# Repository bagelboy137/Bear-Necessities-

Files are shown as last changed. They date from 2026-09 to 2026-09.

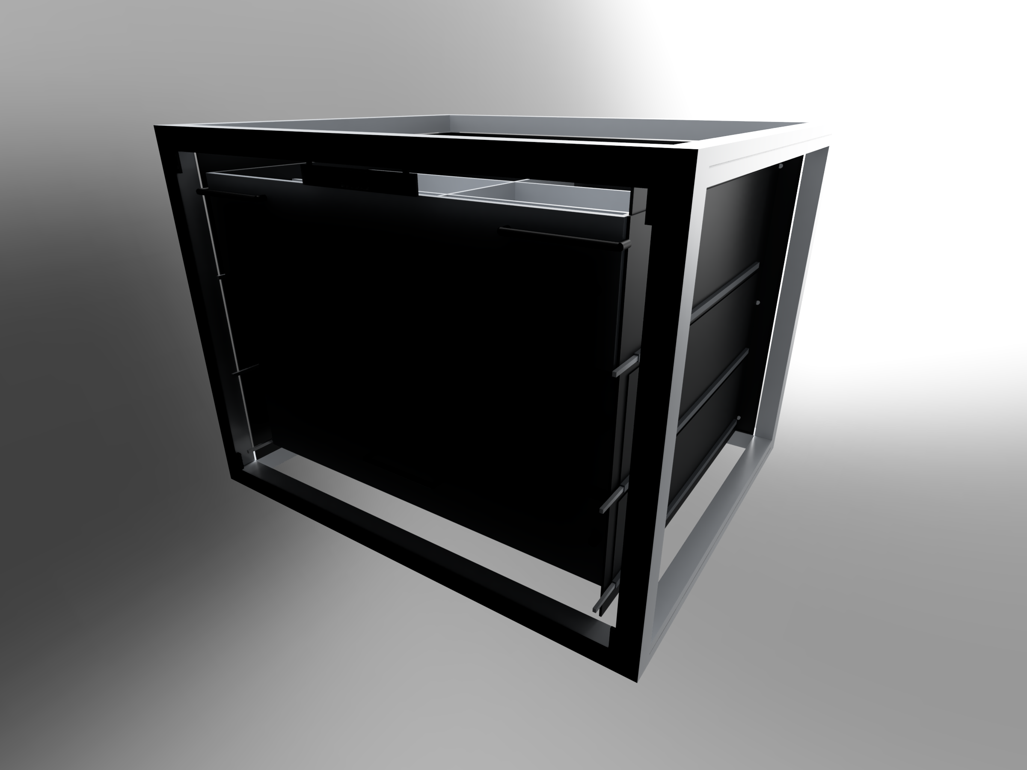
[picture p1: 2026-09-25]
Mac Mini Setup/tools/cad-product-agent/production/ten-modules/visual/renders/BN-M02-hero.png

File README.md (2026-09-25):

# Bear-Necessities-
Repo for code for the CAD and business to start up Bear Necessities

A Modular Overland Camp System: bolt-together 1" aluminium extrusion modules
(24"W × 20"D × 18"H) for vehicle camping. Product notes, BOM and build plans are
in `Bear Necessities/`; its `CLAUDE.md` is the best place to start.

## Layout

The three folders keep the same layout they have on the Mac, because the build
finds them relative to each other:

| Folder | What it holds |
|---|---|
| `Bear Necessities/` | The product: build-plans pack, BOM, custom parts, marketing images, and `cad/`, the build front door |
| `Fusion CAD Agent/` | `bncad`, the spec → local model → CadQuery → measure → repair framework, plus part specs and the Fusion bridge |
| `Mac Mini Setup/tools/cad-product-agent/` | The ten-module study: jobs, exports, and the deterministic gates |

## Running it in the cloud (Claude Code on the web)

`.claude/hooks/session-start.sh` runs at the start of every cloud session. It
installs `bubblewrap` (the Linux sandbox for model-written code) and builds the
CadQuery venv at `Fusion CAD Agent/.venv-cq` with `uv`. Once that's done:

```bash
cd "Bear Necessities/cad"
python3 preflight.py --for cad   # readiness check
./build.sh test                  # framework tests + bncad self-tests
./build.sh validate              # all four deterministic gates
```

Both run fully in the cloud: no model, no Fusion, no network.

`./build.sh parts` (building parts from specs) needs an LLM server with an
OpenAI-compatible API. There are two ways to get one.

**Run one in the cloud container.** `cloud-model.sh` installs Ollama, starts it
and pulls a coder model, then prints the build command:

```bash
cd "Bear Necessities/cad"
./cloud-model.sh                 # qwen2.5-coder:7b by default, about 4.7 GB
BN_LM_STUDIO_URL=http://127.0.0.1:11434/v1 \
BN_REVIEWER_MODEL=qwen2.5-coder:7b \
./build.sh parts
```

Ollama itself installs from GitHub releases, which the default network policy
allows. The model weights need `registry.ollama.ai` and the Cloudflare storage
it redirects to (`*.r2.cloudflarestorage.com`) allowed in the environment's
Network access settings. Network changes take effect in new sessions. The
container is CPU-only, so expect minutes per part rather than the Mac's ~30 s.

**Or point it at a server you run elsewhere**, via LM Studio's variable
(Ollama's `/v1` endpoint works there too), naming a model it has loaded:

```bash
BN_LM_STUDIO_URL=http://your-host:1234/v1 \
BN_REVIEWER_MODEL=qwen2.5-coder-7b-instruct \
./build.sh parts
```

The environment's network policy must allow that host. Anything using Fusion
(`native`, `visuals`, `--fusion`) needs the desktop app and only runs on the Mac.

## Running it on the Mac

Unchanged from before: see `Bear Necessities/cad/README.md` and
`Mac Mini Setup/Setup-Checklist.md` §7d. On macOS, bncad uses `sandbox-exec`.

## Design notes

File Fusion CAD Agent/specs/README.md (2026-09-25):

# specs/

One file per part: the brief the model works from. A vague brief is the #1 cause of a wrong model, and a local model will not push back — it will confidently build the wrong thing.

## Template — copy this

```markdown
# Part: <name>

**Purpose:** what it does and what it mounts to
**Project:** e.g. Escalade Work
**Status:** draft | modelled | printed/fabricated | installed

## Envelope
- Overall max: L × W × H
- Material: e.g. 6061 aluminium, 6 mm plate / PETG print
- Process: 3D print | laser cut | CNC | hand-fabricated

## Interfaces (the dimensions that must be exact)
| Feature | Dimension | Tolerance | Why |
|---|---|---|---|
| Bolt pattern | 2 × M8 @ 60 mm centres | ±0.2 mm | matches existing chassis holes |

## Loads / constraints
- What it carries, in what direction, and what it must not interfere with.

## Explicitly free
- Everything the model may decide on its own (fillet radii, cosmetic chamfers, rib layout).

## Reference
- Photos, measurements, links to the parent project's notes.
```

## Rule of thumb
If a dimension matters, it goes in **Interfaces** with a tolerance. If it doesn't, put it in **Explicitly free** so the model stops guessing at what it's allowed to touch.

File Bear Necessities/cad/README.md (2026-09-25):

# Bear Necessities — CAD build front door

This folder is the entry point for building the module family. It holds no
geometry of its own; it resolves where everything lives and drives it.

Run `./build.sh` from here on **either machine**. Nothing in this folder assumes
a home directory or a machine — every machine-specific value comes from
`runtime.json` or a `BN_*` environment variable.

## Where the pieces actually live

| Thing | Path | Owner |
|---|---|---|
| Product decisions, BOM, custom parts | `Bear Necessities/product/` | this project |
| Ten-module study, jobs, exports, gates | `Mac Mini Setup/tools/cad-product-agent/production/ten-modules/` | Mac Mini Setup |
| Orchestration framework | `Mac Mini Setup/tools/cad-product-agent/` | Mac Mini Setup |
| CadQuery/Fusion bridges, specs, venvs | `Fusion CAD Agent/` | Fusion CAD Agent |
| Local model roster and roles | `Mac Mini Setup/tools/local-ai/model-profiles.json` | Mac Mini Setup |

The study currently lives under `Mac Mini Setup` even though it is Bear
Necessities product data. That is backwards, but moving ~200 tracked binary
artifacts is a separate decision — this front door exists so the location can
change without every command changing with it.

## Commands

```bash
python3 preflight.py            # what would fail if I built right now?
./build.sh test                 # framework test suites (19 tests)
./build.sh validate             # deterministic gates only: no model, no Fusion
./build.sh parts                # build parts from JSON specs (needs a local model)
./build.sh revision             # local-model review cycles (needs LM Studio)
./build.sh native               # rebuild native Fusion family (needs Fusion + LM Studio)
./build.sh all                  # revision, then native, then validate
```

`preflight.py --for cad|revision|native|all` scopes the check to what a given
stage actually needs, and `--json` makes it machine-readable for a scheduled run.

## The three build paths, by what they require

| Path | Needs | Runs unattended |
|---|---|---|
| `test` | the project CadQuery venv | yes |
| `validate` | Python only | yes |
| `parts` | a local model (LM Studio or Ollama) | yes |
| `revision` | LM Studio + the `cad-review` model | yes |
| `native` | the above **plus** Fusion running with its MCP server | no — Fusion must be signed in and open |

`validate`, `revision` and `parts` are the overnight-safe paths - `parts` builds
real solids headlessly through CadQuery, which is why it does not need Fusion.
Framework and part specs live in `../Fusion CAD Agent/bncad/`; read its README's
units section before sending any STEP to a supplier. `native` is not: Fusion's
MCP server at `127.0.0.1:27182` only exists while the app is running, which is
the single biggest constraint on making the mini fully autonomous.

## Running on the Mac mini

The same checkout works unchanged if the layout is preserved. If it is not:

```bash
export BN_CLAUDE_ROOT=/path/to/Claude
export BN_REVIEWER_MODEL=qwen/qwen3-coder-30b   # only after it beats the 14B on this fixture
./build.sh all
```

Preflight prints the models LM Studio actually has loaded when a required one is
missing, so a roster mismatch is a one-line diagnosis rather than a stack trace.

## Which interpreter

`build.sh test` uses the project venv (`Fusion CAD Agent/.venv-cq`, Python 3.12)
because the suites import `cadquery` and `ezdxf`. Running them with the system
`python3` — 3.9 from Xcode on this laptop — drops the drawing tests to an import
error that reads like a skip. `preflight.py --for cad` checks that venv exists and
prints the exact command to create it if it does not.

## Resumability

The revision loop writes one validated file per cycle and reuses it on the next
run. An interrupted 30-cycle sweep resumes where it stopped — it does not restart.
That matters: a full sweep is 300 module reviews through a local model.

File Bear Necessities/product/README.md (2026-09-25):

# Modular Overland Camp System — Off-The-Shelf Build Package

Everything here targets one goal: **drop-ship from an aluminium extrusion supplier with as close to zero custom fabrication as possible.**

## What's here
| Path | What |
|---|---|
| `bom/catalog.json` | Hand-verified off-the-shelf parts. Real part numbers. |
| `bom/make_bom.py` | Generates the BOM. `--csv` for supplier quotes. |
| `bom/bom-single-module.csv` | BOM for one module frame |
| `drawings/base-frame-ots.step` | The frame, built from catalog extrusion |
| `drawings/C-01-anchor-plate-FLAT.dxf` | The one custom part, laser-ready |
| `custom-parts/` | Custom part specs and the rationale for keeping the list short |

## The headline result: two cut lengths

A 24 × 20 × 18" outside cube in 1" profile needs only **two distinct cut lengths**:

| Cut | Qty | Role |
|---|---|---|
| **18"** | 8 | 4 vertical posts + 4 depth rails |
| **22"** | 4 | 4 width rails |

Posts and depth rails come out the same length (18" height; 20" depth − two 1" profiles = 18"). One saw setup covers 8 of the 12 pieces. **That is the cheapest order you can place with a cut-to-length supplier**, and it falls straight out of the 24/20/18 proportions on the product sheet — worth preserving in any redesign.

Total extrusion: 232" = 19.33 ft per module frame.

## Bill of Materials — one module frame

| Part | Cut | Description | Vendor | Qty |
|---|---|---|---|---|
| 1010-S | 18" | 1"×1" smooth T-slot profile | 80/20 | 8 |
| 1010-S | 22" | 1"×1" smooth T-slot profile | 80/20 | 4 |
| 4132 | — | 10 Series 2-hole gusseted inside corner bracket | 80/20 | 24 |
| 3395 | — | 10 Series 10-32 anchor fastener | 80/20 | 48 |

Part numbers verified 2026-08-20 against 8020.net. **Prices are deliberately blank — get a live quote.**

### Sourcing note
**TNUTZ EX-1010** is stated 100% compatible with 80/20 1010-S, cuts to length, ~48h turnaround. Most 80/20 distributors don't stock — they drop-ship and take margin, so going direct to a cutting distributor is likely both cheaper and faster.

## Custom parts: exactly one, and it's flat

Everything structural is catalog. The only thing with no off-the-shelf equivalent is the **LOCK** step from your product sheet — and that's also the actual IP.

**C-01 Module Anchor Plate** — 4.000 × 1.500 × 0.250", laser cut from 5052 aluminium, 2 mounting holes + 1 pin hole, 0.25" corner radii. Verified: volume 1.4417 in³ against an analytical target of 1.4417 in³.

Design rule applied throughout: **every custom part must be a flat plate cuttable from sheet.** No bends, no machining, no welds. Flat parts quote instantly from a DXF and dozens of shops can make them. The moment a part needs a bend, cost and lead time jump and drop-ship gets harder.

**The pin is not custom** — use an off-the-shelf 1/4" ball-lock quick-release pin.

## The open question that actually blocks drop-ship

**C-02, the vehicle floor bracket, is vehicle-specific** and I have not designed it. Every vehicle has a different tie-down pattern. Three options, all product decisions rather than CAD ones:
1. Ship undrilled, customer drills — simplest, worst experience
2. Vehicle-specific SKUs — best fit, inventory complexity
3. Universal slotted pattern — one SKU, compromised fit

This is the biggest unresolved issue in the drop-ship model. Everything else is orderable today.

## Also unresolved
- Panels, handles, drawer slides, levelling feet are all listed as "off-the-shelf" but **not yet sourced to specific part numbers** (see `_unverified_still_to_source` in `catalog.json`).
- Material thickness and pin diameter on C-01 are assumptions until a load case is defined. What's the worst case — a loaded fridge module in a hard stop?

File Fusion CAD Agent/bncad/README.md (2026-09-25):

# bncad — local-model CAD, headless first, Fusion when it's open

Describe a part in a JSON spec, and a model running on this machine writes
CadQuery, builds a real solid, gets measured, and repairs itself until the
numbers match. No Anthropic API in the loop. No cloud.

```bash
cd "Fusion CAD Agent"
.venv-cq/bin/python -m bncad doctor           # what works right now
.venv-cq/bin/python -m bncad build P01-plate  # generate, validate, export
```

## Why CadQuery is the workhorse and Fusion is the finisher

Fusion is the preferred design environment and that has not changed. It just
cannot be the thing that runs unattended:

| | CadQuery | Fusion |
|---|---|---|
| Headless | yes | **no** — no headless mode exists |
| Needs a GUI session | no | yes, signed in |
| Available at 3am | yes | only if the app is still up |
| Survives an hour at full tilt on 16 GB | yes | **no** — crashed mid-batch 2026-08-26 |
| Parametric feature tree | no | yes |

So CadQuery builds and measures the geometry unattended, and Fusion picks up the
STEP when it is running. `bncad build --fusion` does the handoff and, usefully,
**measures the same STEP in both kernels** — if CadQuery and Fusion disagree
about a file, the file is the problem, not either kernel.

## The loop

```
part spec (JSON)
      ↓
local model (LM Studio or Ollama)  →  CadQuery script
      ↓
AST guard          rejects dangerous code with a message the model can fix
      ↓
sandbox-exec/bwrap writes confined to the run dir, network denied
      ↓
STEP on disk  →  measure  →  check against the spec
      ↓                            ↓
      ↓                    errors with real numbers
      ↓                            ↓
   PASS: export           model repairs those specific numbers, retries
```

The repair signal is the whole design. `"Volume is 0.2255 in^3, expected 0.1963
in^3 (+0.0291 off, tolerance +/-0.0040). Too much material..."` converges.
`"invalid"` does not — a 30-cycle sweep in this project once died because a
check said only "length/type invalid" and the model, not knowing it was 27
characters over, guessed and came back longer. **Every failure message here
carries the measured value, the wanted value and the delta**, and a test
enforces that.

## Units - read this before trusting any file

**CadQuery always writes `SI_UNIT(.MILLI.,.METRE.)` into a STEP.** There is no
exporter option for it, and setting OCCT's `write.step.unit` silently does
nothing. So a part authored with the numbers `4.0 x 1.5 x 0.25` inches produces
a file that every correct reader interprets as **4.0 x 1.5 x 0.25 millimetres**.

This is not theoretical. The first Fusion handoff imported a validated C-01
anchor plate and Fusion reported it as **0.157 x 0.059 x 0.010 in** - the part
25.4x too small. CadQuery said the geometry was perfect, and it was; the file
just claimed the wrong units. A supplier's CAM would have read it the same way,
and nothing else in the pipeline would have objected.

So bncad separates *authoring* from *delivery*:

| File | Units | Role |
|---|---|---|
| `_work-<id>/<id>-authored.step` | the spec's numbers, mislabelled | what the model wrote |
| `<id>.step`, `<id>.stl` | **real millimetres** | the deliverable, and what gets measured |
| `<id>-REJECTED.step` | millimetres | the closest attempt of a run that **failed**. Never send this |

A file named `<id>.step` exists only when that part passed. A failed run writes
`-REJECTED` instead, and a later passing run clears it — so a name without a
suffix always means "this met its spec".

`measure(step, scale=25.4)` reads the millimetre file and returns inches, so the
checks compare like with like. **The file that is validated is the file that
leaves the building** - the alternative is validating one artefact and shipping
another, which is how this project ended up with a green report over a stale
gate once already.

`bncad check` applies the spec's units automatically; pass `--raw` to check an
authored file whose numbers are already in the spec's units.

A spec's `"units"` may be `in`, `mm`, `cm` or `m`. An unknown unit is refused
rather than assumed.

## Part specs

One JSON file per part in `specs/parts/`. The same file feeds the prompt *and*
the validator, which is why adding a part no longer means writing a program.

```json
{
  "id": "P01-plate",
  "name": "two-hole flat plate",
  "units": "in",
  "description": "A flat rectangular plate ... two mounting holes ...",
  "constants": {"LENGTH": 4.0, "WIDTH": 1.5, "THICKNESS": 0.25},
  "checks": {
    "bbox": [4.0, 1.5, 0.25], "bbox_tol": 0.01,
    "volume": 1.45558, "volume_tol": 0.01,
    "solids": 1, "valid": true,
    "holes": [{"d": 0.281, "count": 2}], "holes_exact": true
  },
  "notes": "Hole centres at x = -1.000 and x = +1.000, both at y = 0."
}
```

Available checks: `bbox` (exact overall size) and `bbox_tol`; `size_max` (must
fit inside an envelope) and `size_min`; `volume` and `volume_tol`; `solids`;
`valid`; `watertight`; `faces`; `center` and `center_tol`; `holes` and
`holes_exact`.

**An unknown key is refused, not ignored.** A spec written with `volumne` for
`volume` used to lose that gate in silence — a solid of 99 in³ with no holes at
all passed a spec that meant to check both, reporting zero errors. Loading now
fails and names the offending key.

A `holes` entry takes `d`, `count`, `tol`, `at`, `at_tol`, and either `through`
or `depth`:

```json
"holes": [{"d": 0.281, "count": 2, "at": [[-1.0, 0.0], [1.0, 0.0]], "through": true}]
```

`at` is the position **in the plane the hole's axis is normal to** — for a hole
drilled down Z, that is (x, y). Include it: two holes of the right diameter in
the wrong place change volume by exactly zero, leave the bounding box untouched
and satisfy `holes_exact`, so a mirrored or mis-spaced bolt pattern is invisible
to every other gate. It went unchecked until an audit found it, on a product
whose open blocker is a bolt pattern.

`through` compares the hole's depth to the bounding box along its axis, so it
only means anything where the material is **uniform** along that axis — a plate,
not an L-bracket, whose bounding box is the whole part. Use an explicit `depth`
for anything else. `bncad reference` picks the right one for you.

`size_max`/`size_min` are deliberately *not* called `bbox_max`/`bbox_min`:
`measure()` returns a `bbox_min` of its own meaning the minimum corner
**coordinate**, and a shared name would let a measured `[-2.0, -0.75, 0.0]` be
pasted into a spec as a "minimum size" that passes anything.

**Target numbers must be measured, not calculated in your head.** Every spec here
was checked against a reference solid built in `specs/reference/`, and a test
asserts each spec still validates its own reference. A spec with a wrong target
volume can never converge, and the model gets blamed for it.

### Adding a part

1. Write the spec's `id`, `name`, `description`, `units` and `notes`. Give
   `checks` a placeholder — `{"solids": 1}` is enough to load.
2. Build the shape once by hand in CadQuery and export an **authored** STEP
   (numbered in the spec's units) anywhere outside `specs/reference/`.
3. `python -m bncad reference <id> /path/to/authored.step`

   This converts it into the millimetre reference solid and prints the
   measurements **back in the spec's units**, ready to paste into `checks`.
4. Paste them in, re-run step 3 — it should say the spec matches.
5. `python -m bncad build <id>` — let the model reproduce it from the prose.

Use `reference`, not `check`, for step 3. Measuring a hand-exported STEP as
though it were a delivery divides every number by 25.4, which is the same units
trap in a new coat. `reference` also refuses to convert a file onto itself,
because doing so would rescale the reference by 25.4 on every run.

Step 5 is the real test of the *description*: if the model cannot get there from
the prose, a supplier will not either.

Add the hand-written builder to `specs/reference/build_references.py` as well.
That script rebuilds every reference solid from source and re-checks it against
its spec, so the references stay reproducible instead of becoming binaries
nobody can regenerate or adjust:

```bash
.venv-cq/bin/python specs/reference/build_references.py
```

## Providers

LM Studio (`:1234`) and Ollama (`:11434`), auto-discovered, both OpenAI-shaped.

```bash
python -m bncad models                       # everything live, on both
python -m bncad build P01-plate --model qwen2.5-coder-7b-instruct
python -m bncad build P01-plate --model ollama/qwen3:8b
```

`--model` takes a bare id or `provider/model`. `BN_MODEL` sets a default. A typo
fails immediately against the real roster instead of 90 seconds later with a 404.

Reasoning models (`qwen3`) return a scratchpad that often contains a *draft* code
fence. It is stripped before extraction, and the extractor takes the **last**
fenced block, because models sketch before they answer.

## Safety

Generated code is model-written Python running on a personal machine, so it gets
both a static guard and a real sandbox:

- **AST allowlist** — only `cadquery`, `math`, `json`, `OCP`. `subprocess`,
  `socket`, `shutil`, `os`, `eval`, `exec`, `open` and friends are refused *with
  a message the model can act on*, which is the point of having it as well as
  the sandbox.
- **`sandbox-exec`** — writes confined to that run's directory, network denied,
  enforced by the kernel. The child gets a `TMPDIR` inside its run directory so
  the profile never has to open up the shared system temp root. It did once, and
  the test suite escaped through it within a minute.
  On Linux (Claude Code on the web) the same guarantee comes from **`bwrap`**
  (bubblewrap): the filesystem is bound read-only, the run directory read-write,
  and every namespace — including the network — is unshared. There is no
  unconfined fallback on either platform; `doctor` blocks if the tool is missing.
- **Timeout** — a runaway boolean is killed and reported as a timeout, not a hang.

## Commands

| Command | Does |
|---|---|
| `doctor` | what works right now, and the exact fix for what does not |
| `models` | every model on every live provider |
| `specs` | the part library |
| `build <spec>` | the loop. `--fusion` hands off, `--attempts`, `--model`, `--keep` |
| `check <spec> <step>` | validate an existing STEP against a spec. `--raw` for an authored file |
| `reference <spec> <step>` | turn a hand-built STEP into the spec's reference solid, and print paste-ready measurements |
| `fusion <step>` | import into the live Fusion session and cross-check. `--units` |
| `bench` | score models across the spec library. `--repeat N` exposes variance |
| `selftest` | every module demo plus the suite — no model, no Fusion, no network |

## Running unattended

Verified against the conditions a scheduler actually imposes, not just a login
shell. What was found and fixed while checking:

- **`lsof` is not on a cron PATH.** It lives in `/usr/sbin`, so Fusion's
  port-discovery fallback silently returned nothing under a scheduled run - the
  exact failure the discovery exists to prevent, reappearing only where nobody
  was watching. It is now called by absolute path.
- **Two builds of the same part raced.** They share `_work-<id>`, which is
  cleared on entry, so the second run deleted the first run's files and the
  first died with `FileNotFoundError`. A lock now refuses the second run rather
  than letting them race.

  The lock is an **`flock`, held by the kernel** - not a pid written in a file.
  The first attempt at this did track a pid and "take over" when that pid looked
  dead, which had three separate problems on a machine that runs for months: two
  processes could both judge a lock stale, and the second would then unlink the
  first's *live* lock; a recycled pid made a dead lock look alive forever; and a
  SIGKILL or reboot left a file nothing would clear. `flock` has none of them -
  the OS drops it when the process dies, however it dies. Verified by SIGKILLing
  a build mid-run and immediately rebuilding the same part.
- **A relative interpreter path** failed with `execvp() ... No such file or
  directory` and was reported to the model as though it had written bad code.
- **`Path.resolve()` on a venv interpreter leaves the venv.** A uv venv's
  `bin/python` is a symlink to the base interpreter, so resolving it turned
  every `import cadquery` into `ModuleNotFoundError`. `abspath`, never
  `resolve`, for an interpreter.

### Exit codes

A wrapper can branch on these without parsing messages:

| Code | Means |
|---|---|
| `0` | success |
| `1` | the build ran and did not meet the spec, or a gate failed |
| `2` | configuration: no such model, no provider answering, unknown spec, unwritable output directory |
| `3` | busy: another build of this part is running in that output directory |

`3` is deliberately distinct from `1` — a scheduled run that collided with a
manual one has not failed, it has declined to race. `bench` re-raises rather
than scoring a busy part as a model failure: a scoreboard should never contain a
result for a part that was never built.

### What is bounded

- **Disk.** Each part's deliverables are overwritten by name on every run, so
  building the same parts nightly does not accumulate — measured constant across
  repeated runs. A failing run's `_work-<id>` survives for inspection and is
  cleared by that part's next build.
- **The per-run JSON.** ~2.7 KB for a two-attempt run, ~8 KB for a six-attempt
  one. It is capped by `--attempts`, not by how long the machine has been up.
- **Time.** Every model call and every sandboxed script has a timeout that
  actually fires — verified against a server that accepts a connection and never
  answers. Worst case for one part is `attempts × timeout`, so with the defaults
  (8 × 900s) a wedged model server costs two hours per part before the run gives
  up. **For a scheduled job, pass a short `--timeout`** — a healthy call takes
  seconds, so `--timeout 180` still leaves an enormous margin and caps a wedged
  night at 24 minutes a part. There is no separate total-budget flag: the two
  knobs already bound it, and a third would just be another number to get wrong.
- **CPU, even if this process dies.** The sandboxed child sets its own
  `ulimit -t` before exec. A subprocess timeout only works while the parent is
  alive; kill the loop mid-execution — jetsam under memory pressure is the
  realistic way — and the child was orphaned and spun at 100% CPU forever.
  Reproduced, then fixed, then re-tested by abandoning a child deliberately.

### Cron and launchd

Give it an absolute path and let it find everything else:

```bash
/path/to/Claude/Fusion\ CAD\ Agent/bncad.sh build C-01-anchor-plate >> /tmp/bncad.log 2>&1
```

Verified working under `env -i PATH=/usr/bin:/bin` with no TTY: doctor, a full
build, and Fusion port discovery. Output is line-buffered so a log file shows
progress rather than appearing hung.

## Running on the Mac mini

Nothing here hard-codes a home directory. The package resolves paths relative to
itself and takes machine-specific values from the environment:

| Variable | Default |
|---|---|
| `BN_SPEC_DIR` | `Fusion CAD Agent/specs/parts` |
| `BN_OUT_DIR` | `Fusion CAD Agent/exports/bncad` |
| `BN_MODEL` | first available model |
| `BN_LMSTUDIO_URL` | `http://127.0.0.1:1234/v1` |
| `BN_OLLAMA_URL` | `http://127.0.0.1:11434/v1` |
| `BN_FUSION_MCP_URL` | discovered — Fusion's port moves, so it is asked for, not assumed |

First build the CadQuery environment. **Use uv** - it fetches the interpreter as
well, and a fresh Mac has no system `python3.12` for the plain `venv` command to
run. This is how the working venv here was actually built:

```bash
uv venv --python 3.12 "Fusion CAD Agent/.venv-cq"
uv pip install --python "Fusion CAD Agent/.venv-cq/bin/python" cadquery
```

After that, the change is the model, not the code:

```bash
export BN_MODEL=qwen/qwen3-coder-30b
python -m bncad bench          # prove it beats the 14B on this fixture first
```

`bench` is how that claim gets settled with numbers rather than assumed from
parameter count.

### What is different on this laptop

16 GB, and macOS lets the GPU address only ~70% of it, so this is effectively an
11 GB machine for weights. The 14B (~8.3 GB) is the ceiling here. Fusion and a
large model should not be resident at once — the headless path avoids the
question entirely, which is the main reason it is the default.

## Tests

```bash
.venv-cq/bin/python -m bncad selftest
```

No model, no Fusion, no network — it runs unattended. What it covers:

- every spec validates its own reference solid
- every check is shown **rejecting** bad geometry as well as accepting good
- the units conversion, in both directions and on volume as well as length
- the guard refuses dangerous imports and calls
- the sandbox is proven to actually block an escape and deny the network,
  rather than merely intending to
- a harness fault is distinguished from a model error, in both directions

The count is deliberately not written down here — it went stale twice already.

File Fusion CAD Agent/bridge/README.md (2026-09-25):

# bridge/

The piece that closes the loop: gets a generated script **into** Fusion and gets the result **back out**.

Nothing is built here yet — this is the design.

## The problem
`Mac Mini Setup/tools/lm_studio_bridge.py` already handles *prompt → local model → file*. What's missing is *file → Fusion → result → back to the model*. Fusion's Python API only runs inside Fusion's own GUI process, so an outside process cannot simply invoke it.

## Option A — manual (zero build)
Drop the script into Fusion's Scripts folder, click Run, read the message box.

Good for prototyping. **Fails the actual goal** — an always-on mini that nobody is sitting in front of.

## Option B — watcher add-in (the real answer)
A Fusion **add-in** (not a script) that loads at Fusion startup and stays resident, polling a queue folder:

```
bridge/queue/    <- agent drops <job>.py here
bridge/running/  <- add-in moves it here while executing
bridge/done/     <- finished scripts
bridge/logs/     <- <job>.log: stdout, traceback, exported file paths
```

The agent writes a job, waits for the matching log, and reads success or traceback. That traceback is what makes iteration possible — a model that can see its own error fixes it far more often than one guessing blind.

### To resolve when building
- **Polling interval** — Fusion add-ins run on the UI thread; a tight poll will make the app sluggish. Use a timer/custom event rather than a blocking loop.
- **No `messageBox`, ever.** It blocks until clicked and would hang the queue permanently.
- **Crash recovery** — if Fusion dies mid-job, `running/` must be drained on next startup or that job is stuck forever.
- **Document state** — build into a fresh document per job, not whatever happens to be open.
- **Timeout** — a runaway script needs a ceiling.

## Recommendation
Prove the geometry works with Option A on the laptop first. Only build Option B once scripts are landing correctly — otherwise you're debugging two unproven systems at once.

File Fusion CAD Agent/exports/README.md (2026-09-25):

# exports/

Output geometry from the agent's runs — `.f3d`, `.step`, `.stl`, `.dxf`.

## Notes
- Fusion defaults to saving into the **cloud hub**, not the local disk. Exports must be written here deliberately via `design.exportManager`.
- Binary CAD files don't diff. Keep this folder small — the *spec* and the *script* are the real source of truth and both are text. Geometry here is a build artifact.
- If this folder grows large, add it to `.gitignore` rather than committing revision after revision of the same body.

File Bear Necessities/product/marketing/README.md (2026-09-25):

# Marketing image set — ten modules + six configurations

Generated 2026-08-26. **These are ours** — unlike `../reference/competitors/`, this
folder is safe to publish, commit, and put on the website.

Open `index.html` to review the whole set:

```bash
open "$HOME/Claude/Bear Necessities/product/marketing/index.html"
```

## What these are, and what they are not

Every image here is composed from the **native Fusion CAD exports** — the same F3D
assemblies that pass the four deterministic gates. Nothing is illustrated, painted,
or AI-generated. If you see a burner, a strap, a drawer slide or a water tank in one
of these, it exists in the model with a part number behind it.

The presentation layer — background, contact shadow, brand type — is added by
`visual/make_module_cards.py`. It does presentation only and invents no geometry.

What they are *not*: photographs. There is no prototype yet, so there is no photo to
take. These read as clean studio CAD, which is the honest register for a pre-prototype
product — and it is the same register Goose Gear uses for its module pages.

## Contents

### `modules/` — 10 modules × 3 files

| File | Size | Use |
|---|---|---|
| `BN-MXX-card.png` | 1600×1200 | Product page hero, 4:3 |
| `BN-MXX-square.png` | 1200×1200 | Site grid tiles, social |
| `BN-MXX-alpha.png` | 1240×1098 | Transparent cutout — compositing source |

The alphas are also the input to the configuration boards, so do not delete them.

| ID | Module | ID | Module |
|---|---|---|---|
| BN-M01 | Cook Station | BN-M06 | Recovery/Utility |
| BN-M02 | Dry Pantry | BN-M07 | Power Hub |
| BN-M03 | Fridge/Freezer | BN-M08 | Hot Water/Shower |
| BN-M04 | Sink/Wash | BN-M09 | Field Office/Camera |
| BN-M05 | Fresh Water | BN-M10 | Camp Furniture/Soft Goods |

Every module is 24" W × 20" D × 18" H.

### `configurations/` — 6 solver-validated boards

2400×1600 each. Plan view, side elevation, bay dimensions, and the real product
cutouts for the modules involved. Placements come from `config_solver.py` — none is
drawn by hand, and `configuration-render-report.json` carries the exact origins plus
a SHA-256 per image.

| Board | Modules | Class |
|---|---|---|
| `weekend-base.png` | M01 + M05 | SUV |
| `trail-kitchen.png` | M01 + M02 | SUV |
| `recovery-day.png` | M02 + M06 | SUV |
| `wash-up.png` | M01 + M04 | 5th-gen 4Runner or van — sink lid needs the headroom |
| `basecamp.png` | M01 + M02 + M03 + M05 | Van |
| `expedition.png` | M01 + M02 + M06 + M08 + M10 | Van |

The class column is not marketing copy — it comes from the deployment classification
in `OTS-AUDIT.md`. Keep it on the site; it is the honest constraint.

## Regenerating

```bash
cd "$HOME/Claude/Mac Mini Setup/tools/cad-product-agent/production/ten-modules"
"$HOME/Claude/Fusion CAD Agent/.venv-cq/bin/python3" visual/make_module_cards.py
"$HOME/Claude/Fusion CAD Agent/.venv-cq/bin/python3" configurations/render_configurations.py
```

Then re-copy both output folders here. `make_module_cards.py --selfcheck` verifies the
background keying still preserves interior highlights.

## Putting these on the website

The site currently ships placeholder CAD viewport captures at
`website/public/modules/BN-MXX.png`. Swapping in the squares is one command:

```bash
for i in 01 02 03 04 05 06 07 08 09 10; do cp "$HOME/Claude/Bear Necessities/product/marketing/modules/BN-M$i-square.png" "$HOME/Claude/Bear Necessities/website/public/modules/BN-M$i.png"; done
```

That has **not** been done — the website sync command refuses to publish until the
10-cycle/100-review ledger, the 40-image gate and a final confirmation all pass, and
that gate is Conor's to clear. The swap above only changes local files; publishing is
still a separate, gated step.

## Known limitation

The camera is identical across all ten modules — same angle, same distance. Good for
a comparison grid, repetitive as a set of individual hero images. A second camera
angle per module would fix it and needs Fusion, whose local render queue is wedged
(see `Memory.md`, 2026-08-26).

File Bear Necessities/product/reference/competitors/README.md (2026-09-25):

# Competitor reference — modular vehicle camp systems

Collected 2026-08-26 for private design reference.

**Copyright:** every image here is third-party product photography and remains the
property of the brand that shot it. Use it to inform BN designs and to argue about
proportions and mechanisms. **Do not** put any of it on the Bear Necessities website,
in a deck, or in anything published. The marketing render pipeline in
`../../../../Mac Mini Setup/tools/cad-product-agent/production/ten-modules/visual/`
exists to produce our own imagery for that.

Open `index.html` in a browser to review everything at once:

```bash
open "$HOME/Claude/Bear Necessities/product/reference/competitors/index.html"
```

Regenerate that page after adding or deleting images with `./make-index.sh`.

---

## The starting reference (Conor, 2026-08-26)

The Instagram photo Conor supplied is a Coastal Mountain Vanworks–style fridge
module: a **Dometic CFX chest fridge** carried on a **tilt/slide mount** with visible
gas-strut or lift arms, a **bamboo counter** above it, and a **drawer below**, all in a
black frame bolted to wall L-track.

That photo is not saved here — it arrived in chat, not as a file. Drop it in as
`_reference-conor-instagram.jpg` if you want it in the contact sheet.

The mechanism in it is the single most useful thing in this whole folder, so it gets
its own section below.

---

## The finding that matters: nobody reserves headroom above a chest fridge

BN-M03 and BN-M09 are currently classified van/truck-class because their top openings
need 14in of clear space above an 18in frame, and neither measured 4Runner has it
(`OTS-AUDIT.md`, `configurations/CONFIGURATIONS.md`).

**Every competitor here solves that by moving the fridge out of the bay instead of
reserving space above it.** Not one of them designs in overhead lid clearance:

| Brand | Mechanism |
|---|---|
| Coastal Mountain Vanworks | Fridge on lock-in/lock-out slides, cam-strapped; counter above lifts clear |
| Goose Gear | "Icebox 1/2 with top drawer" — fridge slides out from under a fixed deck |
| Tembo Tusk | Jumbo **side-pull** slide — fridge exits sideways out the rear door |
| Front Runner | Cargo/fridge slide tray, ~100% extension, mounts to any flat surface |
| Trail Kitchens | Galley with integrated fridge slide |

This is worth revisiting before accepting the van/truck-class classification as
final. A slide-out or tilt-out tray inside the existing 24×20×18 frame could pull
BN-M03 back into SUV class without breaking the family frame or swapping the chest
fridge — both of which `CLAUDE.md` explicitly forbids. It costs drawer-slide hardware
and rear-door swing clearance instead of vertical space.

Not a recommendation yet — it needs the fridge envelope checked against slide travel
and a real 4Runner tailgate measurement. But it's a route the current audit doesn't
consider.

## The second finding: Goose Gear's plate system is a third answer to C-02

C-02, the vehicle floor bracket, is framed in `CLAUDE.md` as a binary: ten per-vehicle
SKUs, or one universal L-track part that pushes an install step onto the customer.

Goose Gear ships a third shape. **One vehicle-specific "Plate System" per vehicle**, a
flat deck that bolts to that vehicle's factory tie-downs — and then *every* module in
their catalog is vehicle-agnostic and bolts to the plate. The per-vehicle engineering
is isolated in a single flat part; the modules never go obsolete.

That is very close to what BN already does well — flat plates cuttable from sheet —
and it means the per-vehicle part count is one plate, not one bracket per module per
vehicle. Adventure Wagon's L-track/A-frame system (also in this folder) is the
comparison case for the universal route.

---

## Brands captured

### coastal-mountain-vanworks
Closest competitor. Modular bolt-in cabinetry, extrusion frame with colored infill panels, bamboo tops, recessed round drawer pulls. Pullout cooler galley, powered cooler stand, 4-drawer galley, over-wheel water cabinet, drop-down outside table, countertop extension. — https://cmvanworks.com/campervan-products/

### goose-gear
The sharpest comp for SUV-class: modules sized to specific 4Runner generations. Flat cut-sheet panels with lightening holes, aluminum extrusion corners, per-vehicle rear plate system. Module footprints run 19in and 22in wide by 25/28/30/31.5in deep — BN's 24W × 20D is wider and much shallower. — https://www.goose-gear.com/

### trail-kitchens
Galley with integrated fridge slide, sink and faucet detailing. — https://trailkitchens.com/products/galley-with-fridge-slide

### adventure-wagon
The universal-mount thesis proven commercially: steel A-frame plus aluminum L-track, everything reconfigurable, sold as a DIY-installable kit. The comparison case for the C-02 L-track route. — https://adventurewagon.com/pages/interiorsystem

### alu-cab
Canopy camper and shadow awning; useful for opening-height and bamboo-surface detailing. — https://www.alu-cab.com/products/canopy-camper

### kanz-outdoors
Modular field kitchen with a leg system — the closest thing here to a free-standing deployed cook module. — https://kanzoutdoors.com/

### roam-adventure
Rugged cases with MOLLE panels, rigid mounts, and lid organizers. Reference for how a case-based system handles mounting and internal organization. — https://roamadventureco.com/

### tembo-tusk
Skottle cook system and the Jumbo **side-pull** fridge slide — the sideways-exit variant of the clearance solution. — https://tembotusk.com/

### drifta
Australian chuck-box / car-back camp kitchens. Thin capture — their site resisted scraping. — https://www.drifta.com.au/

---

## Gaps

Four brands could not be captured — their product pages are JavaScript-rendered and
returned only navigation chrome or 404s to a plain fetch:

- **Decked** (truck-bed drawer systems)
- **Front Runner Outfitters** (drawer systems, Wolf Pack, cargo/fridge slides)
- **Vandoit** (galley and storage modules)
- **BOXIO** (German bolt-together cube system — conceptually the closest of the four)

Front Runner's slide and BOXIO's cube stacking are the two worth going back for. They
need a real browser session rather than curl; say the word and I'll drive one.

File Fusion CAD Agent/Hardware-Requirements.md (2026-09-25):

# Hardware Requirements — for `Mac Mini Setup`

What this project needs from the mini. **`Mac Mini Setup` owns the purchase decision; this file is input to it, not a competing plan.**

## The change this project forces

`Mac Mini Setup` currently targets **32GB**, sized on the assumption that the mini runs *a local coding model* plus Claude Dispatch. This project puts **Autodesk Fusion on the same machine at the same time**, which the 32GB math did not account for.

| Resident at once | Rough footprint |
|---|---|
| Coding model, 30B-class at Q4 (e.g. Qwen3-Coder-30B) | ~19GB (**estimate was high — see measured table below**) |
| Coding model, 24B-class at Q4 (e.g. Devstral-24B) | ~14GB |
| Autodesk Fusion 360, non-trivial assembly open | several GB, grows with model complexity |
| macOS + Dispatch + the rest | a few GB |

**Verdict: 32GB is the floor, not the target.** It works with a 24B model and a simple part. It gets tight with a 30B model and a real assembly. If the budget stretches, **48–64GB** is the config that makes this comfortable — and per `Mac Mini Setup`, unified memory is *not* upgradeable after purchase, so this is a one-shot decision.

This does not by itself justify jumping to a Mac Studio. It does mean: re-run the 32-vs-64 comparison before buying, with this workload in the model.

## Measured update, 2026-08-26 — cores matter more than the memory math suggested

The marketing-render sweep was built and run, and it measures the Fusion side of
this machine directly. Full evidence in
`Mac Mini Setup/tools/cad-product-agent/production/ten-modules/visual/HARDWARE-FROM-THIS-JOB.md`.

The memory reasoning above is unchanged and still correct **for the coding
model**. But for rendering:

- **Rendering is core-bound, not memory-bound.** Fusion's ray tracer runs at
  ~900–975% CPU — about 9 of 10 cores — while free memory sits at 75–81% of
  16 GB. The whole render path peaks around 3 GB.
- **A render takes 120–240 s** at 2400 × 1800, quality 75. The full ten-cycle
  sweep is ~13.5 h on 10 cores, ~10 h on 14. Overnight either way.
- **Fusion and a local model cannot share the GPU.** Both are Metal-based; with a
  3 B model resident, renders fire and never complete. This is scheduling, not
  capacity — **more unified memory does not fix it**, so do not buy RAM expecting
  to run Fusion and a model concurrently. The sweep sequences them instead.

**Revised recommendation: M4 Pro with the 14-core CPU upgrade, 48 GB.** The core
upgrade is what shortens this job; the 48 GB is still for the coding model, as
argued above. 32 GB remains the floor. This does not change the "not a Mac
Studio" verdict.

## Measured model footprint, 2026-08-26 — the estimates above were high

Read from the actual MLX 4-bit repo rather than estimated. This file said ~19GB
and `Software-Requirements.md` said ~17GB; they disagreed and both were high.

| Item | Real number |
|---|---|
| `Qwen3-Coder-30B-A3B-Instruct-MLX-4bit` weights | **16.0 GiB** |
| KV cache @ 8k / 16k / 32k ctx (fp16) | 0.75 / 1.50 / **3.00** GiB |
| KV cache @ 128k ctx (fp16) | 12.0 GiB |

Architecture: `qwen3_moe`, 48 layers, 128 experts with 8 active per token,
4 KV heads. All experts stay resident — 30B-sized in memory, 3B-sized in compute.
The narrow KV cache (4 KV heads) is why long context is affordable here.

**Coding model at 32k context = ~19 GiB total.** Against ~45 GiB addressable on
a 64GB machine, memory is not the binding constraint for this workload.

### What this means for 48GB vs 64GB

The "Fusion and the model are co-resident" framing overstates the case, because
the GPU-contention finding below means they must be **sequenced** for rendering
anyway — and sequenced, peak memory is `max(model, Fusion)`, not the sum.

The real 64GB argument is model-plus-model, not model-plus-Fusion:

| Scenario | Need | 48GB (~34 GiB) | 64GB (~45 GiB) |
|---|---|---|---|
| Coder @ 32k + vision | ~26 GiB | fits | fits |
| Coder @ 128k + vision | ~35 GiB | **exceeds** | fits |

64GB buys long-context agentic coding with the vision model co-resident, and
headroom that cannot be added later. That is a narrower claim than this file
previously made, and it is the one that survives the measurements.

### Still unmeasured: Fusion *open* but not rendering

The contention below was measured against Fusion's **ray tracer**. The actual
CAD agent loop — Fusion executing Python API scripts, viewport only — has never
been tested with a model resident. That is the case that matters most for daily
use and it is still an assumption. Testable on the laptop today with
`bonsai-27b` (7.94 GiB, known to load) and a real assembly open, no rendering.

## Non-memory requirements

- **GUI session, always logged in.** Fusion has no headless mode on macOS — it must be running in a real desktop session. Already compatible with the existing decisions (FileVault off, auto-login, unattended reboot recovery).
- **Network access.** Fusion requires periodic Autodesk sign-in and defaults to cloud storage. An air-gapped mini cannot run Fusion for long. The *model* is offline; the CAD app is not.
- **Disk.** Fusion plus its cache, plus a local model library, plus exported geometry. The existing plan (512GB internal + external Thunderbolt SSD as needed) still holds, but Fusion pushes toward using that external sooner.
- **Display.** Fusion wants a display attached or a virtual one; a fully headless mini may need a display emulator dongle for the GPU/window server to behave. **Still unverified, and now load-bearing:** the render sweep cannot run unattended at all if a headless mini will not drive the window server. Test this on day one.

## Action for October
Before buying, re-check: 32GB vs 48/64GB pricing, whether the M5 mini has landed (it may offer a better memory tier at the same price), and whether Fusion runs acceptably on a mini with no physical display.

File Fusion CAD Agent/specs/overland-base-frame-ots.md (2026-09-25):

# Part: Base Frame — OFF-THE-SHELF BUILD

**Purpose:** the shared cube chassis for all six modules, built entirely from catalog 80/20 parts so it can be drop-shipped from an extrusion supplier with zero custom fabrication.
**Status:** draft

## Envelope
- Overall: **24"W × 20"D × 18"H** OUTSIDE
- Material: **80/20 10 Series, part 1010-S** (1" × 1" smooth T-slot). TNUTZ EX-1010 is an equivalent.

## Construction — post and rail
12 members, all 1" × 1" square cross-section:
- **4 vertical corner posts**, 18.000" long, at the four corners, running the full height
- **4 width rails**, 22.000" long, running along X, fitting BETWEEN the posts
- **4 depth rails**, 18.000" long, running along Y, fitting BETWEEN the posts

Rails sit at the very top and very bottom of the frame. Everything unions into one connected solid measuring exactly 24 × 20 × 18.

## Why these lengths
Posts are the full 18" height. Rails fit between posts, so each is the outside
dimension minus two 1" profiles: width rail = 24 − 2 = 22", depth rail = 20 − 2 = 18".
**Posts and depth rails are both 18", so there are only TWO distinct cut lengths.**

## Interfaces (must be exact)
| Feature | Dimension | Tolerance |
|---|---|---|
| Outside width | 24.000" | ±0.030" |
| Outside depth | 20.000" | ±0.030" |
| Outside height | 18.000" | ±0.030" |
| Profile | 1.000" square | — |

## Deliverable
STEP + STL of the assembled frame.

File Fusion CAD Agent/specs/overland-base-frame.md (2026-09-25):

# Part: Modular Overland Camp System — Base Frame

**Purpose:** the shared cube chassis every module is built on (cook, storage, fridge, sink, water, gear). Getting this one right defines all six.
**Project:** Bear Necessities (product) · CAD by Fusion CAD Agent
**Status:** draft

## Envelope
- Overall: **24"W × 20"D × 18"H** (outside dimensions)
- Material: **80/20 aluminium T-slot extrusion, 1010 series (1" × 1")**
- Process: cut extrusion + corner brackets, bolt-together

## Interfaces (must be exact)
| Feature | Dimension | Tolerance | Why |
|---|---|---|---|
| Outside width | 24.000" | ±0.030" | modules sit side by side in the vehicle |
| Outside depth | 20.000" | ±0.030" | must clear the tailgate |
| Outside height | 18.000" | ±0.030" | modules stack |
| Extrusion profile | 1.000" square | — | 1010 series |

## Structure
12 members forming a rectangular cube:
- 4 × horizontal width members
- 4 × horizontal depth members
- 4 × vertical corner posts

Cut lengths must account for the 1" profile so **outside** dimensions land at 24 × 20 × 18.

## Explicitly free
- Corner bracket style, fastener callouts, cosmetic detail.

## Deliverable
A 2D technical drawing: **three orthographic views (front, top, right) plus a cut list**, in DXF.

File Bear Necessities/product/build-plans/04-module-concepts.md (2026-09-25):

# 04 — The ten module concepts

Ten ways to use the frame. **This file is design reference, not build
instructions.** Every module is a concept CAD assembly with an off-the-shelf
appliance chosen for it and an internal layout modelled for clearance — but every
one also has unresolved custom parts, missing SKUs, or engineering holds. Treat
these as "here's the idea and the direction," not "here's a kit you can order
complete."

Sources: the ten native Fusion concept assemblies, `module-family.json`
(envelopes, clearance, open items), and the per-module prototype BOMs. Where the
CAD provenance file and the prototype BOM disagree on the appliance pick, both
are noted.

---

## What every module shares

Beyond the frame (`01-frame-cut-list-and-bom.md`), each module concept also
carries these off-the-shelf items. Quantities are prototype allowances — trim to
your actual design.

| Item | Vendor / part | Qty per module | Status |
|---|---|---|---|
| Carry handle | TNUTZ `HAN-015-AL` (black aluminium, with 10 Series mounting hardware) | 2 | Orderable — **check stock**; handle is **not authorized for a loaded lift until tested** |
| Panel gasket | TNUTZ `GAS-010-A` (for ~3/16 in panels) | ~20 ft (allowance) | Orderable; final length from panel drawings that don't exist yet |
| Anti-skid tread | TNUTZ `BUM-010-TS` (rubber tread strip) | ~8 ft (allowance) | Orderable; verify vehicle-floor compatibility |
| Side/back panels | TAP Plastics King Hy-Pact, cut to size | 1 "cut-panel lot" | **Order only from released DXF panel drawings — those don't exist yet** |

Full details and URLs in `05-off-the-shelf-parts-catalog.md`.

---

## Deployment classes (from the project's fit work)

- **BN-M03** and **BN-M09** are **van / truck class**. Their top openings need
  ~14 in of clearance above the 18 in frame; neither measured 4Runner cargo bay
  has it.
- **BN-M04** fits a 5th-gen 4Runner but not the shorter 6th-gen.
- The other seven are SUV-class in principle, subject to your own wheel-well and
  tailgate measurement.

---

## BN-M01 — Cook Station

- **Purpose:** two-burner outdoor cooking and cookware storage.
- **Built around:** Jetboil Genesis Basecamp two-burner stove, UPC
  `0858941006274`. Status: orderable (verify current stock; propane bottle
  carried separately, outside the enclosed module). Packed envelope ~10.75 ×
  10.75 × 6.25 in.
- **Concept interior:** packed stove low in the bay on a pull-out tray; a
  deployable worktop shelf above it (~21.5 × 17.5 in).
- **Still open:** the flat worktop panel — material and food-contact finish not
  selected; hot-use clearances and windscreen deployment not tested; propane
  handling procedure. Drawer slides for the stove tray are a "verify load"
  placeholder.

## BN-M02 — Dry Pantry

- **Purpose:** sealed storage for packaged dry food and cookware.
- **Built around:** no validated container. The prototype BOM suggests Rubbermaid
  Commercial `FG350700WHT` 2-gal food-tote boxes (~18 × 12 × 3.5 in) ×3, stacked
  vertically — dealer-order, and matching lids must be sourced separately. The
  CAD provenance file records a Milwaukee PACKOUT box as the original pick,
  **rejected** for exceeding the 22 in clear width by 0.1 in.
- **Still open:** source a sealed container no larger than 21.5 W × 16 D × 11 H
  in with a lid that opens inside the frame; food-contact suitability applies to
  packaged food only. Three drawer-slide pairs are "verify load" placeholders.

## BN-M03 — Fridge / Freezer  *(van / truck class)*

- **Purpose:** 12 V top-opening cold storage, rides low and restrained.
- **Built around:** Engel `MD-14F` 15 qt — **manufacturer sold out**, carried at
  quantity zero. Prototype alternate: Engel `MHD13F-DM` (~17.5 × 11.3 × 14.5 in),
  status **orderable-alternate-verify** — envelope fits with margin, but Engel
  direct is sold out, a retailer's dimensional listing is self-contradictory, and
  the manufacturer positions this unit for EMS medication transport, not consumer
  food. Confirm intended use and warranty before buying.
- **Still open:** fridge availability; compressor ventilation path; 12 V fused
  wiring and strain relief; Engel `TSLPLATE` + `TSL17` transit slide-lock
  packaging. **Does not fit a 4Runner** — 14 in lid headroom.

## BN-M04 — Sink / Wash  *(5th-gen 4Runner / van; top access)*

- **Purpose:** cold-water hand and dish washing with contained grey water.
- **Built around:** Dometic VA8000-series square sink (prototype BOM cites
  `VA8005` / `9102303252`; the CAD provenance file marks the exact SKU as not
  released). Demand pump: Pentair Shurflo `4008-101-E65` 12 V 3 GPM — dealer
  order, engineering hold. Grey water: Reliance `9405-03R` 4-gal Aqua-Tainer,
  permanently labelled, never returned to potable use.
- **Still open:** exact sink SKU and its cutout drawing; food-safe faucet / hose
  / pump SKUs; leak tray and drain routing; a full plumbing design and leak test.

## BN-M05 — Fresh Water

- **Purpose:** seven gallons of removable potable water.
- **Built around:** Reliance `9410-03R` 7-gal Aqua-Tainer (~11.5 × 11.25 ×
  15.75 in). Status: dealer order (manufacturer no longer sells direct).
- **Still open:** **positive tank restraint for the ~58 lb full-water mass** —
  not designed, and it needs a dynamic load case; food-safe pump / hose SKU;
  drainable spill tray. The tie-down straps in the BOM (NRS, 500 lb published
  WLL) are marked "module anchor / load path still requires engineering."

## BN-M06 — Recovery / Utility

- **Purpose:** weather-sealed recovery gear and tools, fast access.
- **Built around:** Pelican `1450-000-110` Protector case with foam (prototype
  BOM, orderable). The CAD provenance file's original pick was a Milwaukee
  PACKOUT, **rejected** for width.
- **Still open:** a payload-specific divider plan; the purchased case does not
  validate the module frame or its retention. One drawer-slide pair is a "verify
  load" placeholder.

## BN-M07 — Power Hub

- **Purpose:** portable AC / DC / USB power and cable storage.
- **Built around:** EcoFlow RIVER 3 Plus, 286 Wh portable power station
  (~9.2 × 9.1 × 5.75 in packed). Status: orderable. Keep manufacturer-required
  ventilation and all ports accessible.
- **Still open:** a ventilation / open-area calculation; cable pass-through
  grommets; charging access while restrained; electrical labelling. **The module
  is not a certified electrical enclosure** — do not treat it as one.

## BN-M08 — Hot Water / Shower

- **Purpose:** portable propane water heating and a shower.
- **Built around:** Joolca HOTTAP V2 Essentials kit (~17.7 × 11.4 × 6.6 in,
  transported horizontally). Status: orderable.
- **Safety (from the source design):** **never operate the heater inside the
  vehicle or the module.** It is transported in the module and deployed and run
  **outdoors only.** Propane bottle carried separately.
- **Still open:** the US kit SKU; hose restraint and a drying / ventilation path
  for wet storage.

## BN-M09 — Field Office / Camera  *(van / truck class)*

- **Purpose:** protected electronics / camera transport that unfolds into a
  trail-side work surface.
- **Built around:** Pelican `1485 Air` case with configurable foam (~19.2 × 13.0
  × 6.9 in). Status: orderable.
- **Still open:** a flat retention plate to hold the case; work-surface hinge /
  latch SKUs; laptop thermal management if operated in the module. Worktop
  headroom means it **does not fit a 4Runner**.

## BN-M10 — Camp Furniture / Soft Goods

- **Purpose:** chairs, table, awning accessories, soft gear — one-piece access.
- **Built around:** customer-selected soft gear. The prototype BOM fits Helinox
  Chair One ×2 and Table One ×1 in the concept bay; the CAD provenance file
  leaves the product set to the customer.
- **Still open:** the target chair / table set; cargo-net SKU; compression-strap
  SKU; a payload and centre-of-gravity target. Four tie-down straps in the BOM
  carry the standard "load path requires engineering" note.

---

## The honest read on the modules

None of the ten is a finished, orderable build. The frame under all of them is
the resolved asset; the interiors range from "one orderable appliance plus a
custom worktop and a hot-use test" (M01, M07, M08) to "the main component isn't
even sourced yet" (M02, M04, M06, M10). If you buy this pack, you are buying the
frame plus a well-researched starting point for whichever interior you want to
build — not a kit.

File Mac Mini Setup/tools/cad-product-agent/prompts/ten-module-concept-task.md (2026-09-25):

Design ten distinct modules for the Bear Necessities Modular Overland Camp System.

Reference image facts: the product family uses interchangeable 24 inch wide x
20 inch deep x 18 inch high rectangular frames made from silver 1 x 1 inch
T-slot aluminum extrusion. The image shows cook, storage, fridge, sink, water,
and gear/utility examples, with dark infill panels, drawers/shelves, carry
handles, and vehicle locking pins. Modules slide into an SUV and are removable.

Hard manufacturing constraints:
- Preserve the common 24 W x 20 D x 18 H external envelope.
- Preserve the frame cut strategy: 1010-compatible extrusion, eight 18 inch
  pieces and four 22 inch pieces per outer frame. Do not invent part numbers.
- Prefer supplier cut-to-length extrusion and commercially orderable hardware.
- Custom fabricated parts must be flat laser/waterjet-cut sheet with no bends,
  welds, or machining unless explicitly flagged as a production blocker.
- Catalog part numbers will be independently curated; name component categories,
  performance requirements, dimensions, and quantities instead of guessing SKUs.
- Account for rough-road vibration, tie-downs, ventilation, water containment,
  hot surfaces, payload, center of gravity, service access, and lift-out weight.
- Do not claim structural or regulatory approval.

Return strict JSON with one top-level object containing:
- `family_assumptions`: array
- `modules`: exactly 10 objects, each with `id`, `name`, `customer_job`,
  `configuration`, `frame_extrusion` (18-inch quantity and 22-inch quantity),
  `off_the_shelf_components` (name, quantity, key_specification),
  `custom_parts` (name, quantity, flat_sheet_possible, reason),
  `critical_interfaces`, `safety_checks`, `estimated_payload_lb`,
  `estimated_empty_weight_lb`, and `production_blockers`
- `shared_components`: array
- `design_rules_learned`: array of concise rules suitable for adding to an
  automated CAD planning prompt
- `recommended_build_order`: all ten module IDs in test priority order

Make the ten concepts meaningfully different and commercially useful. Include
the six pictured functions but improve them where appropriate, then add four
complementary products. Keep every claim conservative and manufacturable.

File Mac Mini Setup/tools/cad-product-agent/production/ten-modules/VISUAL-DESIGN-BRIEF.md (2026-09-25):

# Visual completion brief — native Fusion rebuild

The reference image establishes a common silver 1-inch extrusion frame with dark
infill panels and recognizable functional equipment. Comparable products add the
details below. These are visual/functional precedents, not copied geometry.

## Family visual language

- Twelve separate silver extrusion members with visible dark slot lines.
- Dark charcoal side/back panels, black mounting hardware, rounded pull handles,
  visible fasteners and a small front module ID plate.
- Functional equipment must be recognizable from an isometric screenshot without
  reading the filename.
- Keep the 24W × 20D × 18H outer frame and 22W × 18D × 16H clear region.
- Each model is a native multi-component Fusion document, not one fused body.

## Comparable-product cues carried forward

- Overland Kitchen EX1: enclosing fridge cabinet, dual lock-in/out slides,
  ventilation slots, drain/service access and vehicle strap/bolt patterns.
- Goose Gear CampKitchen: independently moving stove/fridge slides.
- OVS Mid-Size Kitchen: separate cooking, prep and sink layers; removable basin,
  wind guard, tie-down straps and anchor points.
- Lone Peak / AT Overland drawers: divided drawers, textured dark finish,
  full-extension guides and locking compression latches.
- MODULR/OVS utility systems: precision-cut MOLLE pattern and adjustable shelf.
- Tailgate Gear kitchen: aluminum-profile frame, Dibond panels, foldable faucet,
  water pump, collapsible basin, lockable sliders and gas restraint.

## Required visible content by module

1. **BN-M01 Cook Station** — pull-out stove tray, two burners, control knobs,
   three-sided wind guard, upper prep surface, lower cookware drawer and handle.
2. **BN-M02 Dry Pantry** — three pull-out drawers of different heights, front
   handles/latches, internal divider indication and full side/back panels.
3. **BN-M03 Fridge/Freezer** — compact top-opening fridge body, lid seam, front
   carry handle, compressor vent array, restraint straps and low slide tray.
4. **BN-M04 Sink/Wash** — recessed basin, raised/foldable faucet, drain, grey-water
   tank, pump, visible hose route, splash panel and lower service door.
5. **BN-M05 Fresh Water** — blue seven-gallon tank, fill cap/spigot, two restraint
   straps, pump/service bay, hose and vented access panel.
6. **BN-M06 Recovery/Utility** — lower sealed tool drawer, upper shelf, perforated
   MOLLE panel, recovery-rope roll, shackles/tool silhouettes and latch.
7. **BN-M07 Power Hub** — power-station enclosure, front display, AC/round DC and
   USB port cues, ventilation slots, cable drawer and protected pass-through.
8. **BN-M08 Hot Water/Shower** — heater face with display/knobs/vents, coiled hose,
   shower head, quick-connect cues, wet-storage tray and explicit transport layout.
9. **BN-M09 Field Office/Camera** — rugged case with lid ribs/latches, deployable
   worktop, open laptop, cable pass-through and small accessory drawer.
10. **BN-M10 Camp Furniture/Soft Goods** — vertical folded-chair/table forms,
    rolled fabric cylinders, two compression straps and front cargo-net pattern.

## Visual QA

Every module must have its own 1200×900 isometric PNG. Review at least three
times: geometry/detail checklist, comparable-product cue checklist, and family
consistency/legibility. A screenshot consisting mainly of anonymous cuboids fails.

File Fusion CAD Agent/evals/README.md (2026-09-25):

# evals/

The purpose of this folder is to answer **one question with evidence instead of vibes: is a given local model good enough to be worth a $1,000+ machine?**

Run the same fixed set of prompts against each candidate model, score them the same way, and record it. Do this **before** October's purchase — the result decides both the model and the RAM tier.

## How to run one
```bash
python3 "../../Mac Mini Setup/tools/lm_studio_bridge.py" \
  --file eval-set.md \
  --model <model-id> \
  --output "results/<model>-<task>.py"
```
Then run the produced script in Fusion and score it.

## Scoring — per task
| Score | Meaning |
|---|---|
| 3 | Runs first try, geometry correct |
| 2 | Runs first try, geometry wrong or off-dimension |
| 1 | Errors, but self-corrects when handed the traceback |
| 0 | Errors and cannot recover, or hallucinates API methods |

**The bar that matters is not "can it write Python."** It's whether it knows the *Fusion API* specifically — most models write fluent Python and invent Fusion method names that don't exist. Score 0 is the expected failure mode.

## What to record per model
Model + quant, RAM used while loaded, tokens/sec, score per task, and total. Write it into `../Memory.md` so the purchase decision has real numbers behind it.

## Also run the control
Run the same set asking for **OpenSCAD** or **CadQuery** instead of Fusion API. If those score materially higher — likely, given training-data volume — the whole architecture should change to generate-and-import. That comparison is the single highest-value thing in this folder.

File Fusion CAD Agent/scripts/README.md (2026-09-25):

# scripts/

Fusion Python scripts — generated by the local model, and hand-written ones worth keeping.

## Layout
- `_template/` — the known-good skeleton. Copy the whole folder and rename **both** files to match the folder name; Fusion requires `<Name>/<Name>.py` + `<Name>/<Name>.manifest`.
- One folder per script, named after the part.

## Getting a script into Fusion
Fusion only sees scripts under its own support folder:

```bash
open ~/Library/Application\ Support/Autodesk/Autodesk\ Fusion\ 360/API/Scripts/
```

Copy or symlink a script folder there, then in Fusion: **Utilities → Scripts and Add-Ins → Run**. New folders may need a Fusion restart, or add them with the green `+` in that dialog.

Symlinking from this folder keeps the source under git while still letting Fusion run it:

```bash
ln -s "$HOME/Claude/Fusion CAD Agent/scripts/MyPart" ~/Library/Application\ Support/Autodesk/Autodesk\ Fusion\ 360/API/Scripts/MyPart
```

⚠️ Symlink behaviour with Fusion's script loader is **untested** — if it misbehaves, copy instead.

## Conventions
- Every dimension is a named constant at the top of the file.
- Every script comments its unit conversions (the API is in **cm**, always).
- Every script states its assumptions in a header comment.
- Scripts that will run unattended must **not** call `ui.messageBox` — it blocks forever with no one to click it.

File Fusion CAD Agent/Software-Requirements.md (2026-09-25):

# Software Requirements — laptop trial

Audited on this machine (Apple M1 Pro, 16GB, macOS 25.5) on 2026-08-20.

## Already installed — nothing to do

| Software | State |
|---|---|
| **Autodesk Fusion 360** | Installed. Versions `2703.1.20` / `2704.1.36` in the add-in cache. `API/Scripts/` and `API/AddIns/` exist and are empty |
| **LM Studio** | Installed, service runs, server live on port `1234` |
| **`lms` CLI** | `~/.lmstudio/bin/lms`, already on PATH via line 3 of `~/.zshrc` |
| **Python 3** | 3.9.6 at `/usr/bin/python3`. Enough — `lm_studio_bridge.py` is stdlib-only |
| **The bridge** | `../Mac Mini Setup/tools/lm_studio_bridge.py`, working |

## Being added

| Software | Why |
|---|---|
| **Qwen2.5-Coder-14B-Instruct (MLX 4-bit, ~8.3GB)** | The coding model. See "Model choice" below |

## Recommended — one manual install

**OpenSCAD** — https://openscad.org/downloads.html (free, drag to Applications).

Not required to make Fusion work. It exists to run the **control test**: the same parts, asked for in OpenSCAD instead of the Fusion API. Model training data contains far more OpenSCAD than Fusion API code, so this is the fastest way to find out whether direct Fusion scripting is the right architecture at all. It also has a headless CLI, so results can be rendered without opening the GUI:

```bash
/Applications/OpenSCAD.app/Contents/MacOS/OpenSCAD -o out.stl in.scad
```

## Deliberately skipped for the trial

- **CadQuery** — the other neutral-format candidate, but system Python here is 3.9 and CadQuery wants 3.10+, so it needs `uv` or miniforge and its own environment. Higher setup cost than OpenSCAD for the same question. Revisit only if OpenSCAD wins the control test and you want a Python-native version of it.
- **Homebrew** — not installed. Nothing here needs it; OpenSCAD ships as a normal `.app`.
- **The watcher add-in** — unattended execution is a mini-era concern. For the trial, run scripts by hand from Fusion's Scripts and Add-Ins dialog.

## RESOLVED 2026-08-20 — the 14B runs, and setup is now scripted

The 14B was initially blocked by LM Studio's memory guardrail, which **over-estimated it at 10.86 GiB when it actually loads at 7.75 GiB**. Fixed by setting `modelLoadingGuardrails.mode: "off"`.

The whole LM Studio setup is now a tested toolkit at `../Mac Mini Setup/tools/local-ai/` — config, autostart, model downloads, and a 13-point health check, all replicable onto the mini. Don't hand-configure LM Studio; run those scripts.

## Model choice — why Qwen2.5-Coder-14B

**The binding constraint is not the 16GB.** macOS only lets the GPU address roughly **70% of unified memory**, so this is effectively an **~11GB machine** for model weights unless `iogpu.wired_limit_mb` is raised (currently `0`, i.e. default).

Catalog options checked against that ceiling:

| Model | ~Size @ 4-bit | Fits ~11GB? |
|---|---|---|
| **qwen/qwen2.5-coder-14b** | ~8.3GB | ✅ **chosen** — comfortable, leaves headroom |
| mistralai/devstral-small-2-2512 | ~13GB | ❌ over the cap; would need the sysctl raised and leaves nothing for Fusion |
| qwen/qwen3-coder-30b | **16.0 GiB measured** (was ~17GB est.) | ❌ |
| qwen/qwen2.5-coder-32b | ~18GB | ❌ |
| qwen/qwen3-coder-next (80B MoE) | ~45GB | ❌ |

The three models already on disk (`qwen3.5-9b`, `llama-3.1-8b`, `gemma-4-e4b`) are general-purpose, not coding models — none is a fair test of this workload.

**Run the model and Fusion sequentially, not simultaneously.** Generate the script, `lms unload` the model, then run it in Fusion. That sidesteps the memory contention entirely on this machine and is fine for a trial — it is only the *unattended* mini that needs both resident at once.

## What this trial cannot tell you
Qwen2.5-Coder-14B is the ceiling for 16GB, and it is **two tiers below** what the mini would run (Qwen3-Coder-30B / Devstral). If 14B scores poorly, that is not proof the approach fails — it is a floor, not a verdict. If 14B scores *well*, that is a strong buy signal.

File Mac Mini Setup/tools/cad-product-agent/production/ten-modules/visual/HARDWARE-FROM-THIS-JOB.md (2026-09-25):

# Mac mini specs, verified against this job

Input to `Fusion CAD Agent/Hardware-Requirements.md`, which owns the requirement
and `Mac Mini Setup` owns the purchase. This file adds **measurements** where
that file has estimates, and it changes the conclusion in one respect.

Measured 2026-08-26 on the laptop: **Apple M1 Pro, 10 cores, 16 GB, macOS 26.5.2.**

## The headline correction

`Hardware-Requirements.md` sizes the mini on **memory**, on the assumption that a
30B-class coding model and Fusion are resident together. That reasoning is sound
for the *coding* workload and unchanged.

**For this rendering job, memory is not the binding constraint. Cores are.**

| Signal | Measured | What it means |
|---|---|---|
| Fusion `RenderProcess` CPU | **~900–975%** | The ray tracer saturates ~9 of 10 cores. Wall clock scales with core count almost linearly. |
| Free memory during a render | **75–81% of 16 GB** | Never close to pressure. Rendering is not what fills RAM. |
| Fusion app resident | 1.0–1.5 GB | Modest, and it went *down* across modules (1.50 → 1.03 GB) — no leak. |
| `RenderProcess` resident | ~1.5 GB | Modest. |
| Peak for the whole render path | **~3 GB** | Fusion + worker + macOS overhead. |

A 16 GB machine renders this job comfortably. What it does *not* do is render it
quickly, and it cannot host a large local model at the same time.

## Measured render cost

Sixteen successful renders at 2400 × 1800, quality 75:

```
min 35s   max 240s   mean 104s   n=16
```

The spread is framing, not variance. The early wide framing (`distance_factor`
1.35) ran 35–75 s; the final framing (0.95, subject filling ~33% of frame with
ray-traced ground below it) ran **120–240 s**. Budget the higher number.

**One caveat on these numbers.** Several apparent "slow renders" of 9–12 minutes
were not renders at all — they were orphaned workers spinning at ~900% CPU after
their driver was killed, producing nothing and starving the real work. Only runs
whose driver stayed alive are counted above. The whole-tree shutdown now in
`render_module.py` prevents the orphan; it is worth knowing the failure mode
exists because it makes a healthy machine look overloaded.

## What the full sweep costs

```
200 renders x 180s              = 10.0 h
Fusion recycles (~4 per cycle)  =  1.0 h
vision review, 100 modules      =  2.5 h
                                  -------
                                  ~13.5 h  on 10 cores
```

Scaling by cores, holding clock roughly equal:

| Mac mini config | CPU cores | Est. sweep | Notes |
|---|---|---|---|
| M4 | 10 | ~13.5 h | Same core count as the laptop. No improvement on this job. |
| M4 Pro | 12 | ~11.5 h | |
| M4 Pro (upgraded) | **14** | **~10 h** | Best current mini for this workload. |
| M5 Pro / M6 mini | unknown | — | Expected before end of 2026; re-check in October. |

Even at 14 cores this is an overnight job. That is fine — it is designed to run
unattended and to resume — but no mini turns it into an interactive loop.

## The requirement this job adds: GPU contention

Fusion's renderer is Metal-based. So is LM Studio with `--gpu max`. **With a
model resident, renders fire and never complete.** Measured: modules that
rendered in 120–185 s with LM Studio stopped produced nothing in 12 minutes with
a 3 B model loaded.

The sweep now unloads models before rendering and reloads the vision model only
for review. That works on any machine, and it means:

- **More unified memory does not remove this constraint.** It is GPU scheduling,
  not capacity. Do not buy RAM expecting to run Fusion and a model concurrently.
- If you want the model resident *while* Fusion renders, that is a second machine
  question, not a bigger-mini question.

## Recommendation

**M4 Pro, 14-core CPU, 48 GB.**

- **14-core** because this job is core-bound and nothing else on the mini's
  roadmap benefits as directly. It is the single spec that shortens the sweep.
- **48 GB** for the reason `Hardware-Requirements.md` already gives — the 30B
  coding model, not this job. This job would be happy with 24 GB. Unified memory
  is not upgradeable, so size it for the coding workload and let rendering
  benefit from the cores.
- 32 GB remains the floor. It runs everything here; it is tight with a 30B model
  and a real assembly, exactly as the existing doc says.

Two things this job does **not** justify:

- **Jumping to a Mac Studio.** The render is core-bound, but not so bound that
  the price step pays for itself on a job that runs overnight anyway.
- **Buying past 48 GB for rendering.** Peak render-path usage is ~3 GB.

## Still unverified before purchase

- **Display requirement.** `Hardware-Requirements.md` flags this and it is still
  open. Fusion needs a window server; whether a mini with no physical display
  renders correctly, or needs an HDMI emulator dongle, is untested. **This job
  cannot run headless if it does not.** Test it on day one.
- **Whether the M5 Pro / M6 mini lands before October**, and what its core counts
  are. If a higher core count arrives at the same price, this job says take it.
- **Render quality vs. time.** Everything above is at quality 75 and 2400 × 1800.
  Dropping quality for iteration cycles and reserving 75 for final images is the
  obvious lever and has not been measured. It may matter more than core count.

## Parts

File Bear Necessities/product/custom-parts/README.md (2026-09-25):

# Custom Parts — keep this list as short as possible

**Design rule: every custom part must be a FLAT plate cuttable on a laser or waterjet from sheet stock.** No machining, no bends, no welds. Flat 2D parts are the cheapest custom parts that exist, they quote instantly from a DXF, and dozens of shops can make them. The moment a part needs a bend or a milled pocket, cost and lead time jump and the drop-ship model gets harder.

## What is genuinely custom — and why

Everything structural is off-the-shelf 80/20 (see `../bom/`). The only thing with no catalog equivalent is the **LOCK** step from the product sheet: securing a module to the vehicle and to other modules. That is also the actual IP.

| # | Part | Why it can't be off-the-shelf | Process |
|---|---|---|---|
| C-01 | Module anchor plate | Bolts into the T-slot on the module base and presents a pin hole at a known position. No catalog part does this. | Laser cut, 1/4" 5052 aluminium |
| C-02 | Vehicle floor bracket | Mates to the anchor plate and bolts to vehicle tie-down points. Vehicle-specific hole pattern. | Laser cut, 1/4" 5052 aluminium |

**The pin itself is NOT custom.** Use an off-the-shelf 1/4" ball-lock or detent quick-release pin. Do not design a pin.

## Deliberately NOT custom
| Item | Use instead |
|---|---|
| Panels | Order cut-to-size from the panel supplier (HDPE / ACM). Cut-to-size is a standard service, not custom fabrication. |
| Handles | Off-the-shelf recessed pull |
| Drawer slides | Off-the-shelf 20" full-extension |
| Corner joints | 80/20 4132 gusseted brackets |
| Levelling feet | Off-the-shelf T-slot glides |

## Open questions before tooling anything
- **C-02 is vehicle-specific.** Every vehicle has a different tie-down pattern. Either ship it undrilled and let the customer drill, offer a few vehicle-specific SKUs, or use a universal slotted pattern. This is a product decision, not a CAD one — and it is the biggest unresolved issue in the drop-ship model.
- Material thickness and pin diameter are assumptions until a load case is defined. What is the worst-case load — a loaded fridge module in a hard stop?

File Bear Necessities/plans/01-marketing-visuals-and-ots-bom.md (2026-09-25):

# Plan 01 — Marketing-grade visuals, deployed configurations, off-the-shelf BOM

Created 2026-08-26. Scope comes from Conor's request, in his order:

1. Top-tier visuals for the ten modules.
2. Iterate ≥10 times on local models (save Claude usage), then **1** Claude pass to
   confirm marketing-ready.
3. Design how the modules fit together in different in-vehicle configurations.
4. Audit every component — including the aluminium extrusion — for off-the-shelf
   availability; rework the BOM to show OTS vs. not.
5. Absorb any model changes that fall out of 3 and 4, then re-render and re-confirm
   the visuals are still top tier.

Each phase is self-contained: it names the files to read, what to copy from, how to
prove it worked, and what not to do. Execute phases consecutively; a fresh context
per phase is fine.

---

## Handoff — 2026-08-26 16:20

**Two agents are working this plan in one tree, and Fusion cannot take both.**
A peer session has rendered a full ten-module set in its own view vocabulary
(`card`, `square`, `alpha`) and is doing Phase 7 work on BN-M03. I stopped driving
Fusion at 16:18 rather than keep competing for it — two drivers on one crash-prone
app is very likely *why* it keeps crashing. Fusion is free now.

**The two render sets fail on complementary axes, which is the useful finding:**

| | mine (`hero`) | peer's (`card`/`square`) |
|---|---|---|
| specular fraction | **0.023 pass** | 0.0000 fail, all 20 |
| background | **gradient pass** | flat fail |
| subject coverage | 0.10 fail | **0.33 / 0.44 pass** |
| edge richness | 62 | **95–111** |
| tonal p99 | **254** | 226, pinned to that value on every image |
| gates passed | 8 of 10 | fails 3 |

Their framing and detail are clearly better; my lighting is the only one producing
a specular highlight or a real backdrop. **The combination passes everything.**
The p99 sitting at exactly 225.8 on all twenty of theirs is worth a look — that is
a ceiling, not a lighting choice.

**What I changed so the pipeline survives the crashes** (`render_module.py`,
`fusion_render.py`):

- **The crash was probably ours.** `_open_module` cached every imported document
  and never closed one, so a ten-module batch held ten designs open at once, each
  with its own copied appearances. `adexmtsv` — the material-library service those
  appearances live in — crashed mid-batch. It now closes all documents before
  opening the next, at the cost of one re-import per module.
- **The MCP port is not stable.** After a crash-relaunch Fusion came back on
  **27180**, not the documented 27182, and every tool pointed at 27182 reported
  "Is Fusion running?" while it was running fine. That cost two hours.
  `discover_mcp_url()` now asks the OS which port the Fusion process is listening
  on and verifies each candidate with a real MCP `initialize` handshake — a plain
  HTTP check is not enough, it picks up port 9766, which answers but is not MCP.
- **One render per bridge call, with retry and relaunch.** A crash now costs one
  module instead of the batch. `render-progress.json` records finished outputs so
  a resume skips them.
- Progress output is flushed, so an unattended run's log is not silent for an hour.

**Not done, and why:** Phase 3's ten-cycle sweep, Phase 4, and the rest of Phase 8
all need sustained Fusion time that this laptop has not been able to give. The
plan already called this out — `native` is not an unattended path. On the evidence
of today it is a Mac mini job.

## Execution status — 2026-08-26

| Phase | State | Evidence |
|---|---|---|
| 0 Discovery | **done** (one finding corrected — see below) | this document |
| 1 Define "marketing-ready" | **done** | `visual/VISUAL-MARKETING-BRIEF.md`, `visual/visual_quality.py`, baseline **0/20 pass** |
| 2 Render path | **done** — Fusion's own ray tracer | `visual/fusion_render.py`, `visual/render_module.py` |
| 3 Ten local cycles | **running** — launched 2026-08-26 13:43, ~35 min/cycle, resumable | `visual/run_visual_cycles.py`, ledger at `visual/visual-iteration-ledger.json` |
| 4 Claude confirmation | blocked on 3 | — |
| 5 Configurations | **done** | `configurations/` — solver, envelopes, 6 validated configurations |
| 6 Off-the-shelf BOM | **done** | `product/bom/OTS-AUDIT.md`, `ots_class` on all 111 rows |
| 7 Absorb changes | blocked on 3/4 | — |
| 8 Final verification | **partial** — everything not gated on Phase 3 verified | see below |

Phase 8 checks that could run today, all passing 2026-08-26:

```
./build.sh validate            4/4 deterministic gates PASS
config_solver.py --validate-all   6 configurations, 0 with no fitting vehicle
visual_quality.py --demo       PASS      run_visual_cycles.py --demo   PASS
config_solver.py --demo        PASS
grep CUSTOM_OTHER in the BOM   none      grep invented Fusion API      none
grep oversized models in visual/  none
```

**BN-M01 hero currently clears 8 of the 10 image gates.** Reproduced twice:
p99 254, specular 0.0227, metal modulation 44.0, coverage 0.295, gradient
background, resolution 2400x1800. The two open failures are `subject_centering`
(0.115 against 0.080) and `contact_shadow_ratio` (1.239 against 0.900 - the frame
is mostly open, so little of the band under it is actually shadowed). Both are
what the Phase 3 loop is tuning.

**Corrections to this plan, made while executing it:**

1. Phase 0 asserted Fusion's render workspace is not scriptable. **It is** — see the
   resolved block below. Rung B (Blender) was withdrawn, along with its install
   approval gate.
2. Phase 1 claimed `panel_modulation` and `subject_coverage` passed at baseline.
   They pass on the iso views and **fail on all ten front views** (coverage 0.820,
   panel modulation 8.7–15.0). Corrected in the brief.
3. Phase 5 predicted "most vehicles take 2–4 modules". Measured: a 4Runner takes
   **exactly 2**, and only rotated 90°. A Transit takes 5.
4. Phase 6 predicted the extrusion was a cut-to-length service worth re-costing.
   It is not — TNUTZ sells any length 1–96 in from the product dropdown, so the
   extrusion was already maximally off the shelf and was reclassified `OTS_STOCK`.

**Findings that create new work, none of which this plan anticipated:**

- **BN-M03 (fridge) does not fit any 4Runner.** Its top-opening lid needs 14 in of
  headroom; an SUV bay leaves 11.5–13 in. BN-M09 fails the same way. This is a
  product decision, and it now sits next to the C-02 decision.
- The BOM's `status` column was conflating availability with engineering release.
  Twenty rows are `ENGINEERING_HOLD` **and** `OTS_STOCK` — buyable today, not
  released. That was invisible before the split.

**Two operational hazards found while running the render pipeline, both now
guarded in code:**

- Fusion's MCP server stops answering for the duration of a render. Two
  overlapping drivers destroy each other's output; `render_module.py` now takes a
  lock.
- **Killing a driver does not cancel the renders.** Fusion finishes them minutes
  later and overwrites the files, which produced several measurements of images
  that had been silently replaced. After killing a driver, wait for the render
  directory to go quiet before trusting it.

**Two measurement bugs of my own, both fixed:**

- A matte older than the render it describes silently produces plausible but wrong
  coverage and shadow numbers. Four render cycles were spent before identical
  coverage across four different framings gave it away. `visual_quality.py` now
  refuses a stale matte and says so.
- `edge_density` (edge pixels over subject *area*) falls as the subject grows in
  frame, so it cannot be a fixed floor across framings. Replaced with
  `edge_richness` (over sqrt of area). Its floor is deliberately **not** taken
  from the legacy captures: their edge richness is inflated by Fusion's CAD
  edge-line overlay, which a photographic render legitimately lacks.

---

## Phase 0 — Documentation discovery (ALWAYS FIRST) — **already done, findings below**

This phase was executed on 2026-08-26. Re-run only the ⚠️ items, which are the
ones that were *not* verified by running them.

### Verified facts (with sources)

**Build front door.** `Bear Necessities/cad/build.sh` resolves everything from
`cad/runtime.json` + `BN_*` env vars; no hard-coded paths. Stages: `test`,
`validate`, `revision`, `native`, `all`. `cad/preflight.py --for <stage>` says what
would fail. Source: `cad/README.md`, `cad/build.sh`.

**Current gate status.** All four deterministic gates PASS as of 2026-08-26
(`validate_family.py`, `validate_jobs.py`, `mesh_integrity.py`,
`validate_native_family.py`). Source: `cad/STATUS.md`.

**How the current images are made.** `production/ten-modules/fusion_native/build_native_modules.py`
lines ~815–860: two explicit cameras (`iso`, `front`), then
`adsk.core.SaveImageFileOptions.create(...)` → `width/height = 1600/1200`,
`isAntiAliased = True`, `isBackgroundTransparent = True`, then
`vp.saveAsImageFileWithOptions(...)`, with a fallback to
`vp.saveAsImageFile(filename, 1600, 1200)`.
**This is a viewport screen capture, not a render.** That is the whole gap.

**Appearances already exist.** Same file, lines ~115–138: a `PALETTE` dict is
copied off the Fusion generic appearance `Prism-129` out of material library
`BA5EE55E-9982-449B-9D66-9F036540E140`, setting `opaque_albedo` and
`surface_roughness` (0.28 for aluminium, 0.52 otherwise). So the models carry
per-body colour and roughness already; the capture path simply does not light it.

**Exports available per module** (`production/ten-modules/fusion-native/exports/<ID>/`):
`.f3d`, `.step`, `.stl`, `.obj` + `.mtl`, `-iso.png`, `-front.png`, `-build.json`.
The OBJ/MTL is described in the header comment as the "material-capable
visualization mesh" — it is the natural input to an external renderer.

**Baseline quality, inspected directly** (`BN-M01-iso.png`): correct geometry, all
twelve members, legible stove/knobs/drawer — but flat shading, one light, no
shadows, no ground contact, no material differentiation between aluminium and
charcoal beyond value, transparent background flattening to white. Reads as a CAD
screenshot. It passes `VISUAL-QA.md` because that gate asks "is the equipment
recognisable", which is a *completion* bar, not a *marketing* bar.

**Local model roster actually loaded** (`curl http://127.0.0.1:1234/v1/models`,
2026-08-26): `prism-ml/bonsai-27b`, `qwen2.5-vl-3b-instruct`,
`qwen2.5-coder-7b-instruct`, `qwen/qwen2.5-coder-14b`, `google/gemma-4-e4b`,
`meta-llama-3.1-8b-instruct`, `qwen/qwen3.5-9b`, `text-embedding-nomic-embed-text-v1.5`.
`runtime.json` asks for reviewer `qwen/qwen2.5-coder-14b`, vision `google/gemma-4-e4b`.

**Hard local-model constraint.** `product/cad/evidence/LM-STUDIO-SAFE-PROFILES.md`:
this 16 GB M1 Pro laptop **kernel-panicked twice** on 2026-08-25 running the 14B MLX
worker (`completeMemory() prepare count underflow`, `IOGPUMemory.cpp`). The laptop
profile is 7B / 6144 ctx / 1800-token cap / 30 s cool-down / 30 % free-memory floor.
Gemma-4-e4b (8.95 GiB) and Qwen3.5-9B (7.79 GiB) are **rejected for the laptop**.
The `qwen2.5-vl-3b` canary loaded at 2.88 GiB, completed one image, then LM Studio
*silently spawned a second parallel instance* and free memory fell 74 % → 32 %. Its
JSON was also self-contradictory: `PASS` with populated blocking findings.

**Existing iteration harness to copy, not reinvent:**
- `production/ten-modules/iterations/run_revision_cycles.py` — resumable text
  critique loop; one validated file per cycle, reused on the next run.
- `production/ten-modules/iterations/validate_revision_ledger.py` — ledger gate.
- `production/ten-modules/fusion_native/review_native_family.py` — the local
  vision-model reviewer. **Copy its resource guard** (`memory_free_percent()` via
  `memory_pressure -Q`, `wait_for_resources(max_load, min_free_percent)`) and its
  `extract_json()` fence-stripping. Lines ~1–60.
- `production/ten-modules/iterations/validate_visual_completion.py` — existing
  image gate.

**Fusion.** Installed at `~/Applications/Autodesk Fusion.app`. Per
`Fusion CAD Agent/reference/fusion-api-notes.md`: **no headless mode on macOS** —
Fusion must be running with a GUI session; `ui.messageBox` blocks forever
unattended; Fusion's embedded CPython cannot import pip packages. The same file
carries a table of API methods local models confidently invent — read it before
writing any Fusion script.

**BOM reality** (`product/bom/modules/all-modules-prototype-bom.csv`, 111 rows,
**25 unique catalog IDs**):

| status | rows |
|---|---|
| ORDERABLE | 48 |
| ENGINEERING_HOLD | 20 |
| ORDERABLE_ENGINEERING_HOLD | 11 |
| ORDERABLE_CHECK_STOCK | 10 |
| ORDERABLE_CUSTOM_CUT | 10 |
| DEALER_ORDER_ENGINEERING_HOLD | 7 |
| DEALER_ORDER | 3 |
| SOLD_OUT | 1 |
| ORDERABLE_ALTERNATE_VERIFY | 1 |

Note the status axis **conflates availability with engineering release** — that is
exactly what Phase 6 has to separate.

**Catalog rules** (`iterations/ots-components.json` → `rules`): models may cite
catalog IDs but may **not** invent vendors, SKUs, dimensions, ratings, availability,
certifications, prices or URLs. ORDERABLE means an order page was visible on the
research date, not a stock guarantee.

### ⚠️ Still to verify by running it (do this at the top of Phase 2)

**RESOLVED 2026-08-26 by probing the live Fusion session — the original entry in
this slot was wrong and is corrected below.**

I had written that Fusion's ray-tracing Render workspace is not part of the
scripted API surface. **It is.** Probing the running session returned a complete
render API:

| Object | Members that matter |
|---|---|
| `design.renderManager` | `activateRenderWorkspace()`, `isRenderWorkspaceActive`, `rendering`, `sceneSettings`, `renderEnvironments`, `inCanvasRendering` |
| `.rendering` | `startLocalRender(filename, camera) -> RenderFuture`, `renderQuality`, `resolution`, `resolutionWidth/Height`, `aspectRatio`, `isBackgroundTransparent` |
| `.sceneSettings` | `backgroundEnvironment`, `backgroundSolidColor`, `isGroundDisplayed`, `isGroundReflections`, `isGroundFlattened`, `groundOffset`, `groundRoughness`, `groundPosition`, `brightness`, `lightAngle`, `cameraExposure`, `cameraFocalLength`, `cameraType`, `isDepthOfFieldEnabled`, `depthOfFieldBlur`, `centerOfFocus` |
| `RenderFuture` | `renderState`, `progress`, `filename`, `imageWidth`, `imageHeight` |
| `renderEnvironments` (14) | Sharp Highlights, Rim Highlights, Cool Light, Warm Light, Soft Light, Grid Light, Crossroads, Dry lake bed, Field, Photobooth, Plaza, Skylight, Snow Field, Custom |
| `RenderResolutions` | up to `Print3000x2400RenderResolution`, plus `CustomRenderResolution` |
| `LocalRenderStates` | `Queued`, `Processing`, `Finished`, `Failed` |

So Fusion can produce HDRI-lit, ray-traced, ground-shadowed renders at 3000 × 2400,
scripted, with no new dependency. **Rung B (Blender) is not needed and the install
checkpoint is withdrawn.**

Gotchas found by running it, all of which cost a failed attempt:

- `app.activeViewport` and `activeProduct` are `None` when no document is open —
  probe with a document, or every attribute reads as absent.
- `inCanvasRendering` raises `Render Workspace must be active` until
  `activateRenderWorkspace()` has been called.
- `sceneSettings.backgroundType` is **read-only**. Assigning
  `backgroundEnvironment` is what flips it to the environment type — which is also
  what produces a gradient backdrop instead of a flat fill.
- `groundRoughness` refuses assignment unless `isGroundReflections` is true.
- `renderComplete` is a `RenderEvent` object, not a bool — it is an event to
  subscribe to, and it is not JSON-serialisable.
- `renderEnvironments` has no `.current`; use `itemByName(...)`.
- `startLocalRender` is asynchronous and queued, one at a time. It outlives any
  single MCP call, so **fire the render in one call and poll for the output file
  from the host** rather than blocking inside Fusion.

Still open:

- ⚠️ Whether the Prism metal appearances (as opposed to the generic `Prism-129`
  currently copied) give a better aluminium under ray tracing. Test during Phase 3.
- ⚠️ Wall-clock per render at quality 75 and 2400 × 1800, which sets whether a
  10-cycle sweep is an overnight job or a multi-day one.

### Allowed APIs / tools list

| Use | Allowed | Source |
|---|---|---|
| Build/validate | `cad/build.sh {test,validate,revision,native,all}`, `cad/preflight.py --for <stage> [--json]` | `cad/README.md` |
| Fusion geometry | `adsk.fusion.Design.cast(app.activeProduct)`, `rootComp.xYConstructionPlane`, `extrudeFeatures.createInput(...)` → `.add(input)`, `setDistanceExtent(False, ValueInput)`, `design.exportManager` | `fusion-api-notes.md` |
| Fusion appearance | `app.materialLibraries.itemById(...)`, `lib.appearances.itemById(...)`, `design.appearances.addByCopy(...)`, `appearanceProperties.itemById("opaque_albedo"/"surface_roughness")` | `build_native_modules.py:115–138` |
| Fusion capture | `adsk.core.SaveImageFileOptions.create(path)` + `vp.saveAsImageFileWithOptions(opts)`; fallback `vp.saveAsImageFile(path, w, h)` | `build_native_modules.py:838–847` |
| Fusion render | `design.renderManager` → `activateRenderWorkspace()`, `sceneSettings`, `renderEnvironments.itemByName(...)`, `rendering.startLocalRender(path, camera)`, poll `RenderFuture.renderState` against `adsk.fusion.LocalRenderStates` | probed live 2026-08-26 |
| Local models | LM Studio OpenAI-compatible endpoint at `http://127.0.0.1:1234/v1` | `runtime.json` |
| Units | API is **cm and radians** always; 1 inch = `2.54` | `fusion-api-notes.md` |

### Anti-patterns (apply to every phase)

- Do not invent Fusion API members. Check the offline table of confirmed
  hallucinations in `fusion-api-notes.md` first.
- Do not invent a vendor, SKU, dimension, rating, price, availability or URL.
  Cite a catalog ID from `ots-components.json` or mark it UNVERIFIED.
- Do not break the frame invariants: 24 × 20 × 18 in outer, 22 × 18 × 16 in clear,
  exactly twelve members, **8 × 18 in + 4 × 22 in — two cut lengths only**.
- Do not load `google/gemma-4-e4b` or `qwen/qwen3.5-9b` on the laptop.
- Do not accept a self-contradictory model verdict (PASS with blocking findings) —
  that is a failed attempt, not a pass.
- Do not overwrite the last-good render set until the replacement passes the gate.
- Do not describe local-model output as engineering release, measurement, or safety
  evidence.
- Do not regenerate an evidence report without stamping the validator SHA-256 —
  the existing gates already do this; a report whose hash does not match the
  current validator is flagged by preflight. See `cad/STATUS.md`.

---

## Phase 1 — Define "marketing-ready" as a checkable thing

Nothing here needs a model. This phase exists because "top tier" is currently
unfalsifiable, and every later phase gates on it.

### Implement

1. Write `production/ten-modules/visual/VISUAL-MARKETING-BRIEF.md`. Copy the
   structure of the existing `VISUAL-DESIGN-BRIEF.md` (family visual language →
   per-module required content → QA), but replace the *completion* bar with a
   *presentation* bar:
   - camera: one hero 3/4 iso, one straight front, one detail crop, consistent
     focal length and horizon across all ten so a grid reads as one family
   - materials: brushed aluminium must read as metal (anisotropic highlight), not
     as light grey; charcoal panels matte; rubber, glass and fabric distinct
   - light: key + fill + rim; contact shadow under the frame so the module sits on
     a surface instead of floating
   - background: a real neutral gradient or seamless ground, plus a separate
     alpha-channel cut-out variant for web use
   - resolution: 2400 × 1800 minimum for hero, ≥ 1600 × 1200 for the rest
   - the existing per-module required-visible-content list (BN-M01…BN-M10) carries
     over verbatim from `VISUAL-DESIGN-BRIEF.md` — legibility is still required,
     presentation is now required *as well*
2. Write `production/ten-modules/visual/visual_quality.py` — a **model-free**
   image gate using only PIL/numpy. This is the cheap first opinion that catches
   "still looks like flat CAD" without spending a single token:
   - luminance histogram spread and clipped-highlight fraction
   - distinct-value count on the aluminium mask vs. the charcoal mask (flat
     shading collapses these)
   - presence of a contact shadow: luminance gradient in the band below the
     silhouette
   - silhouette coverage fraction of frame (hero framing, not a speck)
   - edge density (proxy for detail retention after lighting)
   - background classification: transparent / flat white / gradient
   - per-image SHA-256 in the report, matching the existing evidence convention
   - a `--baseline` mode that scores the current 20 PNGs so every later score is
     relative to a real number, not a guess
3. Run it against the existing 20 renders and commit
   `production/ten-modules/visual/visual-quality-baseline.json`.

### Verify

```bash
cd "Bear Necessities/cad" && ./build.sh validate
python3 "../../Mac Mini Setup/tools/cad-product-agent/production/ten-modules/visual/visual_quality.py" --baseline
```

- Baseline report exists, covers 20 images, each with a SHA-256.
- The baseline **fails** the new thresholds. If it passes, the thresholds are too
  loose — the whole premise is that today's images are not marketing-grade.
- `./build.sh validate` still returns four passing gates (this phase adds no
  geometry).

### Anti-patterns

- No model calls in `visual_quality.py`. It is deterministic or it is worthless as
  a tiebreak.
- Do not tune thresholds until the baseline passes. Set them from the brief.

---

## Phase 2 — Pick the render path and prove it on one module

**DECIDED 2026-08-26: Fusion's own local renderer.** The Phase 0 probe resolved
this — Fusion ray-traces to file, scripted, at up to 3000 × 2400 with HDRI
environments and a ground plane. No install, no approval gate, no second toolchain
to keep in sync with the geometry. The Blender option is withdrawn.

The one real constraint that survives: **Fusion has no headless mode on macOS**, so
Fusion must be running and signed in for every render. Renders are queued one at a
time and run as a background process tied to the Fusion process. A sweep is
therefore long-running-but-unattended-ish: it does not need a human clicking, but it
does need the app left open, and it cannot share the machine with a heavy local
model run. That interacts directly with the LM Studio memory ceiling in Phase 3 —
sequence them, do not overlap them.

### Implement

1. Read `fusion-api-notes.md` in full, then `build_native_modules.py:100–200` and
   `:805–870`.
2. Rung A: add `--visual-profile marketing` to `build_native_modules.py`, defaulting
   to today's behaviour so the existing native gate is untouched. Probe the live
   `Viewport` object for shadow/AO/environment properties and **log what is
   actually there**; do not code against a property you have not seen.
3. Render **BN-M01 only**. Score with `visual_quality.py`. Compare to baseline.
4. If Rung A clears the brief, stop — Phase 3 uses it. If not, write
   `production/ten-modules/visual/RENDER-PATH-DECISION.md` with the two scored
   BN-M01 images side by side and the attended-render argument, ask Conor, and on a
   yes build `production/ten-modules/visual/render_module.py` for Blender:
   - `bpy.ops.wm.obj_import(filepath=...)` reading the existing OBJ + MTL
   - map the `PALETTE` keys from `build_native_modules.py` onto Principled BSDF
     values (metallic 1.0 / roughness 0.28 for aluminium; metallic 0 / roughness
     0.52 charcoal; separate glass, rubber and fabric)
   - three-point light, ground plane with contact shadow, gradient world
   - the brief's camera set, identical across modules
   - CLI: `--module BN-M01 --views iso,front,detail --out <dir> [--alpha]`
5. Whichever path wins, BN-M01 must produce a full view set that passes Phase 1.

### Verify

- BN-M01 hero, front and detail exist at the brief's resolutions.
- `visual_quality.py` scores BN-M01 **above** the Phase 1 thresholds and above its
  own baseline on every metric.
- Direct inspection: the aluminium reads as metal, the module sits on a surface,
  every item on BN-M01's required-visible-content list is still identifiable.
- The default (no `--visual-profile`) path still reproduces the old images, so
  `./build.sh native` and `validate_native_family.py` are unaffected.

### Anti-patterns

- Do not block inside Fusion waiting for a render. `startLocalRender` is async and
  queued; fire it and poll for the output file from the host.
- Do not set `groundRoughness` without first enabling `isGroundReflections`, and do
  not assign `backgroundType` — it is read-only.
- Do not re-model geometry to make a render look better. Phase 2 changes
  presentation only. Geometry changes are Phase 7.
- Do not install Blender before asking.
- Do not delete the existing 20 PNGs. Write the new set to a new directory.

---

## Phase 3 — Ten local iteration cycles across all ten modules

Target: **≥ 10 cycles × 10 modules = ≥ 100 module-visual reviews**, all local, zero
Claude usage.

### The local-model design, given the laptop constraint

Phase 0 established that this 16 GB laptop kernel-panicked on the 14B and that
every capable VLM is over budget. So the loop uses **two graded opinions**, not one:

1. **Deterministic** — `visual_quality.py`. Free, runs on every image, every cycle.
   This is the primary gate.
2. **Local VLM second opinion** — `qwen2.5-vl-3b-instruct` (2.88 GiB, the only
   vision model that fits), **one image at a time**, against a fixed yes/no
   checklist derived from the brief, not an open-ended "is this good?".
3. **Local text critique** — `qwen2.5-coder-7b-instruct` (the profile-approved
   7B) reads the *numeric* `visual_quality.py` report plus the VLM checklist and
   proposes the next parameter change. It never sees an image, so it costs nothing
   in VRAM beyond the 7B, and its job is narrow: pick the next lighting/material/
   camera delta from a fixed vocabulary.

If Conor runs this on the Mac mini instead, `runtime.json`'s `mac-mini` profile and
`google/gemma-4-e4b` apply and step 2 upgrades — the loop must read the profile,
not hard-code the model.

### Implement

1. Copy the resource guard and JSON extraction from
   `fusion_native/review_native_family.py:1–60` verbatim into a new
   `production/ten-modules/visual/run_visual_cycles.py`. Do not rewrite them.
2. Copy the **resumability** pattern from `iterations/run_revision_cycles.py`: one
   validated file per cycle, reused on re-run. A 100-review sweep must survive an
   interrupt without restarting. This is stated in `cad/README.md` as the reason it
   exists — a full sweep is expensive.
3. Enforce the laptop profile from `LM-STUDIO-SAFE-PROFILES.md`: 6144 context,
   1800-token output cap, one prediction, speculative decoding off, 30 s cool-down,
   load ceiling 20, free-memory floor 30 %.
4. **Guard against the two known failure modes, explicitly:**
   - *Silent parallel instance* — after each VLM call, query
     `/v1/models` and abort if more than one instance of the vision model is
     resident. This is what drove free memory 74 % → 32 % on 2026-08-25.
   - *Self-contradictory verdict* — reject any response where
     `verdict == "PASS"` and `blocking_findings` is non-empty. Count it as a failed
     attempt and retry within the attempt budget.
   - *The 2026-08-25 length bug* — `cad/STATUS.md` records a 30-cycle run killed by
     a 267-character field against a 240-character cap whose error message said only
     "length/type invalid", so the model resampled instead of shortening. **State
     every limit in the prompt, and make every failure message report the measured
     value and the delta.** Repeat that fix here; do not re-earn it.
5. Write `visual-iteration-ledger.json` in the shape of
   `iterations/runs/iteration-ledger.json`: per cycle, per module — image SHA-256,
   deterministic scores, VLM checklist, adopted delta, model ID actually used.
6. Add `production/ten-modules/visual/validate_visual_ledger.py`, modelled on
   `iterations/validate_revision_ledger.py`: ≥ 10 cycles × 10 modules, every record
   carries a real model ID, every image hash is current, no adopted change violates
   a frame invariant.
7. Wire a `./build.sh visuals` stage into `cad/build.sh` and a matching
   `preflight.py --for visuals`. Follow the existing stage pattern exactly — resolve
   from `runtime.json`, honour `BN_*`, add the new models under `models` with
   `BN_VISUAL_*` overrides.

### Verify

```bash
cd "Bear Necessities/cad"
python3 preflight.py --for visuals
./build.sh visuals
python3 "$BN_STUDY/visual/validate_visual_ledger.py"
```

- Ledger shows ≥ 100 module-visual reviews across ≥ 10 cycles.
- Every one of the 10 modules scores above the Phase 1 thresholds on its final set.
- No record carries a fabricated model ID; the low-memory continuation policy is
  named explicitly if a mixed roster was used (the existing ledger convention).
- The sweep survives a deliberate `Ctrl-C` and resumes rather than restarting.
- **Zero Claude tokens spent in this phase.**

### Anti-patterns

- Do not send more than one image per request.
- Do not load a model above the profile's memory budget because "it's just one run".
  That is exactly the 2026-08-25 kernel panic.
- Do not let the VLM's prose become the gate. The numbers are the gate; the VLM is
  a checklist second opinion.
- Do not let a local model edit geometry. It proposes presentation deltas from a
  fixed vocabulary; anything else needs Phase 7.

---

## Phase 4 — One Claude confirmation pass

Exactly one pass. Its job is to answer a question the local loop structurally
cannot: *would a customer looking at this grid believe it is a real product?*

### Implement

1. Assemble a single contact sheet: all ten hero renders in one grid, plus the ten
   fronts, at review resolution.
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

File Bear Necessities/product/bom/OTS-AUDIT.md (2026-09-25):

# Off-the-shelf audit

Date: 2026-08-26. Source of record: `production/ten-modules/iterations/ots-components.json`
(25 catalog IDs) and the regenerated module BOMs (111 rows).

## Headline

**24 of 25 catalog items (96%) are buy-as-is off the shelf. One is a flat panel cut
from sheet. Nothing requires a fabricated part that is not a flat plate.**

| `ots_class` | Catalog IDs | BOM rows | Meaning |
|---|---|---|---|
| `OTS_STOCK` | 24 | 101 | Buy the catalogue item as-is |
| `OTS_CUT` | 0 | 0 | Vendor cuts to a specified length |
| `OTS_MODIFIED` | 0 | 0 | Needs drilling/tapping/machining after receipt |
| `CUSTOM_FLAT` | 1 | 10 | Fabricated, but a flat plate from sheet |
| `CUSTOM_OTHER` | **0** | **0** | Fabricated and not flat — a design failure. There are none. |

Plus one custom part outside the catalogue: **C-01 anchor plate**, `CUSTOM_FLAT`,
flat and laser-cut. It satisfies the standing rule in `Bear Necessities/CLAUDE.md`
that every custom part must be a flat plate cuttable from sheet.

## Why the BOM now has two columns instead of one

`status` and `ots_class` were tangled together in values like
`ORDERABLE_ENGINEERING_HOLD` and `DEALER_ORDER_ENGINEERING_HOLD`. They answer
different questions and they move independently:

- **`status`** — can I buy this today?
- **`ots_class`** — is this off the shelf at all?

The cross-tab makes the point:

| status | ots_class | rows |
|---|---|---|
| ORDERABLE | OTS_STOCK | 48 |
| ENGINEERING_HOLD | OTS_STOCK | 20 |
| ORDERABLE_ENGINEERING_HOLD | OTS_STOCK | 11 |
| ORDERABLE_CHECK_STOCK | OTS_STOCK | 10 |
| ORDERABLE_CUSTOM_CUT | CUSTOM_FLAT | 10 |
| DEALER_ORDER_ENGINEERING_HOLD | OTS_STOCK | 7 |
| DEALER_ORDER | OTS_STOCK | 3 |
| SOLD_OUT | OTS_STOCK | 1 |
| ORDERABLE_ALTERNATE_VERIFY | OTS_STOCK | 1 |

**Twenty rows are `ENGINEERING_HOLD` and also `OTS_STOCK`** — you can put them in a
cart today; they are simply not engineering-released. That is a procurement fact
and a release fact, and collapsing them into one string hid it. No hold, sold-out
or dealer-order disposition was changed by this audit; the durable rule in
`LOCAL-MODEL-ITERATION-LEARNINGS.md` says preserve them, and they are preserved.

## The aluminium extrusion — the specific question asked

The frame is `TNUTZ-EX1010-18` ×8 and `TNUTZ-EX1010-22` ×4. The BOM described
these as "cut to 18 inches" / "cut to 22 inches", which reads like a custom cutting
service being bought.

**It is not.** The TNUTZ EX-1010 product page sells the profile from a length
dropdown covering **1 to 96 inches, with fractional selections from 0" to 15/16"** —
so any length in 1/16-inch steps is a catalogue selection. The listed price range
is **$0.22 – $25.46**, spanning that 1-to-96-inch range. No separate cut fee or
minimum is shown on the product page.

Source: [TNUTZ EX-1010](https://www.tnutz.com/product/ex-1010/), fetched 2026-08-26.

So the answer to "can the extrusion be more off the shelf?" is **it already is
maximally off the shelf**: 18 in and 22 in are ordered straight from the dropdown,
no saw, no drop, no machining, no cut fee. Reclassified `OTS_CUT` → `OTS_STOCK`.

This also means the "two cut lengths only" rule is cheaper than it looked. Its
value is not saw setups — there is no saw. It is **two line items instead of
twelve**, and it stays worth preserving for that reason.

Not yet verified, and worth one phone call before any real order:

- Whether a cut fee appears at checkout that the product page does not show.
- Whether volume pricing changes the 18-in/22-in unit price.
- Whether 80/20's own 1010-S (the primary part, with TNUTZ as the drop-ship
  alternate) offers the same any-length ordering, or only mill lengths.

## Items that are off the shelf but not currently buyable

These are `OTS_STOCK` — the problem is availability, not fabrication.

| Item | Status | What closes it |
|---|---|---|
| `ENGEL-MD14` 15 qt fridge | SOLD_OUT | `ENGEL-MHD13-ALT` (14 qt) is the envelope-verified prototype alternate. It fits, but remains a procurement/intended-use hold. See below. |
| `RELIANCE-AQUATAINER-7G` / `-4G` | DEALER_ORDER | Find a stocking retailer or accept dealer lead time |
| `RUBBERMAID-FG350700WHT` tote | DEALER_ORDER | Commercial-channel item; a consumer-channel equivalent would remove the hold |
| `TNUTZ-HAN015AL` handle | ORDERABLE_CHECK_STOCK | Confirm stock or qualify a second source |
| `ACCURIDE-3832-C16` slides | DEALER_ORDER_ENGINEERING_HOLD | Both a channel and a release problem |
| `SHURFLO-4008` pump | DEALER_ORDER_ENGINEERING_HOLD | Both a channel and a release problem |

## The one fabricated item

`TAP-HYPACT-PANEL` — black UV-stabilised polymer sheet, cut to size for skins,
trays and dividers. One "cut-panel lot" per module, so 10 BOM rows.

It is `CUSTOM_FLAT` and therefore allowed, but it is the only thing in the product
that cannot be ordered from a catalogue page, and it is gated on released DXF panel
drawings that do not exist yet. Those drawings are the single largest remaining
piece of non-CAD product work.

## BN-M03 alternate disposition

The MHD13F-DM dimensions published by Engel are **17.5 × 11.3 × 14.5 in**. It
keeps the MD14 footprint and is 1.3 in shorter, so it fits the existing BN-M03
component origin and 22 × 18 × 16 in clear envelope with more clearance than the
original. `module-family.json` now carries the alternate's real envelope.

It is **not promoted to buy-ready**. Checked 2026-08-26:

- Engel's own page says sold out and positions the unit for EMS medication and
  saline transport, not consumer food storage.
- Zoro carries an order page, but lists both 14.5 in “outside height” and a
  contradictory 18.25 in “exterior height.”
- Engel confirms the existing TSLPLATE + TSL17 transit-lock combination fits
  both MD14F and MHD13F-DM.

The honest disposition is therefore `ORDERABLE_ALTERNATE_VERIFY`: **envelope
verified; availability, dimensional discrepancy, intended food use and warranty
still held.** This closes the model-fit task without laundering uncertain
procurement evidence into an ORDERABLE claim.

Sources checked 2026-08-26: Engel MHD13 manufacturer page, Engel transit slide
lock and lock-plate pages, and Zoro G7673053 order page (URLs are retained in
`ots-components.json`).

## Deployment consequence

The configuration work done the same day found that **BN-M03 does not fit any
4Runner measured** — its top-opening lid needs 14 in of headroom and an SUV bay
leaves 11.5–13 in. See `configurations/CONFIGURATIONS.md`.

The shorter alternate does not solve lid swing. BN-M03 still needs 14 in above the
closed module and does not fit either measured 4Runner cargo bay. It is therefore
classified as a **van/truck-class module** for this release rather than forcing a
third extrusion length or replacing a chest fridge with a front-opening product.

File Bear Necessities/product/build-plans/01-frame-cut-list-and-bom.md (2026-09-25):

# 01 — Frame cut list and bill of materials

For **one** module frame: a 24 × 20 × 18 in outside cube in 1 × 1 in
("10 Series") aluminium T-slot extrusion.

All part numbers below were checked on 2026-08-20 against 8020.net and
tnutz.com. **Prices are intentionally blank — request a live quote.** Do not fill
them in from memory or estimate.

See `00-status-and-limitations.md` §3b before ordering the brackets: the joint
design is an engineering-hold concept, not a tested joint.

---

## The cut list — two lengths only

| Cut length | Qty | Role in the frame |
|---|---:|---|
| **18 in** | 8 | 4 vertical corner posts + 4 depth rails (2 top, 2 bottom) |
| **22 in** | 4 | 4 width rails (2 top, 2 bottom) |

**Why the depth rails and posts are the same length:** the frame is 18 in tall,
and the 20 in depth minus two 1 in profiles at the ends leaves an 18 in rail. So
8 of the 12 pieces are one length. The 22 in width rail is 24 in minus two 1 in
profiles.

- Total extrusion per frame: **232 in = 19.33 ft**.
- Distinct cut lengths: **2**. Preserve this in any change to the design — it is
  the cheapest orderable cut list and the project treats it as a hard invariant.

### Cut geometry

```
            22" width rail  (x4: 2 top, 2 bottom)
        ┌──────────────────────┐
        │                      │
 18"    │                      │  18" vertical post (x4)
 depth  │                      │
 rail   │                      │
 (x4)   └──────────────────────┘
        outside footprint 24" x 20", height 18"
```

Every member is a plain length of profile. **No machining, no end taps, no
drilled holes in the extrusion** in this concept — the corner brackets and
T-nuts do all the joining from inside the slots. (An alternative concealed-anchor
joint would require counterbored ends; it is carried at quantity zero and is not
part of this pack.)

---

## Bill of materials — one frame

| # | Part number | Alt. part | Description | Vendor | Qty | Unit | Status |
|---|---|---|---|---|---:|---|---|
| 1 | `1010-S` (cut to 18 in) | `EX-1010` | 1 × 1 in smooth-surface T-slot profile, four open slots | 80/20 Inc (alt: TNUTZ) | 8 | pc | Orderable |
| 2 | `1010-S` (cut to 22 in) | `EX-1010` | 1 × 1 in smooth-surface T-slot profile, four open slots | 80/20 Inc (alt: TNUTZ) | 4 | pc | Orderable |
| 3 | `4132` | — | 10 Series 2-hole **gusseted** inside corner bracket | 80/20 Inc | 24 | pc | **Engineering hold** — joint not load-tested |
| 4 | `3393` | — | 1/4-20 × 0.500 in bolt + slide-in economy T-nut assembly, for the `4132` bracket (2 per bracket) | 80/20 Inc | 48 | pc | **Engineering hold** — torque/vibration retention unverified |

**Bracket count logic:** three members meet at each of the 8 corners (one post,
one width rail, one depth rail). One 2-hole bracket joins each adjacent pair →
3 brackets per corner × 8 corners = 24. Two fastener assemblies per bracket → 48.

### Notes on each line

- **Lines 1–2 (extrusion).** TNUTZ `EX-1010` is stated 100% compatible with 80/20
  `1010-S` and is sold cut to any length 1–96 in from the product-page dropdown
  in 1/16 in steps, ~48 h turnaround, no separate cut fee shown on the page.
  Order URL: `https://www.tnutz.com/product/ex-1010/`. Most 80/20 distributors
  drop-ship and take margin, so going direct to a cutting distributor is likely
  cheaper and faster. **Not yet confirmed:** whether a cut fee appears at
  checkout, volume pricing, and whether 80/20's own `1010-S` offers the same
  any-length ordering or only mill lengths — worth one phone call before a real
  order.
- **Line 3 (`4132` bracket).** Gusseted (heavy-duty) chosen over the lighter
  `4108` because the modules are designed to carry a loaded fridge and be lifted
  by their corners. Order URL: `https://8020.net/4132.html`. **This is an
  engineering-hold item:** you can put it in a cart today, but the project has
  not load-tested this joint. If you are carrying anything heavy, get your own
  engineering sign-off on the bracket type and count.
- **Line 4 (`3393` fastener).** Order URL: `https://8020.net/3393.html`. The
  project's older BOM files and the CAD provenance file name `3395` (a 10-32
  anchor fastener) instead; the current procurement BOM and the
  production-readiness audit both specify `3393` as the correct hardware for the
  `4132` bracket, with `3395` at quantity zero. **Confirm the correct fastener
  with 80/20 when you order the bracket** — they will tell you what `4132` takes.
- **Install torque is not specified anywhere in the source design.** Use 80/20's
  published torque spec for the `3393` fastener (request it from the vendor). Do
  not guess a torque value for a joint that carries load in a vehicle.

---

## Ordering for more than one frame

The ten-module family scales linearly:

| Frames | 18 in pieces | 22 in pieces | `4132` brackets | `3393` fasteners | Total extrusion |
|---:|---:|---:|---:|---:|---:|
| 1 | 8 | 4 | 24 | 48 | 232 in |
| 10 | 80 | 40 | 240 | 480 | 2320 in (193 ft) |

---

## What this BOM does not include

- **The vehicle mount (C-02).** Not designed. See `00-status-and-limitations.md`
  §3a.
- **The module anchor plate (C-01).** Covered separately in
  `03-anchor-plate-C-01.md` — it's a custom laser-cut part, not catalog.
- **Panels / skins, handles, feet, gasket, tread, drawer slides, latches.**
  These appear in the module concepts (`04-module-concepts.md`) and the parts
  catalog (`05-off-the-shelf-parts-catalog.md`) but are not part of the bare
  frame and several are not yet sourced to a specific part number.
- **Fasteners to attach panels or accessories to the frame** — depends on the
  panel design, which isn't drawn.

## Reference files

- `drawings/base-frame-ots.step` — 3D model of the frame (see units caveat,
  `00-status-and-limitations.md` §5).
- `drawings/base-frame-ots-ISO.svg` — projected line drawing.
- `drawings/base-frame-ots.stl` — mesh, for quick viewing.

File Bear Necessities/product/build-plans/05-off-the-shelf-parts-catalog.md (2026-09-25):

# 05 — Off-the-shelf parts catalog

Every catalog component referenced across the frame and the ten module concepts.
Compiled from the project's audited prototype BOM (`all-modules-prototype-bom.csv`,
`OTS-AUDIT.md`). **All prices are quote-on-request** — the project deliberately
keeps them null and so does this pack.

**Status legend:**

| Status | Meaning |
|---|---|
| Orderable | An order page was visible on the research date (2026-08-20 / -26). Not a stock guarantee. |
| Check stock | Orderable but limited stock was shown — confirm or qualify a second source. |
| Dealer order | No direct consumer sale; go through a dealer / distributor. |
| Alternate — verify | A substitute for a sold-out part; envelope fits but availability / use / warranty unconfirmed. |
| Sold out | Manufacturer page showed no stock. Carried at quantity zero. |
| Engineering hold | Buyable today, **not engineering-released** — the joint / load / retention it's part of is untested. |
| Custom cut | Catalog material, cut to size from a drawing (drawing may not exist yet). |

The "engineering hold" flag is independent of buyability. Twenty BOM rows are
*both* orderable and engineering-hold.

---

## Structural — the frame

| Part | Vendor | Description | Used in | Status | Source |
|---|---|---|---|---|---|
| `1010-S` / `EX-1010` | 80/20 (alt: TNUTZ) | 1 × 1 in 10 Series smooth T-slot profile, cut to 18 in | Frame ×8/frame | Orderable | tnutz.com/product/ex-1010/ · 8020.net |
| `1010-S` / `EX-1010` | 80/20 (alt: TNUTZ) | same, cut to 22 in | Frame ×4/frame | Orderable | tnutz.com/product/ex-1010/ |
| `4132` | 80/20 | 10 Series 2-hole gusseted inside corner bracket | Frame joint ×24/frame | **Engineering hold** | 8020.net/4132.html |
| `3393` | 80/20 | 1/4-20 × 0.500 in bolt + slide-in economy T-nut, for `4132` (×2 per bracket) | Frame joint ×48/frame | **Engineering hold** | 8020.net/3393.html |
| `3395` / `AF-010` | 80/20 / TNUTZ | 10 Series 10-32 anchor fastener — *concealed-joint alternative* | Not used (qty 0) | Not evaluated | tnutz.com/product/af-010/ |

## Frame trim — shared across modules

| Part | Vendor | Description | Per module | Status | Source |
|---|---|---|---|---|---|
| `HAN-015-AL` | TNUTZ | Black aluminium carry handle with 10 Series mounting hardware | 2 | Check stock; **not rated for a loaded lift** | tnutz.com/product/han-015-al/ |
| `GAS-010-A` | TNUTZ | 10 Series panel gasket for ~3/16 in panels | ~20 ft (allowance) | Orderable | tnutz.com/product/gas-010-a/ |
| `BUM-010-TS` | TNUTZ | 10 Series anti-skid rubber tread strip | ~8 ft (allowance) | Orderable | tnutz.com/product/bum-010-ts/ |
| King Hy-Pact panel | TAP Plastics | Black UV-stabilised polymer sheet, cut to size for skins / trays / dividers | 1 "cut-panel lot" | **Custom cut — needs a released DXF that doesn't exist yet** | tapplastics.com …/hypact_vhmw_polyethylene/527 |
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

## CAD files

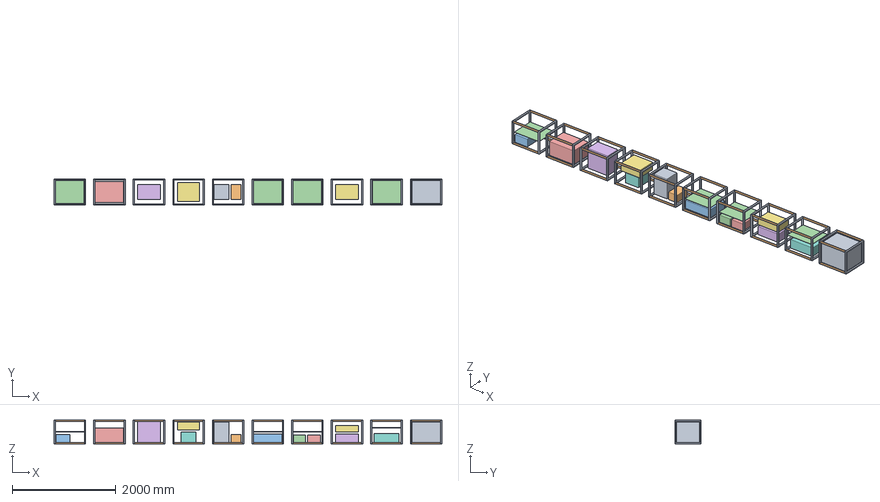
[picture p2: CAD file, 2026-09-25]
Bear Necessities/BN-family-10-modules.step
7467.6 x 508.0 x 457.2 mm

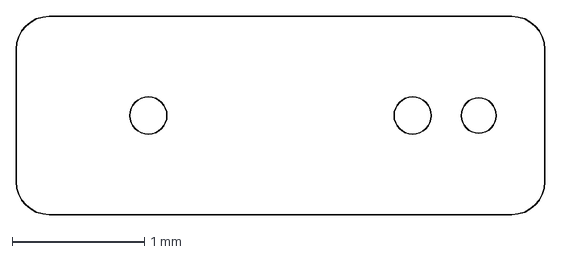
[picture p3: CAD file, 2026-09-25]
Bear Necessities/product/build-plans/drawings/C-01-anchor-plate-FLAT.dxf
4.00 x 1.50 mm

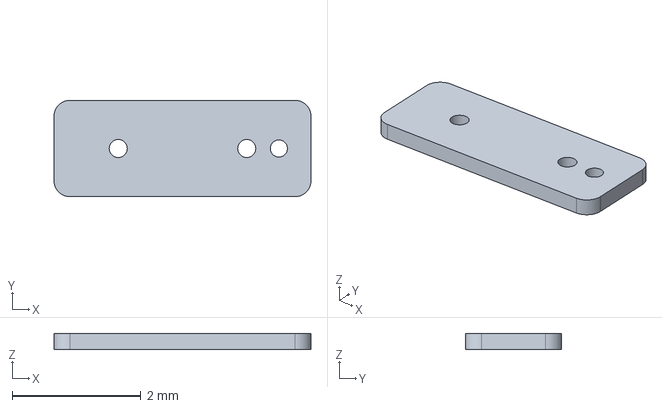
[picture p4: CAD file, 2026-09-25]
Bear Necessities/product/drawings/C-01-anchor-plate.step
4.00 x 1.50 x 0.25 mm

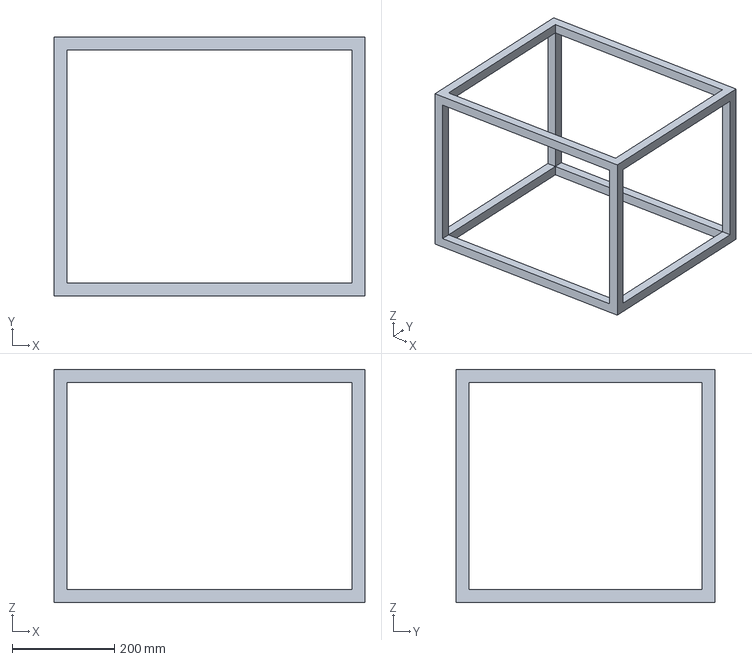
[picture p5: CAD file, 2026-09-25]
Fusion CAD Agent/specs/reference/BN-FRAME-base.step
609.6 x 508.0 x 457.2 mm

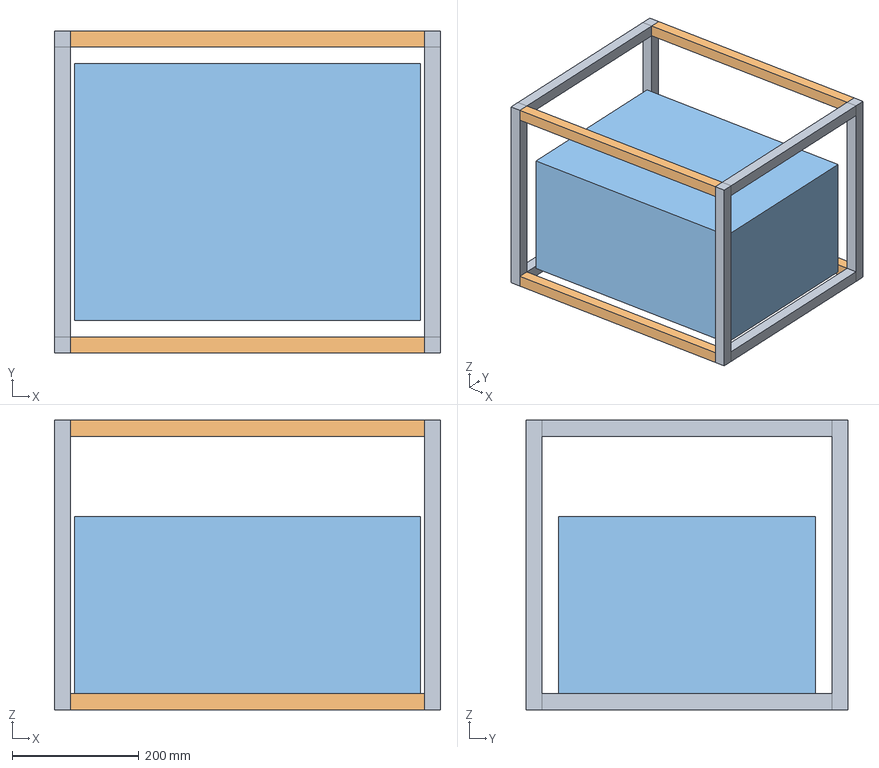
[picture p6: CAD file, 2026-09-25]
Mac Mini Setup/tools/cad-product-agent/production/ten-modules/exports/BN-M02.step
609.6 x 508.0 x 457.2 mm

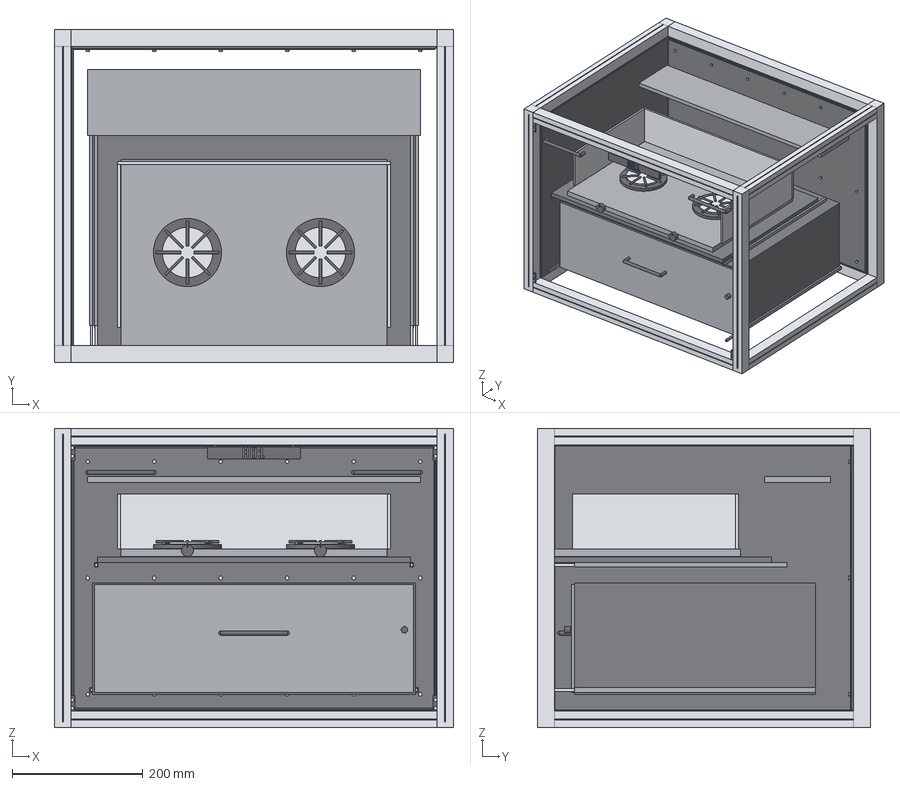
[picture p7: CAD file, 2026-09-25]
Mac Mini Setup/tools/cad-product-agent/production/ten-modules/fusion-native/exports/BN-M01/BN-M01.step
609.6 x 508.0 x 457.2 mm

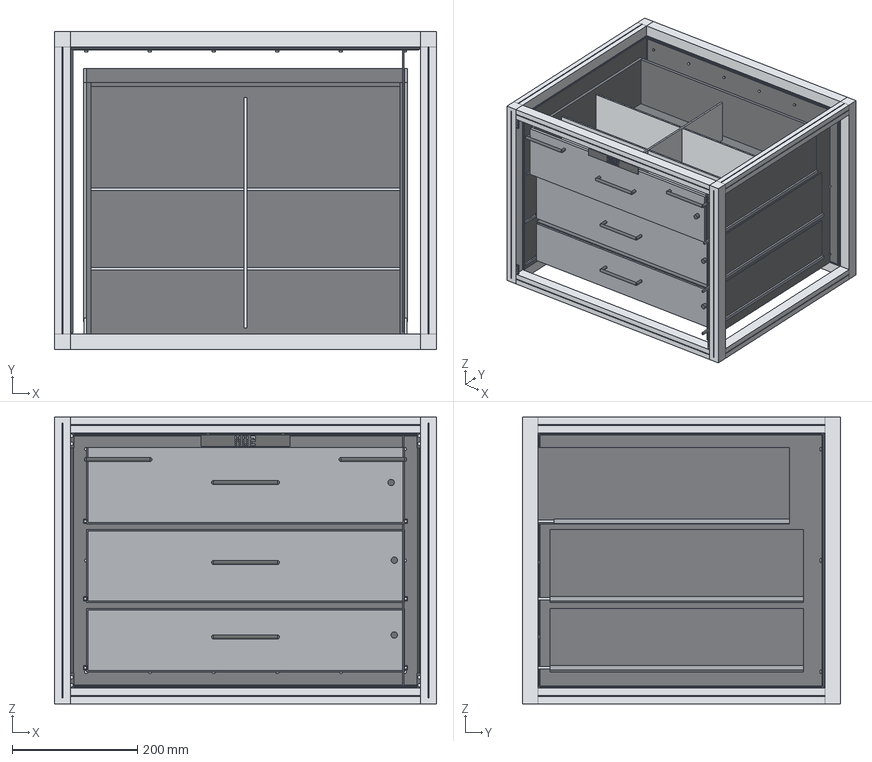
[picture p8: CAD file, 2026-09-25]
Mac Mini Setup/tools/cad-product-agent/production/ten-modules/fusion-native/exports/BN-M02/BN-M02.step
609.6 x 508.0 x 457.2 mm

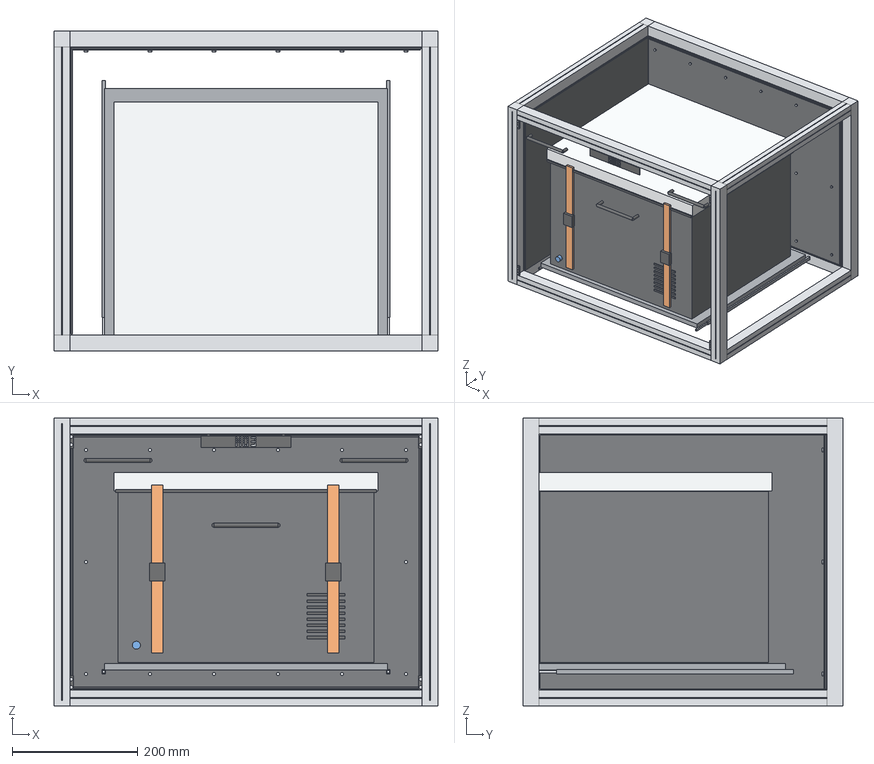
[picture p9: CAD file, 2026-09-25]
Mac Mini Setup/tools/cad-product-agent/production/ten-modules/fusion-native/exports/BN-M03/BN-M03.step
609.6 x 508.0 x 457.2 mm

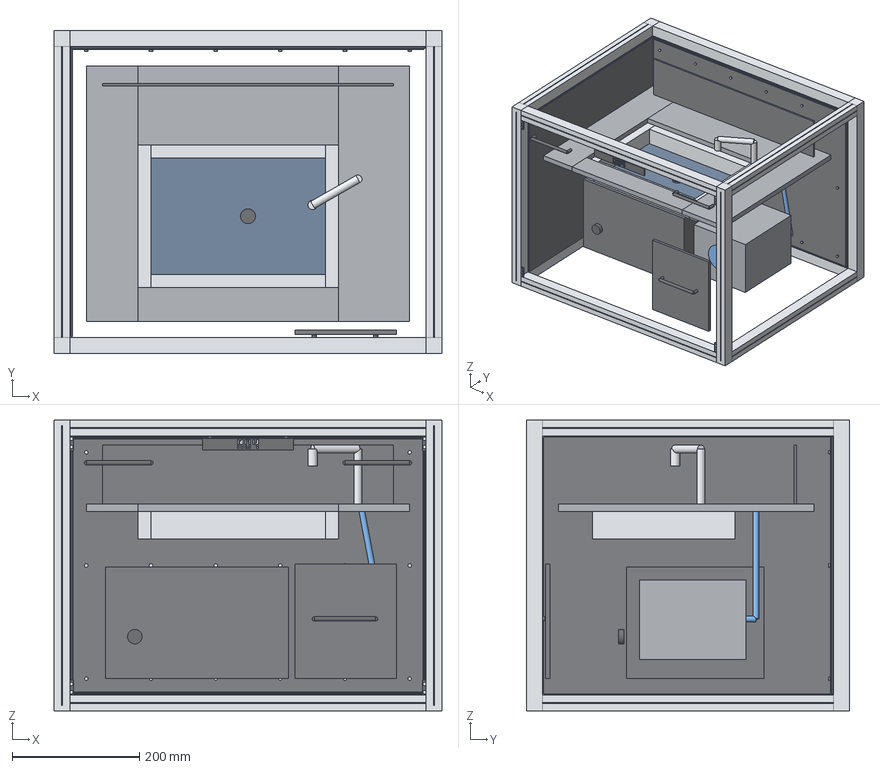
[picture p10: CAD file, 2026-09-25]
Mac Mini Setup/tools/cad-product-agent/production/ten-modules/fusion-native/exports/BN-M04/BN-M04.step
609.6 x 508.0 x 457.2 mm

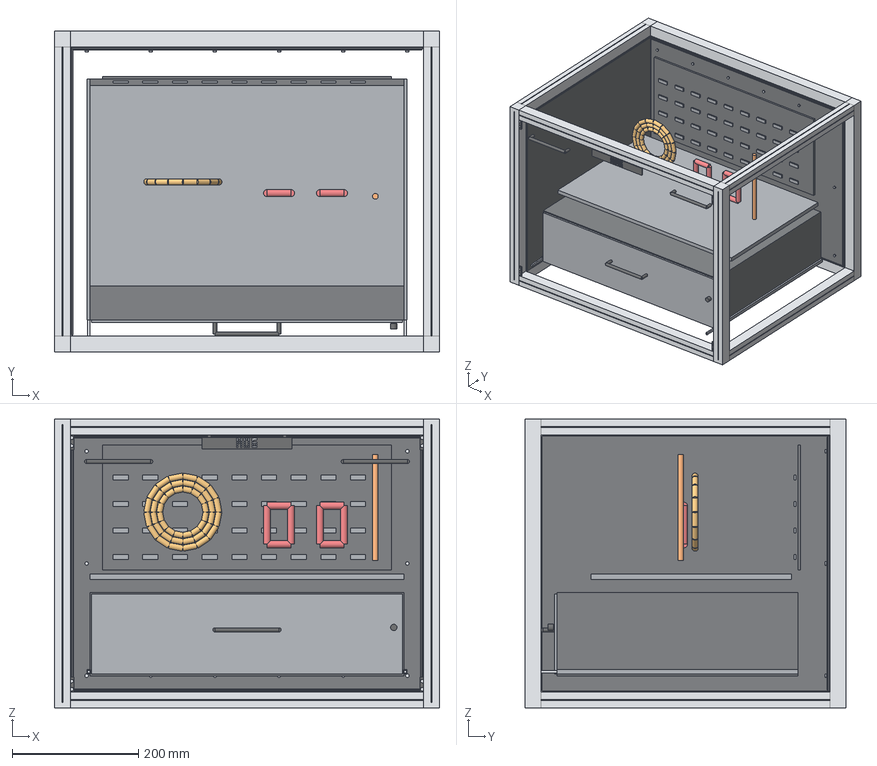
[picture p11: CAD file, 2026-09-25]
Mac Mini Setup/tools/cad-product-agent/production/ten-modules/fusion-native/exports/BN-M06/BN-M06.step
609.6 x 508.0 x 457.2 mm

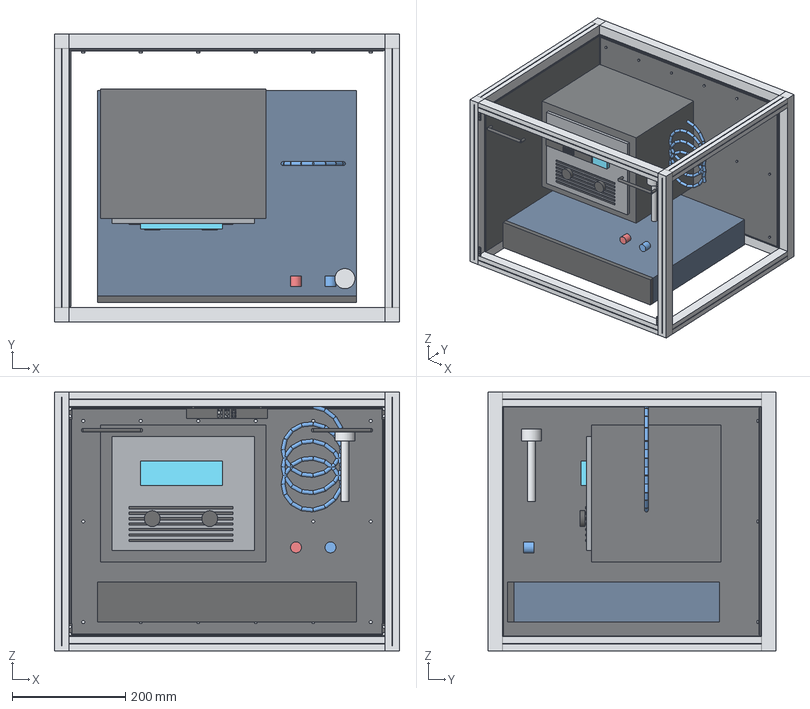
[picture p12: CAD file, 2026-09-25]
Mac Mini Setup/tools/cad-product-agent/production/ten-modules/fusion-native/exports/BN-M08/BN-M08.step
609.6 x 508.0 x 457.2 mm

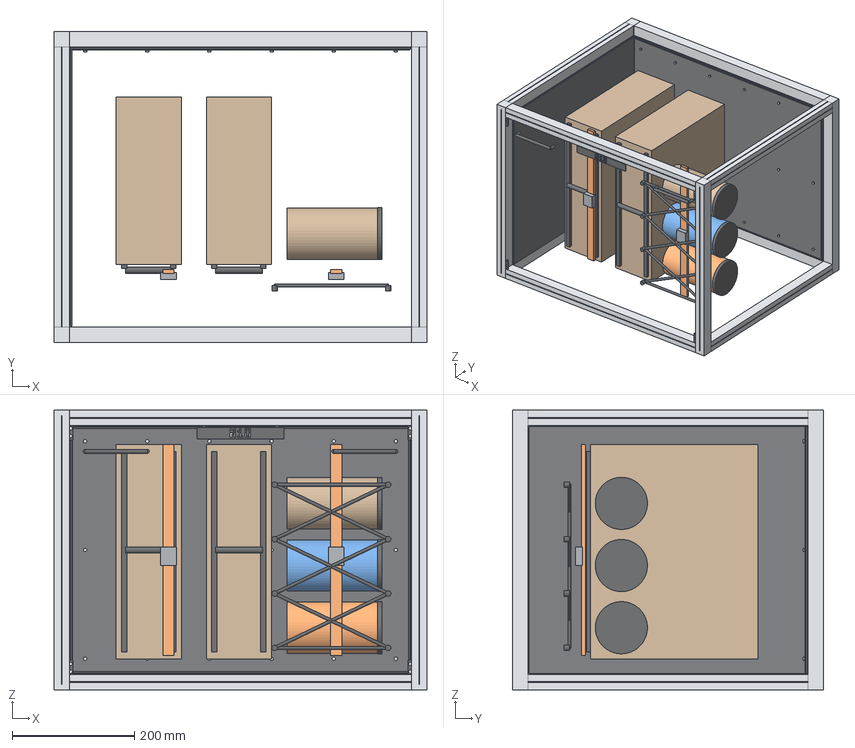
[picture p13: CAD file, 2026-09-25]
Mac Mini Setup/tools/cad-product-agent/production/ten-modules/fusion-native/exports/BN-M10/BN-M10.step
609.6 x 508.0 x 457.2 mm

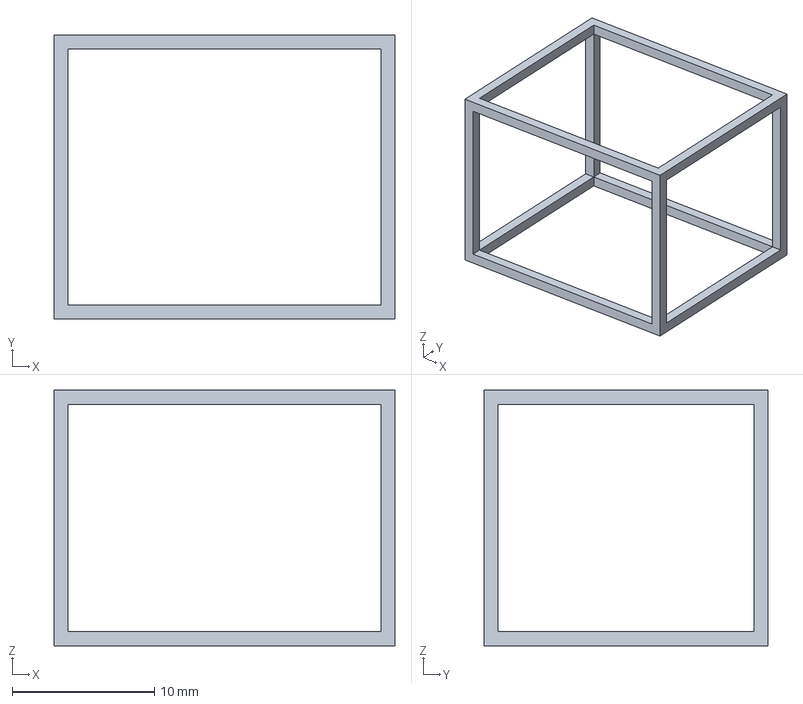
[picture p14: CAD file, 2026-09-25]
Bear Necessities/product/drawings/base-frame-ots.step
24.0 x 20.0 x 18.0 mm

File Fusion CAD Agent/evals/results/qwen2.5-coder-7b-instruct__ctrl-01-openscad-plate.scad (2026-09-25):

```openscad
cube(size = [100, 60, 6]);
```

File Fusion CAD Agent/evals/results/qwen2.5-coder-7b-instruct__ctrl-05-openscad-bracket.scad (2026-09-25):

```openscad
module l_bracket(leg1_length, leg2_length, thickness, width, hole_diameter) {
    difference() {
        union() {
            cube([leg1_length, thickness, width]);
            translate([leg2_length - hole_diameter / 2, thickness / 2, width / 2])
                cylinder(h = leg1_length, r = hole_diameter / 2);
            translate([leg2_length - hole_diameter / 2, thickness / 2 + width / 2, width / 2])
                cylinder(h = leg1_length, r = hole_diameter / 2);
        }
        translate([leg1_length - thickness / 2, 0, width / 2])
            cube([thickness, leg1_length, width]);
        translate([leg1_length - thickness / 2 + hole_diameter / 2, leg1_length - hole_diameter / 2, width / 2])
            cylinder(h = thickness, r = hole_diameter / 2);
        translate([leg1_length - thickness / 2 + hole_diameter / 2, leg1_length - hole_diameter / 2 + width / 2, width / 2])
            cylinder(h = thickness, r = hole_diameter / 2);
    }
}

l_bracket(leg1_length = 80, leg2_length = 60, thickness = 5, width = 40, hole_diameter = 6);
```

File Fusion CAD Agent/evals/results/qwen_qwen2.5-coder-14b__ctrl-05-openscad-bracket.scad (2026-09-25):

```scad
// Dimensions
leg_length1 = 80;
leg_length2 = 60;
thickness = 5;
width = 40;
hole_diameter = 6;
gusset_height = 20;

// L-bracket
module l_bracket() {
    // First leg
    translate([0, 0, 0]) cube([width, thickness, leg_length1]);
    
    // Second leg
    translate([0, width - thickness, 0]) cube([thickness, width, leg_length2]);
    
    // Gusset
    translate([(width - thickness) / 2, thickness, leg_length1]) {
        rotate([0, 90, 0]) cube([gusset_height, thickness, width - thickness]);
    }
    
    // Holes in the first leg
    translate([width / 2, thickness / 2, hole_diameter / 2]) cylinder(h = leg_length1, r = hole_diameter / 2);
    translate([width / 2, width - thickness - hole_diameter / 2, hole_diameter / 2]) cylinder(h = leg_length1, r = hole_diameter / 2);
    
    // Holes in the second leg
    translate([thickness / 2, width - thickness / 2, hole_diameter / 2 + leg_length1]) cylinder(h = leg_length2, r = hole_diameter / 2);
    translate([thickness / 2, width - thickness - hole_diameter / 2, hole_diameter / 2 + leg_length1]) cylinder(h = leg_length2, r = hole_diameter / 2);
}

// Render the L-bracket
l_bracket();
```

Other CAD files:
Fusion CAD Agent/exports/overland-base-frame.dxf
Mac Mini Setup/tools/cad-product-agent/production/ten-modules/fusion-native/exports/BN-M05/BN-M05.step
Mac Mini Setup/tools/cad-product-agent/production/ten-modules/fusion-native/exports/BN-M07/BN-M07.step
Mac Mini Setup/tools/cad-product-agent/production/ten-modules/fusion-native/exports/BN-M09/BN-M09.step
Bear Necessities/product/build-plans/drawings/base-frame-ots.stl
Bear Necessities/product/drawings/base-frame-ots.stl
Fusion CAD Agent/exports/C-01-anchor-plate.stl
Fusion CAD Agent/exports/PROTOTYPE-overland-base-frame.dxf
Fusion CAD Agent/exports/base-frame-3d.step
Fusion CAD Agent/exports/base-frame-3d.stl
Fusion CAD Agent/exports/base-frame-ots.stl
Fusion CAD Agent/exports/overland-base-frame-best.dxf
Fusion CAD Agent/specs/reference/BN-FRAME-base-authored.step
Fusion CAD Agent/specs/reference/BN-FRAME-base.stl
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

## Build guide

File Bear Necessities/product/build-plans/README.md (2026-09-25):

# Bear Necessities — Modular Overland Frame · Build Plans (v1 draft)

A downloadable build pack for the Bear Necessities frame: a bolt-together
24 × 20 × 18 in aluminium-extrusion module that slides into a vehicle cargo bay.
This pack lets you order the parts and assemble the frame from catalog components.

**Draft status:** this is a v1 draft assembled from the project's CAD and BOM on
2026-09-08. It has **not** been through a customer, an editor, or a build. Read
`00-status-and-limitations.md` before doing anything else — it is not boilerplate.

---

## What's in this pack

| File | What it gives you |
|---|---|
| `00-status-and-limitations.md` | **Read first.** What is verified, what is not, what is deliberately left out, and how to think about buying this. |
| `01-frame-cut-list-and-bom.md` | The two-cut-length cut list and the frame bill of materials, with real vendor part numbers and where to buy. Prices are blank on purpose — you get a live quote. |
| `02-frame-assembly-guide.md` | Step-by-step assembly of the bare frame from the parts in file 01. |
| `03-anchor-plate-C-01.md` | The one custom part — a flat laser-cut plate — with its dimensioned drawing and how to get it cut. |
| `04-module-concepts.md` | The ten module concepts (cook, fridge, water, power, …): what each is built around, the off-the-shelf appliance it uses, and what each one still needs before it's a finished build. Reference material, not step-by-step instructions. |
| `05-off-the-shelf-parts-catalog.md` | Every catalog component referenced across the ten modules, with vendor, part number, source URL and buy-status. |
| `06-configurations.md` | Six trip-kit combinations of modules and which vehicles each fits. |
| `drawings/` | `C-01-anchor-plate-FLAT.dxf` + `.png` + `.step`, and `base-frame-ots.step` / `.stl` / `-ISO.svg` for the frame. |

## What this pack is NOT

- **Not a vehicle-mounting guide.** The bracket that anchors a module to the
  vehicle floor (part "C-02") is **not in this pack**. It is not designed yet —
  see `00-status-and-limitations.md` §3. Do not attach a loaded module to a
  moving vehicle using anything in here.
- **Not load-rated.** No part in this pack carries a tested load rating, safety
  factor, or fastener torque spec. The frame joint design is a concept, not a
  tested joint.
- **Not a finished product.** No prototype of this frame has ever been built.
  You would be the first.
- **Not panel/skin drawings.** The side and back panels are called out as
  "cut-to-size from sheet," but the actual panel dimensions and hole patterns
  are not drawn yet.

## Who this is for

Someone who builds with 80/20-style aluminium extrusion, wants a proven-on-paper
starting geometry and parts list for a vehicle camp module, and is comfortable
doing their own engineering for anything load-bearing — especially the vehicle
attachment. If you want a turnkey, tested, bolt-in product, this isn't that yet.

## Units

All dimensions are in **inches** unless stated otherwise. Note the units caveat
on the CAD files in `03-anchor-plate-C-01.md` and `00-status-and-limitations.md`
§5 — the STEP/DXF files carry a millimetre unit tag that does not match their
inch geometry, and must be imported with units forced to inches.

## Licence / terms (placeholder — decide before selling)

To be set by Bear Necessities before this pack is sold. Suggested shape: personal
single-build licence, no resale or redistribution of the files, no warranty, and
an explicit "you are responsible for engineering the vehicle attachment and any
load-bearing joint" acknowledgement at purchase. See
`00-status-and-limitations.md` §7.

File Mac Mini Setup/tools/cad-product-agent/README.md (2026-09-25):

# Professional offline CAD product agent

Portable orchestration layer for the existing `Fusion CAD Agent` project. It turns a product brief into an auditable overnight **release candidate**, never an automatically released manufacturing package.

## Architecture

```text
Bear Necessities product requirements
        ↓ schema + source + tolerance gates
MLX planning/review model
        ↓ explicit feature/member plan
MLX coding model → CadQuery preflight → numeric validator
        ↓ best attempt preserved
MLX coding model → Fusion MCP → fresh document → numeric verification
        ↓ screenshot + exports
MLX vision review → visual defect report (advisory only)
        ↓
artifact/release gate → AWAITING_HUMAN_REVIEW
        ↓ human checks fit/load/tolerances/drawing
RELEASED manually
```

The model is never the source of truth for measurements, tolerances, loads, materials, catalog part numbers, or release approval. Those are structured inputs with provenance.

## Why two geometry passes

- **CadQuery first:** headless, deterministic, fast, and strong numeric validation. It can run overnight even if Fusion is signed out or unavailable.
- **Fusion second:** builds the native design through Fusion's local MCP server, checks the live document, captures screenshots, and provides traceback-driven repair.
- **Drawing draft:** the existing ezdxf loop remains the deterministic 2D path. Fusion's `DrawingManager.createDrawing` API is Preview as of July 2026, so it is not a dependable unattended production dependency.

## Commands

```bash
python3 professional_pipeline.py validate templates/bear-base-frame.job.json
python3 professional_pipeline.py run templates/bear-base-frame.job.json --dry-run
python3 professional_pipeline.py run templates/bear-base-frame.job.json
python3 professional_pipeline.py release-check runs/BN-MCS-BASE-001/<timestamp>
```

By default the pipeline discovers sibling projects under the shared Claude folder. Override with `--fusion-root` and `--mac-mini-root` after migration.

## Job states

- `DRAFT`: incomplete; no model calls.
- `BLOCKED_NEEDS_MEASUREMENT`: measured interfaces missing; no model calls.
- `READY_PROTOTYPE`: may build and validate prototypes, but cannot be released.
- `READY_RELEASE_CANDIDATE`: engineering inputs complete; may build a candidate.
- `AWAITING_HUMAN_REVIEW`: automated gates passed; human inspection required.
- `RELEASED`: set manually outside this runner after signoff.

## Professional quality gates

1. Every critical interface has a value, tolerance, source type, and source reference.
2. Material, process, units, and design envelope are explicit.
3. Release candidates require a defined load case and safety-factor target.
4. A part-specific deterministic validator must exist before the job is READY.
5. Solid validation checks dimensions, volume/mass proxy, solid count, and validity.
6. Assemblies require an interference check and BOM reconciliation. A joined-body
   `geometry_proxy` is acceptable for prototypes only; release candidates must
   declare a native assembly, expected component count, and executable validators.
7. Drawings require orthographic views, dimensions, tolerances, material/process notes, revision, and title-block data.
8. Visual-model review can flag omissions but cannot override numeric validation.
9. No result overwrites the best prior attempt or a released artifact.
10. Human review is always required before fabrication, purchase, or publication.

Release validator contract: both validator scripts accept `--job`,
`--fusion-root`, and `--out-name`, return nonzero on failure, and write their
evidence beside the other exports for archival.

## Installation

`install-framework.sh` copies this source into `Fusion CAD Agent/professional/`. The Mac mini bootstrap can run that installer after the shared Claude folder is migrated.

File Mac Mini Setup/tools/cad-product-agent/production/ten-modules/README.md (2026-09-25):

# Ten-module local-model production study

This package began as a validated packaging study and now also contains a native,
visually complete Fusion concept family. It is not a fabrication-released family.
Qwen2.5-Coder-14B ran locally in LM Studio and produced the initial ten-module
concept JSON and CadQuery implementation. The raw outputs are preserved. The
CAD script was repaired only in response to executable validation failures:
CadQuery export API misuse, nested compounds, and missing inner-frame clearance.

## Outputs

- `fusion_native/`: self-contained Fusion MCP builder, client, one-command runner,
  deterministic native-file validator, and local-VLM family reviewer.
- `fusion-native/exports/`: ten separate F3D/STEP/STL/OBJ module files, matching
  1600×1200 isometric/front PNGs, per-module build reports, and family QA evidence.
- `VISUAL-DESIGN-BRIEF.md` and `local-model-visual-review.md`: comparable-product
  cues and the preserved Qwen2.5-Coder-14B local design review.

- `module-family.json`: sourced component envelopes, disposition, and blockers.
- `procurement-bom.csv`: buy/source/custom/rejected list. Zero-quantity rejected
  rows are deliberate warnings against buying plausible components that do not fit.
- `prototype-buy-list.csv`: deliberately small first-purchase list; it avoids
  committing to ten frames before one physical frame and payload fit check pass.
- `SUPPLIER-RFQ-DRAFT.md`: ready-to-send commercial/cut-tolerance inquiry.
- `PHYSICAL-TEST-PLAN.md` and `RELEASE-EVIDENCE-CHECKLIST.md`: objective path
  from packaging prototype to manually released product.
- `build_ten_modules.py`: validator-repaired local-model geometry generator.
- `exports/BN-M01.step` through `BN-M10.step` and matching STL/SVG/JSON files.
  These are the original package-envelope prototypes and are superseded for
  visual use by `fusion-native/exports/`.
- `exports/BN-family-10-modules.step`: all ten modules spaced 30 inches apart.
- `local-model-cad-response.md`: untouched local model response.
- `jobs/`: ten machine-readable framework jobs with sourcing and release gates.
- `clearance-report.json` and `bom-reconciliation-report.json`: deterministic
  evidence consumed by the family validator.

All ten frames use 8 × 18-inch and 4 × 22-inch extrusion. Across the family,
that is 80 × 18-inch and 40 × 22-inch pieces (2,320 inches / 193.33 feet total).

The packaging gate uses the true 22 × 18 × 16-inch clear region inside the
1-inch frame, not merely the 24 × 20 × 18 outside envelope. This rejected both
22.1-inch-wide Milwaukee PACKOUT candidates even though they look like an easy
fit from outside dimensions alone.

## Production boundary

Do not place production orders yet. Extrusion sample quantities and one of each
candidate component are reasonable for fit prototypes, but frame joinery,
vehicle anchoring, dynamic loads, ventilation, plumbing, hot-use behavior,
electrical routing, and custom panel drawings remain engineering gates.

The native Fusion files are suitable for website concept presentation, but that
visual completion does not waive the engineering and physical-release boundary.

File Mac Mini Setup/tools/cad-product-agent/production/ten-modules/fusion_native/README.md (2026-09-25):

# Native Fusion ten-module pipeline

This is the API-driven replacement for the earlier box-envelope prototypes. It
creates ten separate, editable Fusion archives with colored, named components
and customer-facing visual detail, then blocks success until deterministic,
hash-bound visual, and web-evidence checks pass.

## One-command run

Fusion must be open with **Preferences > General > API > Fusion MCP Server**
enabled on port 27182. LM Studio must serve the OpenAI-compatible API on port
1234 with `qwen/qwen2.5-coder-14b` and `google/gemma-4-e4b` available. The
30-cycle runner in `../iterations/` must have produced a 300-review PASS ledger.

```bash
python3 run_native_pipeline.py --probe
python3 run_native_pipeline.py
```

The runner is self-contained and uses only Python's standard library. It:

1. Initializes a real MCP session and proves the Execute/Read/Update tools exist.
2. Verifies the configured vision model is exposed by LM Studio.
3. Injects the selected output path, validated Qwen revision ledger, and curated
   OTS catalog, then executes `build_native_modules.py` inside live Fusion.
4. Creates a fresh Fusion document for each module and exports it before closing.
5. Runs `validate_native_family.py` against files, dimensions, named components,
   frame members, OTS traceability, 300-review provenance, materials, image
   dimensions, and distinct F3D hashes.
6. On the Mac mini, runs `review_native_family.py` over all ten isometric views
   using the local vision model and records each input image hash. A PASS with
   any blocking or missing finding is rejected as contradictory.
7. Runs `validate_visual_completion.py`, requiring three current checks per
   module: deterministic cues, a hash-bound local-VLM or independent Codex
   inspection PASS, and a cited comparable-product or selected OTS-product
   page. The 16 GB laptop uses the independent path because its local-VLM
   canary exposed duplicate JIT loading; see `../iterations/LM-STUDIO-SAFE-PROFILES.md`.

Use `--skip-build` to re-run gates on existing files or `--skip-vision` for a
fast numeric/file-only development pass. The normal release-evidence run skips
neither.

## Output contract

Each `fusion-native/exports/BN-M##/` directory contains:

- `.f3d` — native multi-component Fusion archive
- `.step` — neutral assembly exchange file
- `.stl` — single visualization/reference mesh
- `.obj` + `.mtl` — colored visualization mesh and material library
- `-iso.png` and `-front.png` — transparent 1600×1200 views
- `-build.json` — dimensions, part registry, visual cues, and export evidence

Family-level evidence:

- `family-build-report.json`
- `native-validation-report.json`
- `local-vlm-visual-review.json`
- `native-pipeline-run.json` when the one-command runner is used end to end
- `triple-visual-validation-report.json` — 30/30 visual completion checks
- `../iterations/runs/iteration-ledger.json` — 30 Qwen cycles / 300 module reviews
- `../iterations/boms/` — ten separate order-linked prototype BOMs and combined BOM

For handoff, `fusion-native/Bear-Necessities-Native-Fusion-Modules.zip` bundles
all ten separate module directories plus the final visual and machine evidence.

## Quality boundary

These files are visually complete product-concept CAD suitable for website
concept imagery and design review. They are not fabrication release: structural
loads, joints, panel gauges, slide ratings, anchors, plumbing/electrical safety,
tolerances, and physical testing remain governed by the existing release gates.

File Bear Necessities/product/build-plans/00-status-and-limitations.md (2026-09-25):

# 00 — Status and limitations

**This is the most important file in the pack.** Everything else assumes you have
read it. It is written to the same standard the project holds itself to: no
invented numbers, and every gap named rather than papered over.

---

## 1. The one-line summary

The **frame geometry and its catalog parts list are real and internally
verified**. The **frame joint design, every load rating, the vehicle mount, and
the module interiors are not** — they are concepts pending engineering and a
physical build that has not happened.

---

## 2. What is actually verified

| Item | Status | Evidence it traces to |
|---|---|---|
| Frame outside envelope 24 × 20 × 18 in | **Verified in CAD** | Ten native Fusion assemblies measured 24.0016 × 20.0016 × 18.0016 in, inside a 0.01 in concept tolerance. Deterministic geometry gates pass. |
| Two cut lengths only: 8 × 18 in + 4 × 22 in (12 members, 232 in / 19.33 ft total) | **Verified in CAD + BOM** | `bom-reconciliation-report.json` confirms 80 × 18 in and 40 × 22 in across the ten-module family (8 + 4 per frame). |
| Frame profile: 1 × 1 in "10 Series" T-slot extrusion | **Verified against vendor pages** | 80/20 part `1010-S`; TNUTZ `EX-1010` stated 100% compatible, cut to length from the product page in 1/16 in steps, ~48 h. Part numbers checked 2026-08-20 against 8020.net and tnutz.com. |
| Clear internal volume 22 × 18 × 16 in (1 in inset each face) | **Verified in CAD** | `clearance-report.json`, 0.125 in six-face free-clearance rule. |
| C-01 anchor plate geometry (4.000 × 1.500 × 0.250 in, hole pattern) | **Verified in CAD** | Built in CadQuery, independently re-measured in Autodesk Fusion at 4.0000 × 1.5000 × 0.2500 in, volume 1.4417 in³ — agrees to four decimals. |
| The ten module concepts exist as distinct CAD assemblies with renders | **Verified as concept models** | `DELIVERY-README.md`: ten `.f3d`/STEP/STL sets, 33/33 completion audit, 300 schema-validated model reviews. Explicitly "visually complete product-concept assemblies, not fabrication-release drawings." |
| The six configurations fit the vehicles they claim | **Verified by solver** | `config_solver.py --validate-all`, 6 configurations, 0 with no fitting vehicle. |

---

## 3. What is NOT resolved — and why it is left out of v1

### 3a. The vehicle mount (part "C-02") — deferred entirely

This is the single most important exclusion. The frame has a lock feature (part
C-01, a plate on the module) that is meant to pin to a matching bracket bolted to
the vehicle floor. **That vehicle-side bracket is not designed.**

- Factory cargo tie-down spacing is **not published** by the manufacturers for
  any of the target vehicles (4Runner, Bronco, Wrangler, Sprinter, Tacoma,
  Transit, Gladiator, ProMaster, GX/Land Cruiser, Outback). The project checked.
- A generated or estimated hole pattern produces a bracket that does not bolt to
  the vehicle — the project's own notes call this "the single most expensive
  error this project can make," and the design queue is deliberately gated to
  refuse to run without real measurements.
- Even the "universal L-track" version of the bracket has **pin diameter and
  plate thickness recorded as assumptions until a load case is defined.**

**A load attached to a moving vehicle is a safety item.** There is no honest way
to ship guidance for it from the current design. v1 covers the frame; the
vehicle attachment is your engineering problem until Bear Necessities publishes a
measured, load-cased C-02. If you need the module restrained for transport now,
use rated cargo straps to the vehicle's own anchor points and treat the module
as unsecured cargo, not as a fixed installation.

### 3b. Frame joint design — concept only

The cut list is firm. **How the twelve members bolt together is not released.**

- The current concept uses 80/20 `4132` gusseted inside-corner brackets (24 per
  frame) with `3393` fastener assemblies (48 per frame). Those are real catalog
  parts and the pack lists them.
- But the project marks this joint **`ENGINEERING_HOLD`**: "joint release
  requires dynamic test." The bracket type and count are an engineering
  assumption, not a tested result. A concealed-anchor alternative (`3395` /
  TNUTZ `AF-010`) is carried at quantity zero as an unevaluated option.
- Source files disagree on the exact fastener SKU (`3393` vs `3395`). This pack
  uses `3393` because that is what the current procurement BOM and the
  production-readiness audit specify for the `4132` bracket; both are 80/20
  catalog parts and you should confirm the correct one with 80/20 when you order.

### 3c. No load ratings, torque specs, or safety factor

None exist. The project's physical test plan leaves every load magnitude blank
"until Conor approves intended payload and vehicle deceleration cases."
Specifically undefined:

- Fastener install torque (get 80/20's published spec for the `3393` fastener
  from the vendor — do not guess).
- Frame payload limit and the crash / rough-road load cases.
- Carry-handle load rating (the handles are "not authorized for a loaded lift
  until tested").
- Drawer-slide load ratings (the Accuride `3832` family is a "verify exact
  suffix, load" placeholder).
- Tie-down strap working load applied through the module (the NRS strap has a
  published 500 lb WLL, but "the module anchor / load path still requires
  engineering").

### 3d. Panels and skins — not drawn

The side/back panels are specified as "cut-to-size polymer sheet from a released
DXF." **Those DXFs do not exist.** Panel thickness is called "module-specific"
and unengineered. v1 gives you the frame; the enclosure is not documented.

### 3e. Module interiors — concept, with open SKUs

Every one of the ten modules has unresolved items — a custom worktop, a sourced
container, plumbing SKUs, ventilation calcs, electrical labelling. `04-module-
concepts.md` lists them per module. Treat the module sheets as design direction,
not as parts kits you can order complete.

---

## 4. No prototype has been built

This has to be stated plainly to any buyer. The frame in this pack has never been
cut, bolted, loaded, driven, or lived with. The CAD is internally consistent and
the parts are real, but **nothing here is build-verified.** The first person to
build it will find things the CAD did not — bracket access, T-nut fit, real
squareness after assembly, whether a 24 in module actually clears their wheel
wells.

**How to frame this honestly to a customer:**

- Sell it as what it is: *"validated geometry and a catalog parts list for a
  frame we designed but have not yet built — priced accordingly."*
- Do not use "tested," "proven," "field-tested," "rated," or "engineered for" in
  the listing. Use "designed," "modelled," "concept," "starting point."
- Put the no-prototype disclosure and the C-02 exclusion **above the buy button**,
  not buried in terms.
- Price it as a design reference (tens of dollars), not as an engineered product
  (hundreds). The revenue analysis for this project put the realistic figure at
  $20–80 per pack.
- Offer a refund policy that survives someone reading this file after purchase.

---

## 5. The CAD file units caveat

The STEP and DXF files in `drawings/` were exported before a unit-handling fix
landed in the project's CAD toolchain. They carry a **millimetre unit tag, but
the geometry is in inch values** (a 4.000 in plate reads as "4.0" with a
millimetre label — i.e. 25.4× too small if imported blindly).

**Before sending any file here to a shop or a CAM program:** set the import units
to **inches**, or scale by 25.4. The dimensioned drawing in
`03-anchor-plate-C-01.md` is the authoritative definition — the files are
reference geometry. A clean, correctly-tagged release DXF is a pre-sale to-do
for Bear Necessities.

---

## 6. What a buyer will still need that this pack does not provide

1. **A vehicle-mount solution** (C-02) — measured to their vehicle, with a load
   case. The biggest gap.
2. **Fastener torque and a joint that's been load-tested** — or their own
   engineering sign-off on the `4132` bracket concept.
3. **Panel drawings** — dimensions and hole patterns for the side/back skins.
4. **A finished parts list for whichever module interior they want** — the
   module sheets get them ~70% there; the last 30% is sourcing and small custom
   parts.
5. **Live prices and lead times** — everything in the BOM is quote-on-request.
6. **Their own fit check** — that a 24 in-wide module clears their wheel wells
   and passes through their tailgate opening. The project's own worksheet
   (`MEASUREMENT-WORKSHEET.md`) is the tool for this; a Subaru Outback in
   particular may not fit.

---

## 7. Recommended pre-sale checklist for Bear Necessities

Before this pack goes on sale, in rough priority order:

- [ ] Re-export the C-01 and base-frame CAD with correct inch unit tags, or
      replace them with a clean release DXF.
- [ ] Decide and write the licence / no-warranty / buyer-responsibility terms
      (§1 of the README is a placeholder).
- [ ] Get one live quote for the frame BOM so the listing can state a real
      "parts cost from ~$X" figure instead of "get a quote."
- [ ] Confirm the `3393` vs `3395` fastener question with 80/20.
- [ ] Build one frame. Even an unloaded bench build closes most of §4 and lets
      the assembly guide be written from reality instead of from CAD.
- [ ] Trademark search on "Bear Necessities" before putting it on a storefront.

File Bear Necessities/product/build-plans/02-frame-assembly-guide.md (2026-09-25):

# 02 — Frame assembly guide

Assembles the bare 24 × 20 × 18 in frame from the parts in
`01-frame-cut-list-and-bom.md`.

> **Not build-verified.** No one has assembled this frame yet. This sequence is
> derived from the CAD geometry and standard 80/20-style extrusion practice, not
> from a build. Expect to discover bracket-access and T-nut-fit details the CAD
> did not show. If you find the sequence wants changing, it probably does —
> please tell Bear Necessities.
>
> **Torque is not specified.** Follow 80/20's published torque specification for
> the `3393` fastener (request from the vendor). Do not guess a value.

---

## Before you start

**You have:**

- 8 × profile cut to 18 in, 4 × profile cut to 22 in (12 pieces).
- 24 × `4132` gusseted corner brackets.
- 48 × `3393` bolt + T-nut assemblies.

**You need (not supplied):**

- Hex/Allen key or driver bit matching the `3393` bolt head.
- A torque wrench/driver capable of 80/20's specified value.
- A machinist's square or framing square.
- A rubber mallet.
- A flat, level assembly surface at least 30 × 30 in.
- Calipers or a tape measure you trust to 1/32 in.

**Read 80/20's own assembly instructions for the `4132` bracket and `3393`
fastener first.** They cover slide-in vs. drop-in T-nut orientation, thread
engagement, and the correct torque — none of which this pack invents.

---

## Naming

| Name | Length | Qty | Position |
|---|---|---:|---|
| Post | 18 in | 4 | The 4 vertical corners |
| Depth rail | 18 in | 4 | Front-to-back, 2 at the top, 2 at the bottom |
| Width rail | 22 in | 4 | Left-to-right, 2 at the top, 2 at the bottom |

The **outside** dimensions are 24 (width) × 20 (depth) × 18 (height). The width
rails and depth rails butt into the faces of the posts, so a post sits "inside"
the ends of the top and bottom rectangles.

---

## Step 1 — Build the bottom rectangle

1. Lay 2 width rails (22 in) and 2 depth rails (18 in) on the flat surface in a
   rectangle: width rails front and back, depth rails left and right, forming a
   24 × 20 in outside footprint.
2. At each of the 4 corners, the end of a depth rail butts against the inside
   face of a width rail (or vice versa — pick one convention and keep it on all
   four corners and both rectangles).
3. Slide a `3393` T-nut into the slot of each member at each joint, position one
   `4132` bracket spanning the corner on the **inside** face, and start both
   bolts by hand. One bracket per corner at this stage.
4. Square the rectangle: measure both diagonals, adjust until they are equal,
   then snug all 8 bolts. Re-check the diagonals. Torque to spec.
5. Result: a flat 24 × 20 in rectangle, 8 bolts, 4 brackets used.

## Step 2 — Stand the four posts

1. Stand a post vertically at each corner of the bottom rectangle, on the
   outside of the rail ends so the post's outside faces are flush with the
   24 × 20 in footprint.
2. At each corner the post now meets **two** bottom rails (one width, one depth).
   Add one `4132` bracket between the post and each of those two rails — 2
   brackets per corner.
3. T-nuts in, bolts started by hand, then check each post for plumb with the
   square against two adjacent faces before torquing. Torque all bolts.
4. Brackets used so far: 4 (bottom rectangle corners) + 8 (post-to-bottom-rail,
   2 per corner) = 12.

## Step 3 — Build the top rectangle in place

1. Lay the 2 remaining width rails and 2 remaining depth rails across the tops of
   the posts in the same rectangle pattern as the bottom.
2. At each corner: one `4132` bracket between the two top rails (the top-rectangle
   corner joint), and one bracket between the post top and **one** of the two top
   rails. That is 2 brackets per corner.

   > This gives 3 brackets total per top corner (rail-to-rail, post-to-rail ×1)
   > and matches the 24-bracket total: 8 corners × 3 = 24. The bottom corners get
   > their 3rd bracket from Step 1; the top corners get theirs here. If your
   > bracket access says to distribute them differently, do — the count is 3 per
   > corner, the exact placement is not a released detail.

3. T-nuts, hand-start, square the top rectangle by diagonal, check the whole
   frame stands square (measure the two diagonals on all four vertical faces),
   then torque everything.

## Step 4 — Final check

- All 24 brackets installed, all 48 bolts torqued to 80/20's spec.
- Outside dimensions: 24 × 20 in footprint, 18 in tall, within your build
  tolerance. (The CAD target is 24 × 20 × 18 in; the concept models hold
  ±0.002 in, a physical frame will not — decide your own acceptance band, the
  project's physical test plan calls for measuring "both diagonals on all six
  faces" and leaves the tolerance blank pending a drawing.)
- Every vertical face square (equal diagonals).
- No bracket slipping in a slot when you push on the frame by hand.
- Re-check torque after the first day and after the first drive — the project's
  test plan explicitly calls for a torque-retention re-check, and vibration
  loosening of the joint is one of the open engineering questions.

---

## What comes after the frame

The bare frame is the end of this pack's step-by-step content. To go further you
need material this pack does not fully provide:

- **Panels / skins** — cut-to-size sheet, but the panel drawings don't exist yet
  (`00-status-and-limitations.md` §3d).
- **Handles, feet, gasket, anti-skid tread** — off-the-shelf, listed in
  `05-off-the-shelf-parts-catalog.md`, but load ratings for the handles are
  untested.
- **The module interior** — see `04-module-concepts.md` for the ten concepts and
  what each still needs.
- **Vehicle mounting** — **not in this pack.** `00-status-and-limitations.md`
  §3a. Until Bear Necessities publishes a measured C-02 bracket, restrain the
  module with rated cargo straps to the vehicle's own anchor points and treat it
  as cargo, not as a fixed install.

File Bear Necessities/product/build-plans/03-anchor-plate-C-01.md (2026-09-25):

# 03 — Custom part C-01: Module Anchor Plate

The one non-catalog part in the frame. A flat plate, laser or waterjet cut from
sheet — no bends, no machining, no welds. Dozens of shops can make it from the
DXF.

> **What C-01 does — and its limit in v1.** C-01 bolts into a T-slot on the
> underside of a module base rail and presents a pin hole. It is the *module
> half* of the lock. The *vehicle half* (part C-02, a floor bracket the pin
> drops into) **is not in this pack and is not designed** — see
> `00-status-and-limitations.md` §3a. So in v1, C-01 is useful as a
> module-to-module or module-to-your-own-anchor interface. Do not treat the
> C-01 pin hole as a vehicle attachment until Bear Necessities publishes C-02
> with a load case.
>
> **Structural numbers are assumptions.** The 0.250 in thickness and the pin
> hole diameter are the project's design assumptions "until a load case is
> defined." They are not tested. Worst case is presumably a fully loaded module
> under hard braking; that number is not established, and it is what sets both
> the plate thickness and the pin size.

---

## Dimensioned drawing (authoritative)

This table is the definition. The CAD files are reference geometry only (see the
units caveat below).

```
                 4.000                          all corners R0.250
       ┌───────────────────────────┐
       │   O           O       o   │   1.500
       └───────────────────────────┘
         │<--2.000-->│       │
       mounting holes         pin hole
       (2x, on centreline)    (1x, on centreline)
```

| Feature | Value | Tolerance | Why it matters |
|---|---|---|---|
| Overall plate | 4.000 × 1.500 × 0.250 in | — | fits along a base rail |
| Material | 5052-H32 aluminium sheet, 0.250 in | sheet tolerance | shear strength (assumption — see note above) |
| Mounting holes | 2 × Ø0.281 in (clearance for 1/4-20), on the plate centreline, **2.000 in apart**, symmetric about plate centre | ±0.010 in on spacing | must land on the 1 in T-slot centres |
| Pin hole | 1 × Ø0.266 in (clearance for a 1/4 in quick-release pin), on the centreline, **1.500 in from plate centre** toward one end | dia +0.005 / −0.000; position ±0.010 in | must accept a 1/4 in pin freely and align with the mating part |
| Corner radius | 0.250 in, all four corners | — | — |

**Free to change:** outline styling beyond the stated radius, lightening
cutouts, edge chamfer, logo etch.

**Quantity:** 2 per module (one each side).

### Geometry verification

The CAD was built in CadQuery and independently re-measured in Autodesk Fusion at
**4.0000 × 1.5000 × 0.2500 in, volume 1.4417 in³** — matching the analytical
target to four decimal places. The hole positions in `drawings/
C-01-anchor-plate-FLAT.dxf` were checked against this table: 4 outline lines,
4 corner arcs, 3 circles at ±1.000 in (mounting) and +1.500 in (pin) on the
centreline. Geometry is correct.

---

## The fasteners and pin (NOT custom — buy these)

| Item | Spec | Notes |
|---|---|---|
| Plate-to-frame bolts | 1/4-20, length to suit your rail + T-nut stack | With slide-in T-nuts sized for the 10 Series slot. Confirm length against your actual assembly. |
| Locking pin | Off-the-shelf **1/4 in** ball-lock or detent quick-release pin | Do not design a pin. Grip length to suit the stack of parts it passes through. |

The project's standing rule: **never design a fastener or a pin that a catalog
part can do.**

---

## How to get it cut

1. Send `drawings/C-01-anchor-plate-FLAT.dxf` to a laser or waterjet shop
   (SendCutSend, OSH Cut, Xometry, or a local shop).
2. **Tell them the units are inches.** The DXF carries a millimetre unit tag that
   does not match its inch geometry (see below) — a shop importing it "as drawn"
   will quote a 4 mm part. Specify: material 5052-H32, thickness 0.250 in,
   overall 4.000 × 1.500 in, quantity as needed.
3. Ask for deburred edges. No finish required for function; anodize if you want
   corrosion resistance.
4. Flat parts quote fast and cheap from a DXF — this is deliberately the only
   custom part in the design.

### CAD file units caveat (important)

`drawings/C-01-anchor-plate-FLAT.dxf` and `.step` were exported before a
unit-handling fix in the project's CAD toolchain. The **geometry is in inch
values but the file declares millimetres**:

- The DXF header sets `$INSUNITS = 4` (mm) and `$MEASUREMENT = 1` (metric), while
  the entities are drawn at inch magnitudes (the plate is "4.0" long).
- The STEP declares `SI_UNIT(.MILLI.,.METRE.)` with points at ±2.0, ±0.75, 0.25
  — inch numbers.

**Fix on import:** set units to inches, or scale by 25.4. The dimensioned table
above is the authoritative source if there is ever any doubt. Producing a clean,
correctly-tagged release DXF is a pre-sale to-do for Bear Necessities
(`00-status-and-limitations.md` §7).

---

## Reference files

- `drawings/C-01-anchor-plate-FLAT.dxf` — the flat profile a shop quotes from.
- `drawings/C-01-anchor-plate-FLAT.png` — visual reference of the flat profile.
- `drawings/C-01-anchor-plate.step` — 3D solid.

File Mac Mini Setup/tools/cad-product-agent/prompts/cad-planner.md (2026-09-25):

# CAD planning role

You are the planning stage of a professional product CAD workflow. Produce JSON only. Do not generate CAD code.

For each component, return:

- named parameters and units;
- datum/origin strategy;
- ordered feature plan;
- explicit placement table or coordinate formula for repeated members;
- interfaces copied verbatim from the job, including tolerances and sources;
- manufacturing constraints;
- expected bounding box, volume/mass proxy, solid count, and symmetry;
- assembly mates/joints and intended clearances;
- proposed deterministic checks;
- unresolved information as blockers, never invented values.

Prefer configurations and reusable parameter sets over copied geometry. Prefer catalog components over custom parts. For Bear Necessities, preserve the standing rule that custom components should remain flat, laser-cut sheet parts unless a documented product decision changes it.

For T-slot frames, distinguish the outside envelope from the usable internal
clear envelope. Every purchased component must pass a six-face clearance test
against structural members, plus separate access, lid/door travel, ventilation,
cable/hose bend radius, and service-removal checks. A product that fits the
outside dimensions but intersects a rail or post is a rejection, not a near-fit.

Assign every BOM item exactly one disposition: `ORDERABLE`, `SOURCE_REQUIRED`,
`CUSTOM_REQUIRED`, `ENGINEERING_HOLD`, or `REJECTED_DOES_NOT_FIT`. Never replace
an unknown SKU with a plausible one. Preserve rejected candidates in the BOM at
quantity zero so purchasing cannot accidentally revive them.

Treat alternative joint architectures as mutually exclusive BOM branches. A
gusset bracket's manufacturer-specified bolt/T-nut hardware is not interchangeable
with an internal anchor fastener. For the Bear Necessities 10 Series frame, the
4132 external bracket uses two 3393 mounting assemblies; 3395/AF-010 is a separate
counterbored internal-joint option. Never sum both options into a production BOM.

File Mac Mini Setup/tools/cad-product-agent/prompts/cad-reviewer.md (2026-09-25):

# Independent CAD reviewer role

Review a generated candidate against the job and validation report. You did not author the geometry.

Return JSON with `verdict`, `blocking_findings`, `nonblocking_findings`, and `recommended_next_checks`. A PASS is forbidden when any required input, deterministic validator, interface dimension, tolerance, load case, interference result, BOM match, or deliverable is absent.

Never infer correctness from a screenshot. Use screenshots only to flag likely omissions, view problems, impossible assembly orientation, or poor documentation. Numeric geometry checks and sourced engineering inputs take precedence.

Never approve fabrication, structural adequacy, vehicle fitment, supplier part numbers, or release. The highest automated verdict is `READY_FOR_HUMAN_REVIEW`.

Reject a packaging review unless component envelopes are checked against the
true internal clear region and all moving/service envelopes are recorded.
Outside-bounding-box compliance alone is insufficient. Confirm BOM rows expose
availability and disposition; components with unknown or unsuitable fit must be
flagged rather than silently omitted.

For every catalog bracket, reconcile its mounting hardware against the current
manufacturer page. Reject BOMs that attach a plausible but unrelated fastener or
that combine mutually exclusive external and internal joint methods.

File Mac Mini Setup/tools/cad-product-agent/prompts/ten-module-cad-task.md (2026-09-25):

Write one complete standalone Python 3.12 script using CadQuery 2.8 that exports
ten prototype component-envelope models as STEP and STL plus one combined STEP.
Return only a single Python code block. The script receives its output directory
from `sys.argv[1]`, creates it, and never accesses the network.

All dimensions below are inches. CadQuery dimensions must be millimetres using
`IN = 25.4`. Each module uses the identical 24W x 20D x 18H outer frame. Model
the frame as twelve separate 1 x 1 rectangular extrusion-envelope solids:

```
def frame_members():
    W,D,H,P = 24*IN,20*IN,18*IN,1*IN
    members=[]
    for x in (0,W-P):
        for y in (0,D-P): members.append(cq.Workplane("XY").box(P,P,H,centered=False).translate((x,y,0)))
    for y in (0,D-P):
        for z in (0,H-P): members.append(cq.Workplane("XY").box(W-2*P,P,P,centered=False).translate((P,y,z)))
    for x in (0,W-P):
        for z in (0,H-P): members.append(cq.Workplane("XY").box(P,D-2*P,P,centered=False).translate((x,P,z)))
    return members
```

Add each internal component as a simple box envelope using these records
`(id, label, [(name, size_xyz_inches, origin_xyz_inches), ...])`:

```
BN-M01 Cook Station: packed_stove (10.75,10.75,6.25) at (1,1,1); worktop (21.5,17.5,.25) at (1.25,1.25,9)
BN-M02 Dry Pantry: pantry_box (21.5,16,11) at (1.25,2,1)
BN-M03 Fridge Freezer: fridge (17.5,11.3,15.8) at (3.25,4.35,1)
BN-M04 Sink Wash: sink (16.5,14.6,6) at (3.75,2.7,10.5); grey_tank (11.5,11.25,8) at (6.25,4.4,1)
BN-M05 Fresh Water: water_tank (11.5,11.25,15.75) at (1,4.4,1); pump_bay (7.5,11.25,6) at (14,4.4,1)
BN-M06 Recovery Utility: tool_box (21.5,16,6.5) at (1.25,2,1); shelf (21.5,17.5,.25) at (1.25,1.25,9)
BN-M07 Power Hub: power_station (9.21,9.13,5.75) at (1,1,1); cable_case (10,9.13,5.75) at (12,1,1); shelf (21.5,17.5,.25) at (1.25,1.25,9)
BN-M08 Hot Water Shower: heater (17.7,11.4,6.6) at (3.15,4.3,1); hose_bay (17.7,11.4,5) at (3.15,4.3,9)
BN-M09 Field Office Camera: equipment_case (21.96,13.97,8.98) at (1.02,3,1); worktop (21.5,17.5,.25) at (1.25,1.25,12)
BN-M10 Camp Furniture Soft Goods: soft_gear_bay (21.5,17.5,15.5) at (1.25,1.25,1)
```

For every module:
- Keep the 12 frame members as separate solids in a `cq.Compound` along with
  component boxes. Do not fuse them.
- Verify each component box is wholly inside 0..24, 0..20, 0..18 inches before
  export; raise with the module ID and component name if not.
- Verify exactly 12 frame members and total solids = 12 + component count.
- Export `<ID>.step` and `<ID>.stl`; use a filesystem-safe ID.
- Write `<ID>.json` containing ID, label, outside bbox, frame member count,
  component count, and component records.

Create a combined family STEP by translating each complete module 30 inches
along X in ID order. Write `family-summary.json` with all ten verification
records. Add comments that geometry is a packaging prototype, not structural
analysis or manufacturer CAD.

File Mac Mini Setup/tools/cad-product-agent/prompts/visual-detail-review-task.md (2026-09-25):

Review the attached text brief for ten 24x20x18-inch aluminum-extrusion overland
modules. Act as a local senior industrial-design reviewer. Identify, for each
module, the five most important visible details that make its function immediately
recognizable in an isometric CAD screenshot. Then give shared family-style rules,
likely visual failure modes, and a final binary inspection checklist. Do not invent
supplier part numbers, dimensions, certifications, or structural claims. Favor
manufacturable panels, slides, handles, latches, vents, straps, hoses and controls.
Your output will be used to review deterministic Fusion API models, not as authority
for engineering release.

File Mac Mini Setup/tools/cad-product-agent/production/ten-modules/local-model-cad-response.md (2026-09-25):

```python
import sys
import os
import json
import cadquery as cq

IN = 25.4

def frame_members():
    W, D, H, P = 24 * IN, 20 * IN, 18 * IN, 1 * IN
    members = []
    for x in (0, W - P):
        for y in (0, D - P):
            members.append(cq.Workplane("XY").box(P, P, H, centered=False).translate((x, y, 0)))
    for y in (0, D - P):
        for z in (0, H - P):
            members.append(cq.Workplane("XY").box(W - 2 * P, P, P, centered=False).translate((P, y, z)))
    for x in (0, W - P):
        for z in (0, H - P):
            members.append(cq.Workplane("XY").box(P, D - 2 * P, P, centered=False).translate((x, P, z)))
    return members

def create_module(id, label, components):
    W, D, H = 24 * IN, 20 * IN, 18 * IN
    frame = cq.Compound.makeCompound(frame_members())
    
    component_solids = []
    for name, size_xyz_inches, origin_xyz_inches in components:
        size_xyz_mm = [dim * IN for dim in size_xyz_inches]
        origin_xyz_mm = [dim * IN for dim in origin_xyz_inches]
        
        if any(x < 0 or x > W for x in (origin_xyz_mm[0], origin_xyz_mm[0] + size_xyz_mm[0])) or \
           any(y < 0 or y > D for y in (origin_xyz_mm[1], origin_xyz_mm[1] + size_xyz_mm[1])) or \
           any(z < 0 or z > H for z in (origin_xyz_mm[2], origin_xyz_mm[2] + size_xyz_mm[2])):
            raise ValueError(f"Component {name} in module {id} is out of bounds.")
        
        component = cq.Workplane("XY").box(*size_xyz_mm, centered=False).translate(origin_xyz_mm)
        component_solids.append(component)
    
    total_solids = cq.Compound.makeCompound([frame] + component_solids)
    
    if len(total_solids.Solids()) != 12 + len(component_solids):
        raise ValueError(f"Module {id} does not have the correct number of solids.")
    
    return total_solids, component_solids

def export_module(output_dir, id, label, components):
    module_id = id.replace('-', '_').replace(' ', '_')
    total_solids, component_solids = create_module(id, label, components)
    
    step_file = os.path.join(output_dir, f"{module_id}.step")
    stl_file = os.path.join(output_dir, f"{module_id}.stl")
    
    total_solids.exportSTEP(step_file)
    total_solids.exportSTL(stl_file)
    
    module_info = {
        "id": id,
        "label": label,
        "outside_bbox": [24 * IN, 20 * IN, 18 * IN],
        "frame_member_count": 12,
        "component_count": len(component_solids),
        "components": components
    }
    
    json_file = os.path.join(output_dir, f"{module_id}.json")
    with open(json_file, 'w') as f:
        json.dump(module_info, f, indent=4)

def create_family(output_dir):
    modules = [
        ("BN-M01", "Cook Station", [("packed_stove", (10.75, 10.75, 6.25), (1, 1, 1)), ("worktop", (21.5, 17.5, .25), (1.25, 1.25, 9))]),
        ("BN-M02", "Dry Pantry", [("pantry_box", (22.1, 16.2, 11.1), (.95, 1.9, 1))]),
        ("BN-M03", "Fridge Freezer", [("fridge", (17.5, 11.3, 15.8), (3.25, 4.35, 1))]),
        ("BN-M04", "Sink Wash", [("sink", (16.5, 14.6, 6), (3.75, 2.7, 10.5)), ("grey_tank", (11.5, 11.25, 8), (6.25, 4.4, 1))]),
        ("BN-M05", "Fresh Water", [("water_tank", (11.5, 11.25, 15.75), (1, 4.4, 1)), ("pump_bay", (7.5, 11.25, 6), (14, 4.4, 1))]),
        ("BN-M06", "Recovery Utility", [("tool_box", (22.1, 16.2, 6.5), (.95, 1.9, 1)), ("shelf", (21.5, 17.5, .25), (1.25, 1.25, 9))]),
        ("BN-M07", "Power Hub", [("power_station", (9.21, 9.13, 5.75), (1, 1, 1)), ("cable_case", (10, 9.13, 5.75), (12, 1, 1)), ("shelf", (21.5, 17.5, .25), (1.25, 1.25, 9))]),
        ("BN-M08", "Hot Water Shower", [("heater", (17.7, 11.4, 6.6), (3.15, 4.3, 1)), ("hose_bay", (17.7, 11.4, 5), (3.15, 4.3, 9))]),
        ("BN-M09", "Field Office Camera", [("equipment_case", (21.96, 13.97, 8.98), (1.02, 3, 1)), ("worktop", (21.5, 17.5, .25), (1.25, 1.25, 12))]),
        ("BN-M10", "Camp Furniture Soft Goods", [("soft_gear_bay", (21.5, 17.5, 15.5), (1.25, 1.25, 1))])
    ]
    
    family_solids = []
    for i, (id, label, components) in enumerate(modules):
        module_id = id.replace('-', '_').replace(' ', '_')
        total_solids, _ = create_module(id, label, components)
        family_solids.append(total_solids.translate((i * 30 * IN, 0, 0)))
    
    family_compound = cq.Compound.makeCompound(family_solids)
    family_step_file = os.path.join(output_dir, "family.step")
    family_compound.exportSTEP(family_step_file)
    
    family_summary = {
        "modules": [module[0] for module in modules]
    }
    
    json_file = os.path.join(output_dir, "family-summary.json")
    with open(json_file, 'w') as f:
        json.dump(family_summary, f, indent=4)

if __name__ == "__main__":
    if len(sys.argv) != 2:
        print("Usage: python script.py <output_directory>")
        sys.exit(1)
    
    output_dir = sys.argv[1]
    os.makedirs(output_dir, exist_ok=True)
    
    for id, label, components in [
        ("BN-M01", "Cook Station", [("packed_stove", (10.75, 10.75, 6.25), (1, 1, 1)), ("worktop", (21.5, 17.5, .25), (1.25, 1.25, 9))]),
        ("BN-M02", "Dry Pantry", [("pantry_box", (22.1, 16.2, 11.1), (.95, 1.9, 1))]),
        ("BN-M03", "Fridge Freezer", [("fridge", (17.5, 11.3, 15.8), (3.25, 4.35, 1))]),
        ("BN-M04", "Sink Wash", [("sink", (16.5, 14.6, 6), (3.75, 2.7, 10.5)), ("grey_tank", (11.5, 11.25, 8), (6.25, 4.4, 1))]),
        ("BN-M05", "Fresh Water", [("water_tank", (11.5, 11.25, 15.75), (1, 4.4, 1)), ("pump_bay", (7.5, 11.25, 6), (14, 4.4, 1))]),
        ("BN-M06", "Recovery Utility", [("tool_box", (22.1, 16.2, 6.5), (.95, 1.9, 1)), ("shelf", (21.5, 17.5, .25), (1.25, 1.25, 9))]),
        ("BN-M07", "Power Hub", [("power_station", (9.21, 9.13, 5.75), (1, 1, 1)), ("cable_case", (10, 9.13, 5.75), (12, 1, 1)), ("shelf", (21.5, 17.5, .25), (1.25, 1.25, 9))]),
        ("BN-M08", "Hot Water Shower", [("heater", (17.7, 11.4, 6.6), (3.15, 4.3, 1)), ("hose_bay", (17.7, 11.4, 5), (3.15, 4.3, 9))]),
        ("BN-M09", "Field Office Camera", [("equipment_case", (21.96, 13.97, 8.98), (1.02, 3, 1)), ("worktop", (21.5, 17.5, .25), (1.25, 1.25, 12))]),
        ("BN-M10", "Camp Furniture Soft Goods", [("soft_gear_bay", (21.5, 17.5, 15.5), (1.25, 1.25, 1))])
    ]:
        export_module(output_dir, id, label, components)
    
    create_family(output_dir)
```

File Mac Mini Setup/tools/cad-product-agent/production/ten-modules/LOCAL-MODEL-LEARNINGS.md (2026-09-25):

# Local-model learning record — ten-module study

## Model and evidence

- Model: `qwen/qwen2.5-coder-14b`, MLX 4-bit, run locally through LM Studio.
- Raw concept result: `../../ten-module-local-model-output.json`.
- Raw CAD result: `local-model-cad-response.md`.
- Validated implementation: `build_ten_modules.py`.

## Failures observed

1. “JSON only” was insufficient: the concept result omitted quotes around several
   keys and therefore was not valid JSON.
2. The model invented product requirements and safety claims (for example
   arbitrary wattages and UL statements) without sources.
3. It treated commercially plausible components as packageable without checking
   the frame's true internal clear region.
4. Generated CadQuery used nonexistent instance export methods and nested a
   compound with Workplanes instead of making one compound from Shapes.
5. It duplicated the module table rather than defining one reusable data source.
6. The inherited BOM combined 4132 external brackets with 3395 internal anchor
   fasteners. Manufacturer evidence showed 4132 calls for two 3393 assemblies;
   3395/AF-010 is a separate counterbored joint architecture.

## Repairs promoted into the framework

- Planning and review prompts now require six-face checks against the internal
  clear envelope, not merely the outside bounding box.
- BOM items require explicit dispositions and rejected candidates remain visible
  at quantity zero.
- The family validator checks ten unique IDs, the two-length extrusion invariant,
  internal clearance, every STEP/STL/SVG/JSON artifact, BOM vocabulary, and
  rejected-item zero quantities.
- CAD prompts retain copyable member-table scaffolding because local models apply
  spatial patterns reliably but do not derive them reliably.
- Supplier SKUs and compliance claims remain curated human/web inputs; the model
  is never allowed to invent them.
- The geometry generator now reads `module-family.json` directly, eliminating its
  duplicated hard-coded module table.
- Ten generated jobs and separate clearance/BOM evidence reports make each
  prototype independently gateable.

## Native Fusion/API pass — 2026-08-25

- Fusion's built-in MCP server at `http://127.0.0.1:27182/mcp` is now the
  authoritative execution path. The reusable client performs initialize plus
  `notifications/initialized`, verifies Execute/Read/Update availability, and
  preserves server exceptions.
- Every module is created in a fresh direct-design document and exported as a
  separate F3D/STEP/STL/OBJ package. Product geometry is organized as named
  native components; a monolithic body or one anonymous envelope cannot pass.
- Stable Fusion appearances are copied from locale-independent library IDs and
  assigned to bodies. This preserved silver aluminum, dark panels, controls,
  water colors, straps, screens, and soft goods in F3D and OBJ/MTL.
- ViewCube-relative `Front` and `IsoTopRight` views looked at the closed rear of
  the product on this installation. The framework now uses explicit camera eye,
  target, and up vectors from the open customer-facing side.
- The current OBJ API requires `createOBJExportOptions(geometry, filename)`;
  constructing it without a filename failed before any partial family could be
  accepted. Component evidence is counted from the persisted part registry,
  not the nonexistent `rootComponent.allComponents` property.
- Visual QA must be iterative. The first native files were structurally detailed
  but hid burners, drawers, and the sink behind panels/countertops. Direct image
  inspection drove explicit camera correction, an open sink well, an open pantry
  divider tray, readable geometric module badges, visible shower connectors,
  contrasting straps, and exposed water/office service equipment.
- LM Studio's Gemma vision model does not accept this server's optional
  `json_object` response-format parameter. The reviewer uses ordinary chat output,
  parses answer or reasoning channels, retries malformed responses, hashes every
  image, and remains advisory to the deterministic gate.
- Final evidence requires three independent views of completion: named-feature
  and file/dimension checks, direct visual inspection against current comparable
  products, and a local-VLM pass over all ten current image hashes.

## Next evals before production use

1. Require valid output against a JSON Schema on three repeated passes.
2. Test a repair loop seeded with the exact CadQuery traceback from this run.
3. Add collision/access envelopes for lids, drawers, hoses and wiring.
4. Extend the now-working native multi-component assemblies with engineering
   joints, interference/motion envelopes, and parameterized fabrication features.
5. Benchmark the 30B-class Mac mini model on this exact ten-module fixture and
   compare first-pass schema validity, API correctness, and packaging rejections.

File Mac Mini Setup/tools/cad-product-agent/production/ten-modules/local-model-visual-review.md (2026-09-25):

### BN-M01 Cook Station

**Five Most Important Visible Details:**
1. Pull-out stove tray
2. Two burners
3. Control knobs
4. Three-sided wind guard
5. Upper prep surface

**Shared Family-Style Rules:**
1. Silver extrusion frame with visible dark slot lines.
2. Dark charcoal side/back panels, black mounting hardware.
3. Rounded pull handles, visible fasteners, and a small front module ID plate.

**Likely Visual Failure Modes:**
1. Missing or obscured pull-out stove tray.
2. Burners not clearly visible or incorrectly positioned.
3. Control knobs missing or not functional-looking.
4. Wind guard incomplete or poorly integrated.
5. Prep surface too small or missing.

**Binary Inspection Checklist:**
1. Pull-out stove tray present and visible.
2. Two burners present and correctly positioned.
3. Control knobs present and functional-looking.
4. Three-sided wind guard complete and integrated.
5. Upper prep surface present and appropriately sized.

### BN-M02 Dry Pantry

**Five Most Important Visible Details:**
1. Three pull-out drawers of different heights
2. Front handles/latches
3. Internal divider indication
4. Full side/back panels

**Shared Family-Style Rules:**
1. Silver extrusion frame with visible dark slot lines.
2. Dark charcoal side/back panels, black mounting hardware.
3. Rounded pull handles, visible fasteners, and a small front module ID plate.

**Likely Visual Failure Modes:**
1. Missing or incorrectly positioned drawers.
2. Handles/latches not present or poorly integrated.
3. Internal dividers missing or incorrectly indicated.
4. Side/back panels not full or poorly finished.

**Binary Inspection Checklist:**
1. Three pull-out drawers present and correctly positioned.
2. Front handles/latches present and integrated.
3. Internal dividers indicated clearly.
4. Full side/back panels present.

### BN-M03 Fridge/Freezer

**Five Most Important Visible Details:**
1. Compact top-opening fridge body
2. Lid seam
3. Front carry handle
4. Compressor vent array
5. Restraint straps and low slide tray

**Shared Family-Style Rules:**
1. Silver extrusion frame with visible dark slot lines.
2. Dark charcoal side/back panels, black mounting hardware.
3. Rounded pull handles, visible fasteners, and a small front module ID plate.

**Likely Visual Failure Modes:**
1. Fridge body missing or incorrectly positioned.
2. Lid seam not visible or poorly integrated.
3. Carry handle missing or poorly designed.
4. Compressor vent array incomplete or obscured.
5. Restraint straps and slide tray not present.

**Binary Inspection Checklist:**
1. Compact top-opening fridge body present.
2. Lid seam visible and integrated.
3. Front carry handle present and functional-looking.
4. Compressor vent array complete and visible.
5. Restraint straps and low slide tray present.

### BN-M04 Sink/Wash

**Five Most Important Visible Details:**
1. Recessed basin
2. Raised/foldable faucet
3. Drain
4. Grey-water tank
5. Pump, visible hose route

**Shared Family-Style Rules:**
1. Silver extrusion frame with visible dark slot lines.
2. Dark charcoal side/back panels, black mounting hardware.
3. Rounded pull handles, visible fasteners, and a small front module ID plate.

**Likely Visual Failure Modes:**
1. Basin missing or incorrectly recessed.
2. Faucet not raised or foldable.
3. Drain missing or obscured.
4. Grey-water tank incomplete or incorrectly positioned.
5. Pump and hose route not visible.

**Binary Inspection Checklist:**
1. Recessed basin present.
2. Raised/foldable faucet present and functional-looking.
3. Drain visible and integrated.
4. Grey-water tank complete and positioned correctly.
5. Pump and hose route visible.

### BN-M05 Fresh Water

**Five Most Important Visible Details:**
1. Blue seven-gallon tank
2. Fill cap/spigot
3. Two restraint straps
4. Pump/service bay
5. Hose and vented access panel

**Shared Family-Style Rules:**
1. Silver extrusion frame with visible dark slot lines.
2. Dark charcoal side/back panels, black mounting hardware.
3. Rounded pull handles, visible fasteners, and a small front module ID plate.

**Likely Visual Failure Modes:**
1. Tank missing or incorrectly sized.
2. Fill cap/spigot not present or obscured.
3. Restraint straps missing or incorrectly positioned.
4. Pump/service bay incomplete or poorly integrated.
5. Hose and vented access panel not visible.

**Binary Inspection Checklist:**
1. Blue seven-gallon tank present.
2. Fill cap/spigot present and functional-looking.
3. Two restraint straps present and correctly positioned.
4. Pump/service bay complete and integrated.
5. Hose and vented access panel visible.

### BN-M06 Recovery/Utility

**Five Most Important Visible Details:**
1. Lower sealed tool drawer
2. Upper shelf
3. Perforated MOLLE panel
4. Recovery-rope roll
5. Shackles/tool silhouettes and latch

**Shared Family-Style Rules:**
1. Silver extrusion frame with visible dark slot lines.
2. Dark charcoal side/back panels, black mounting hardware.
3. Rounded pull handles, visible fasteners, and a small front module ID plate.

**Likely Visual Failure Modes:**
1. Tool drawer missing or not sealed.
2. Upper shelf incomplete or poorly integrated.
3. MOLLE panel not perforated or obscured.
4. Recovery-rope roll missing or incorrectly positioned.
5. Shackles/tool silhouettes and latch not present.

**Binary Inspection Checklist:**
1. Lower sealed tool drawer present.
2. Upper shelf complete and integrated.
3. Perforated MOLLE panel visible and functional-looking.
4. Recovery-rope roll present and correctly positioned.
5. Shackles/tool silhouettes and latch present.

### BN-M07 Power Hub

**Five Most Important Visible Details:**
1. Power-station enclosure
2. Front display
3. AC/round DC and USB port cues
4. Ventilation slots
5. Cable drawer and protected pass-through

**Shared Family-Style Rules:**
1. Silver extrusion frame with visible dark slot lines.
2. Dark charcoal side/back panels, black mounting hardware.
3. Rounded pull handles, visible fasteners, and a small front module ID plate.

**Likely Visual Failure Modes:**
1. Power-station enclosure missing or incorrectly positioned.
2. Front display not visible or poorly integrated.
3. Port cues missing or obscured.
4. Ventilation slots incomplete or not visible.
5. Cable drawer and pass-through not present.

**Binary Inspection Checklist:**
1. Power-station enclosure present.
2. Front display visible and integrated.
3. AC/round DC and USB port cues present and functional-looking.
4. Ventilation slots complete and visible.
5. Cable drawer and protected pass-through present.

### BN-M08 Hot Water/Shower

**Five Most Important Visible Details:**
1. Heater face with display/knobs/vents
2. Coiled hose
3. Shower head
4. Quick-connect cues
5. Wet-storage tray

**Shared Family-Style Rules:**
1. Silver extrusion frame with visible dark slot lines.
2. Dark charcoal side/back panels, black mounting hardware.
3. Rounded pull handles, visible fasteners, and a small front module ID plate.

**Likely Visual Failure Modes:**
1. Heater face missing or incorrectly positioned.
2. Coiled hose not visible or obscured.
3. Shower head missing or poorly integrated.
4. Quick-connect cues incomplete or not visible.
5. Wet-storage tray not present.

**Binary Inspection Checklist:**
1. Heater face with display/knobs/vents present.
2. Coiled hose visible and functional-looking.
3. Shower head present and integrated.
4. Quick-connect cues complete and visible.
5. Wet-storage tray present.

### BN-M09 Field Office/Camera

**Five Most Important Visible Details:**
1. Rugged case with lid ribs/latches
2. Deployable worktop
3. Open laptop
4. Cable pass-through
5. Small accessory drawer

**Shared Family-Style Rules:**
1. Silver extrusion frame with visible dark slot lines.
2. Dark charcoal side/back panels, black mounting hardware.
3. Rounded pull handles, visible fasteners, and a small front module ID plate.

**Likely Visual Failure Modes:**
1. Rugged case missing or incorrectly designed.
2. Worktop not deployable or obscured.
3. Laptop missing or not open.
4. Cable pass-through incomplete or not visible.
5. Accessory drawer not present.

**Binary Inspection Checklist:**
1. Rugged case with lid ribs/latches present.
2. Deployable worktop visible and functional-looking.
3. Open laptop present and integrated.
4. Cable pass-through complete and visible.
5. Small accessory drawer present.

### BN-M10 Camp Furniture/Soft Goods

**Five Most Important Visible Details:**
1. Vertical folded-chair/table forms
2. Rolled fabric cylinders
3. Two compression straps
4. Front cargo-net pattern

**Shared Family-Style Rules:**
1. Silver extrusion frame with visible dark slot lines.
2. Dark charcoal side/back panels, black mounting hardware.
3. Rounded pull handles, visible fasteners, and a small front module ID plate.

**Likely Visual Failure Modes:**
1. Chair/table forms missing or incorrectly positioned.
2. Fabric cylinders not rolled or obscured.
3. Compression straps missing or incorrectly positioned.
4. Cargo-net pattern incomplete or not visible.

**Binary Inspection Checklist:**
1. Vertical folded-chair/table forms present.
2. Rolled fabric cylinders visible and functional-looking.
3. Two compression straps present and correctly positioned.
4. Front cargo-net pattern complete and visible.

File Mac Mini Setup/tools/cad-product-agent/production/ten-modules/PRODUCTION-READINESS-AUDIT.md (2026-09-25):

# Production-readiness audit

Date: 2026-08-25

| Objective requirement | Evidence | Verdict |
|---|---|---|
| Run the best suitable local model available here | LM Studio raw outputs identify `qwen/qwen2.5-coder-14b`; installed metadata shows MLX 4-bit, 14B | Proven |
| Create ten modules like the reference image | `module-family.json`; ten STEP/STL/SVG/JSON sets; combined family STEP | Proven as packaging prototypes |
| Use orderable aluminum-extrusion lengths | Common cut list is 8x18in + 4x22in; TNUTZ EX-1010 page supports both cut lengths | Proven for extrusion ordering |
| Permit drop shipment to customers | Supplier sells custom cut lengths online | Partially proven; commercial drop-ship-to-end-customer terms not yet obtained |
| Flag components that cannot be ordered online | `procurement-bom.csv` has explicit source/custom/hold/rejected dispositions | Proven |
| BOM lets purchasing begin | `prototype-buy-list.csv` gives bounded sample quantities and manufacturer links | Proven for prototype purchases, not production quantity |
| Feed learnings into local models/framework | Updated planner/reviewer prompts, family validator, ten generated jobs, clearance/BOM evidence, test, and `LOCAL-MODEL-LEARNINGS.md` | Proven |
| Ready for production | Requires load cases, native assembly joints/interference, custom panel drawings, vehicle anchor resolution, moving/service envelopes, supplier terms, physical fit/load/vibration/leak/thermal tests | Not proven |

## Hard release blockers

1. Define module mass limits and crash/rough-road load cases; approve a safety factor.
2. Select and test frame joinery. The 4132/3395 counts are an engineering hold.
3. Resolve the vehicle-side anchor and prove installation on target vehicles.
4. Source the remaining containers, plumbing, handles, feet, panels, retainers,
   hinges/latches, wiring protection, cargo nets, and straps.
5. Create toleranced flat-pattern drawings for every custom panel/retainer.
6. Model moving/service envelopes and run native Fusion interference checks.
7. Build at least one common frame and execute static load, vibration, retention,
   leak, thermal/ventilation, hot-use, corrosion and usability tests as applicable.
8. Obtain supplier commercial terms for blind/end-customer drop shipment, packaging,
   returns, substitutions, lead-time reporting and cut-tolerance acceptance.

## 2026-08-25 framework hardening addendum

- Replaced the Pelican 1535's 0.02-inch nominal side clearance with a smaller
  Pelican 1485 envelope and regenerated all CAD artifacts.
- Added a 0.125-inch six-face free-clearance gate, with explicit permitted mount
  contacts such as a component resting on the lower support plane.
- Added BOM reconciliation proving 80x18-inch and 40x22-inch EX-1010 demand.
- Corrected joint hardware: 4132 brackets pair with 3393 assemblies. The 3395 /
  TNUTZ AF-010 counterbored anchor option remains quantity zero.
- Generated ten production-framework job files. None can become `RELEASED`
  automatically and every one carries sourcing, physical-test and human gates.

The automated system must keep every module at `AWAITING_HUMAN_REVIEW` until
these items have objective evidence. No model output can waive them.

## External-evidence handoff

The exact remaining requests and tests are now executable artifacts:

- `SUPPLIER-RFQ-DRAFT.md` asks the extrusion supplier for written cut tolerance,
  kit packaging, blind drop-ship, labeling, lead-time, substitution and claims terms.
- `PHYSICAL-TEST-PLAN.md` defines incoming inspection, frame geometry, static load,
  handle cycling, vibration/retention, module safety and fulfillment tests while
  leaving unapproved load magnitudes blank.
- `RELEASE-EVIDENCE-CHECKLIST.md` maps supplier, CAD, BOM, physical and human
  evidence required for each of the ten jobs.

These artifacts close the framework/process gap. They do not substitute for the
supplier's written response, purchased sample frame or measured test results.

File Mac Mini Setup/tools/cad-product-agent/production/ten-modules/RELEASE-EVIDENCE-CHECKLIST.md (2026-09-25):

# Release evidence checklist

Complete separately for BN-M01 through BN-M10. The framework must reject release
when any required cell is blank or linked evidence is missing.

## Common frame evidence

- [ ] Approved payload, longitudinal/lateral/vertical load cases and safety factor
- [ ] Supplier cut-tolerance and direct-fulfillment terms accepted in writing
- [ ] Incoming inspection report for sample frame kit
- [ ] Released joint architecture and BOM—external 4132/3393 or internal AF-010,
      never both
- [ ] Assembly drawing, torque table and work instructions
- [ ] Static proof-load report
- [ ] Handle-cycle report
- [ ] Vibration/road and fastener-retention report
- [ ] Vehicle anchor installation and retention evidence
- [ ] Corrosion/material compatibility review

## Module evidence

- [ ] Every BOM row is orderable or has a released custom drawing and supplier
- [ ] No `SOURCE_REQUIRED`, `CUSTOM_REQUIRED`, `ENGINEERING_HOLD` or rejected
      positive-quantity row remains
- [ ] Purchased-component manufacturer drawing and revision archived
- [ ] Static six-face, moving, service and installation envelopes pass
- [ ] Native multi-component Fusion interference report passes
- [ ] STEP, native CAD, drawing PDF/DXF, BOM and revision manifest archived
- [ ] Module-specific physical tests from `PHYSICAL-TEST-PLAN.md` pass
- [ ] Labels, warnings, instructions and service/inspection intervals approved
- [ ] Packaging/drop test and one real direct-to-customer shipment pass
- [ ] Independent human reviewer signs job and manually sets `RELEASED`

## Mandatory release metadata

```text
Module ID:
Revision:
Released BOM hash:
Released CAD hash:
Released drawing hash:
Supplier evidence path:
Physical test evidence path:
Reviewer name:
Reviewer signature/date:
```

No local or cloud model may fill reviewer identity/signature or transition a job
to `RELEASED`.

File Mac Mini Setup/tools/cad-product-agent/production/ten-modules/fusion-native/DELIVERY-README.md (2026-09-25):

# Bear Necessities native Fusion module delivery

Delivered 2026-08-25 after three separate live Autodesk Fusion build/export
checkpoints and a 33/33 completion audit.

## Separate CAD assemblies

| Module | Product concept | Named components |
|---|---|---:|
| BN-M01 | Cook Station | 143 |
| BN-M02 | Dry Pantry | 139 |
| BN-M03 | Fridge Freezer | 126 |
| BN-M04 | Sink Wash | 125 |
| BN-M05 | Fresh Water | 131 |
| BN-M06 | Recovery Utility | 208 |
| BN-M07 | Power Hub | 140 |
| BN-M08 | Hot Water Shower | 174 |
| BN-M09 | Field Office Camera | 174 |
| BN-M10 | Camp Furniture Soft Goods | 133 |

Every module directory contains a distinct native `.f3d` assembly plus STEP,
STL, OBJ/MTL, front/isometric PNGs, and its machine-readable build report. All
ten measured envelopes are 24.0016 × 20.0016 × 18.0016 inches and pass the
24 × 20 × 18 target within the 0.01-inch concept gate.

## Review evidence

- 30 validated family cycles: 10 design, 10 manufacturing, 10 combined.
- 300 schema-validated module reviews with local-model provenance.
- 120 reviews used Qwen2.5 Coder 14B MLX 4-bit; after repeated IOGPUFamily
  kernel panics on the 16 GB laptop, the remaining 180 used the approved 7B
  MLX low-memory continuation profile.
- All 30 Fusion checkpoint renders were directly inspected and bound to their
  SHA-256 values. The triple visual gate combines deterministic part/cue checks,
  hash-bound image inspection, and current comparable/OTS web evidence.
- Ten native `.f3d` hashes are distinct and the final completion audit passes
  33/33 requirements.

The local model proposed and dispositioned revisions. Autodesk Fusion's Python
API built and exported the deterministic geometry; the language model was not
allowed to write arbitrary Fusion code directly or self-certify release.

## BOM and procurement boundary

`bom/modules/` contains one linked prototype BOM per module and a combined CSV.
Rows marked `HOLD_*`, `SOLD_OUT`, or `*_VERIFY` require engineering or
procurement confirmation. In BN-M03, the sold-out Engel MD-14 has quantity zero;
the MHD13F-DM alternate has quantity one and must be dimension/use/warranty
verified before purchase.

## Mac mini replication

The evidence bundle includes the revision ledger, retrieval learnings, OTS and
comparable catalogs, safe LM Studio profiles, and the one-command Mac mini
replication script. The script unloads the coding model before Fusion/vision so
they do not compete for unified memory. The 16 GB laptop profile does not run a
full local-VLM batch after a canary exposed duplicate JIT model loading.

## Release boundary

These are visually complete product-concept assemblies, not fabrication-release
drawings. Structural loads, vehicle attachment, slide ratings, panel gauges,
fastener torque, plumbing/electrical safety, tolerances, and physical testing
remain human engineering gates.

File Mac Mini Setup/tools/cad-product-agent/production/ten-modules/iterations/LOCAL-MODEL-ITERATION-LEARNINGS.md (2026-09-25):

# Local-model iteration learnings

> Retrieval artifact for LM Studio prompts. It does not modify model weights and does not release engineering.

- Required proposer: `qwen/qwen2.5-coder-14b`
- Approved/used proposer counts: `{"qwen/qwen2.5-coder-14b": 120, "qwen2.5-coder-7b-instruct": 180}`
- Model policy: `documented_low_memory_continuation`
- Validated family cycles: 30 / 30
- Validated module reviews: 300 / 300
- Adopted prototype requirements: 1
- Retained validated baselines: 299

## Durable framework rules

- Use only catalog IDs from `ots-components.json`; never invent supplier facts.
- Keep the 24 × 20 × 18 inch outer envelope and the 22 × 18 × 16 inch clear component envelope.
- Keep exactly twelve separate 1-inch 10-Series frame members: eight 18-inch and four 22-inch cuts.
- Treat local-model design findings as prototype requirements, not measurements, safety evidence, or fabrication release.
- Preserve sold-out, rejected, dealer-order, and engineering-hold dispositions in the BOM.
- Require current deterministic CAD validation and current-image visual review after a rebuild.

## BN-M01 adopted requirements

- No revision was adopted; all reviewed criteria retained the validated baseline.

## BN-M02 adopted requirements

- No revision was adopted; all reviewed criteria retained the validated baseline.

## BN-M03 adopted requirements

- **manufacturing / supplier_integrity:** Replace with alternate procurement for sold-out item. (evidence: `ENGEL-MD14`, `ENGEL-MHD13-ALT`; check: Verify alternate procurement is available and meets specifications.)

## BN-M04 adopted requirements

- No revision was adopted; all reviewed criteria retained the validated baseline.

## BN-M05 adopted requirements

- No revision was adopted; all reviewed criteria retained the validated baseline.

## BN-M06 adopted requirements

- No revision was adopted; all reviewed criteria retained the validated baseline.

## BN-M07 adopted requirements

- No revision was adopted; all reviewed criteria retained the validated baseline.

## BN-M08 adopted requirements

- No revision was adopted; all reviewed criteria retained the validated baseline.

## BN-M09 adopted requirements

- No revision was adopted; all reviewed criteria retained the validated baseline.

## BN-M10 adopted requirements

- No revision was adopted; all reviewed criteria retained the validated baseline.

## Remaining release boundary

Dynamic frame and vehicle-anchor loads, panel tolerances, slide and latch suffixes, plumbing and wiring schematics, heat clearances, physical fit, motion, leak, thermal, vibration, and road tests require qualified human review before fabrication, installation, sale, or purchase of production quantities.

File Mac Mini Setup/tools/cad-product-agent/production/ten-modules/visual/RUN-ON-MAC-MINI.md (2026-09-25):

# Running the visual sweep on the Mac mini

The ten-cycle marketing-render sweep, packaged to run unattended on the mini.
Written 2026-08-26 from a laptop run that found every fault listed below the hard
way. Nothing here is theoretical — each guard exists because something broke.

## What the job is

```
10 cycles  x  10 modules  x  2 views (hero + alpha)  =  200 ray-traced renders
```

Each cycle renders every module, scores the images with a model-free gate, asks a
local vision model a fixed checklist, and adjusts one global scene parameter.
Completed work is recorded, so the sweep resumes rather than restarting.

## Prerequisites on the mini

| Requirement | Why |
|---|---|
| A **real GUI session, logged in** | Fusion has no headless mode on macOS. This is already in the `Mac Mini Setup` plan (auto-login, FileVault off). |
| Fusion installed and **signed in** | It phones home; a signed-out Fusion cannot render. |
| Fusion MCP server enabled | Preferences → General → API → Fusion MCP Server. |
| LM Studio installed with `lms` on PATH | The sweep drives it directly to load and unload models. |
| `qwen2.5-vl-3b-instruct` downloaded | The vision checklist. Bigger is fine on the mini — see the spec note. |
| The CadQuery venv | `python3 "Bear Necessities/cad/preflight.py" --for cad` prints the command if missing. |

Do **not** pre-load models. The sweep unloads them itself before rendering; see
"GPU contention" below.

## Run it

```bash
cd "Bear Necessities/cad" && python3 preflight.py --for visuals
```

Then:

```bash
cd "Mac Mini Setup/tools/cad-product-agent/production/ten-modules/visual" && ./run.sh
```

`run.sh` is a thin wrapper that logs to a timestamped file and survives logout.
To resume after any interruption, run the same command — finished renders are
skipped.

## The five faults this job hit, and the guard for each

Every one of these was diagnosed on the laptop. They are properties of Fusion and
of this workload, not of that machine, so expect them on the mini too.

**1. Fusion wedges if you touch the render environment too early.**
Assigning `sceneSettings.backgroundEnvironment` for the first time while a
freshly imported 113-component design is open hangs Fusion permanently — alive at
0% CPU, every later API call blocking. *Guard:* the render stack is warmed on an
empty document first, which costs about a second and makes the same assignment
instant. Cold-then-heavy wedged 6 times out of 6; warm-first has never wedged.

**2. The MCP port is not stable.** After a crash-relaunch Fusion came back on
27180 rather than the documented 27182, and every tool pinned to the old number
reported Fusion missing while it was running fine. *Guard:* `bridge/fusion_port.py`
asks the OS which ports Fusion holds and confirms each with a real MCP handshake.
Nothing anywhere names a port.

**3. Killing Fusion orphans a nine-core process.** The local render worker lives
under `Contents/Libraries`, not `Contents/MacOS`, and does not die with its
parent. One was found reparented to init at 888% CPU, 12 minutes in, producing
nothing. *Guard:* shutdown takes the whole `Contents` tree and sweeps survivors.

**4. LM Studio and Fusion contend for the GPU.** Fusion's renderer is Metal-based
and so is LM Studio with `--gpu max`. With a model resident, renders fire and
never complete. *Guard:* the sweep unloads all models before rendering and loads
the vision model back only for the review phase. **This is why you must not
pre-load models.**

**5. Never close a document.** `Document.close(False)` on a never-saved import
raises a modal save prompt, and a modal dialog blocks every API call. *Guard:*
documents are never closed; Fusion is recycled instead, which discards them
silently. A graceful quit is attempted first so the crash reporter stays quiet —
its dialog is modal too, and would wedge the next launch.

## Watching it

The driver's output is streamed, not captured, so the log shows per-module
progress, Fusion memory and every recycle. A silent log means a stall.

```bash
tail -f visual/sweep-*.log
```

Per-render health goes to `render-telemetry.json`; the Fusion-side step trace to
`render-trace.log`. If something hangs, the trace names the exact line.

## Expected wall clock

Measured on a 10-core M1 Pro: **35–240 s per render**, mean 104 s over 16
successful renders. The spread is framing, not noise — the early wide framing ran
35–75 s, the final closer framing 120–240 s, because the subject and the
ray-traced ground fill far more of the frame.

At the final framing, budget **~180 s per render**:

```
200 renders x 180s              = 10.0 h
Fusion recycles (~4/cycle)      =  1.0 h
vision review, 100 modules      =  2.5 h
                                  -------
                                  ~13.5 h on a 10-core M1 Pro
```

See `HARDWARE-FROM-THIS-JOB.md` for what that implies for the mini, and for the
levers that shorten it.

## If you only want the images, not the iteration

Ten cycles is for convergence. One pass over the family is:

```bash
python3 render_module.py --all --views hero front detail
```

That is 40 renders, roughly 2 hours, and produces the full deliverable set at the
current scene settings without any model in the loop.

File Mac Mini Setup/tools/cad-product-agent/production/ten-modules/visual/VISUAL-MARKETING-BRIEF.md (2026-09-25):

# Visual marketing brief — Bear Necessities module family

Supersedes nothing. `VISUAL-DESIGN-BRIEF.md` sets the **completion** bar: is the
equipment recognizable from an isometric screenshot. That bar is met and stays met.
This document adds the **presentation** bar: would a customer believe this is a
photograph of a real product.

Both bars apply. A beautiful render of an unrecognizable box fails, and so does a
legible flat CAD capture.

## Why this exists

Measured on 2026-08-26 across all ten current `-iso.png` renders:

| Signal | Measured | What it means |
|---|---|---|
| Peak foreground luminance | 170–180 of 255 (one outlier 230) | Nothing in the frame is a specular highlight. Metal cannot read as metal. |
| Fraction above luminance 235 | **0.0000 on all ten** | Literally zero highlight pixels in the family. |
| Luminance spread within the aluminium mask | σ ≈ 12.7, near-identical on nine of ten | Faces are flat-filled, not lit. |
| Background variance | 0.00 | Fully transparent. No ground, therefore no contact shadow, therefore the module floats. |
| Distinct alpha values | 5 | Hard cut-out edge. |

The consistency is the tell: nine modules landing within 1.0 of the same σ is a
renderer signature, not ten independent lighting choices.

## Family visual language

Everything in `VISUAL-DESIGN-BRIEF.md` carries over verbatim — twelve silver
extrusion members with visible slot lines, dark charcoal infill, black hardware,
rounded pull handles, visible fasteners, the front module ID plate, the 24 × 20 × 18
frame, and the per-module required-visible-content list for BN-M01 … BN-M10.

Added on top:

**Materials.** Brushed aluminium must read as metal: an anisotropic highlight that
travels along the extrusion axis, not a uniform grey fill. Charcoal panels matte,
with enough falloff across a face to show its orientation. Rubber, glass, fabric and
painted steel each visibly distinct from the panels — currently they differ only in
albedo.

**Light.** Three-point: a key establishing form, a fill keeping the shadow side
readable rather than black, and a rim separating the frame from the background. The
key must produce a specular hit on the aluminium.

**Ground.** The module sits on a surface. A contact shadow directly beneath the
frame rails is the single strongest cue that this is an object rather than a
drawing, and it is the one thing a transparent-background capture can never have.

**Background.** A neutral gradient or seamless ground for hero use. Ship an
`-alpha` cut-out variant alongside for web compositing — that variant is exempt from
the background and contact-shadow gates and from nothing else.

**Camera.** One focal length and one horizon height across all ten modules, so a
grid reads as one product line. Three views per module:

| View | Purpose | Minimum |
|---|---|---|
| `hero` | 3/4 isometric, the primary marketing image | 2400 × 1800 |
| `front` | straight-on, for spec sheets and the comparison grid | 1600 × 1200 |
| `detail` | crop on the module's defining feature | 1600 × 1200 |

Subject fills 25–75 % of the frame and sits within 8 % of frame centre. A module
photographed as a speck in the corner fails regardless of how well it is lit.

## The gate

`visual_quality.py` measures all of the above deterministically — no model, no
tokens. Thresholds live in `visual-quality-thresholds.json` so they are data, not
code. The current renders fail it, which is the point.

| Metric | Threshold | Baseline |
|---|---|---|
| `tonal_p99` | ≥ 215 | 151 |
| `specular_fraction` | ≥ 0.0008 | 0.0000 |
| `metal_modulation` | ≥ 22.0 | 12.7 |
| `panel_modulation` | ≥ 14.0 | iso 18.7–30.1 ✓ · front 8.7–15.0 ✗ |
| `edge_density` | ≥ 0.055 | 0.065–0.112 ✓ |
| `subject_coverage` | 0.25 – 0.75 | iso 0.52–0.55 ✓ · front 0.820 ✗ |
| `subject_centering` | ≤ 0.08 | ✓ |
| `background_class` | not `transparent` (hero/front/detail) | transparent ✗ |
| `contact_shadow` | present | absent ✗ |
| resolution | per view, above | 1600 × 1200 |

Measured 2026-08-26: **0 of 20 legacy renders pass.**

`edge_density` is the only floor every current render clears. It is in the gate to
stop a lighting change from *destroying* detail that currently works — the common
failure mode when someone chases a highlight and blows out the fine geometry.

Two findings the baseline surfaced that are camera work, not lighting:

- **Every front view is framed at 0.820 coverage** — cropped so tight the module
  touches the frame edge. Reframe to the 0.25–0.75 band.
- **Front-view `metal_modulation` is roughly half the iso value** (7.1–15.0 against
  12.0–20.7). A straight-on camera puts every extrusion face at the same angle to
  the single light, so they all shade identically. Even with better materials, the
  front view needs its own key-light angle rather than inheriting the iso setup.

## Visual QA process

1. Deterministic gate — `visual_quality.py`. Primary judge, runs on every image.
2. Local VLM checklist — a fixed yes/no list per module, one image per request.
   Second opinion, never the sole gate.
3. One Claude confirmation pass over the finished contact sheet.

A render that passes the numbers and loses a required visible cue still fails. The
completion bar was never optional.

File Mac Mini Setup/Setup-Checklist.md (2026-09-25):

# Mac Mini — Always-On Claude Setup Checklist

Rebuilt 2026-08-03. Replaces the missing `mac-mini-claude-setup-checklist.md` referenced by the October reminder task.

**Purpose:** a Mac mini that stays awake 24/7 and runs Claude against the `Claude` folder without anyone sitting at it.

**Hardware is NOT bought** (corrected 2026-09-04). Conor is waiting on independent benchmarks after the machine
releases, then ordering. Intended config: M5 Pro, 18-core CPU / 20-core GPU, 64GB, 512GB, ~$2,899 retail /
~$2,679 education. Section 1 is prep you can do regardless; §2 onward starts the day it actually arrives.

⚠️ **Do the pre-move punch list first:** `Migration-Audit-2026-09-02.md`. Several items in it are laptop-side and
cannot be done once the folder has moved.

---

## 1. Before it arrives — accessories and prep

**Intended config (not ordered) · M5 Pro · 18-core CPU / 20-core GPU · 64GB · 512GB · ~$2,899 retail / ~$2,679 edu.**
Order pending post-release benchmarks.
The 64GB tier was the one irreversible choice (unified memory is not upgradeable); the 18-core was taken for
prefill latency on big tool schemas. Rationale in `Hermes-Local-Agent.md` Part 1 and `Memory.md`.

Order these so day one isn't blocked:

- [ ] **HDMI dummy plug / display emulator (~$10).** Load-bearing, not optional: `../Fusion CAD Agent/Hardware-Requirements.md`
      records that a fully headless mini may not drive the window server, and *the render sweep cannot run unattended at all*
      if it doesn't. You will have a real monitor attached on day one — the test is unplugging it (§9).
- [ ] **External drive for Time Machine.** Mandatory, not optional, under the single-authoritative-copy decision (§7).
- [ ] **Thunderbolt SSD for the model library.** 512GB internal fills at ~20GB/model; `import-external-model.sh` already
      implements the supported `lms import --symbolic-link` path. Cheaper than Apple's $270/TB internal.
- [ ] **Ethernet cable** — more reliable than Wi-Fi for an always-on box. Reserve its IP on the router (§2).
- [ ] Monitor + keyboard for first boot, or another Mac with Screen Sharing.

- [ ] **Confirm Drexel enrolment is active** if you have not taken delivery yet — education pricing runs through UNiDAYS
      and saved $220 on this build. Moot once the order ships.

*Superseded, kept for history: the July 2026 buying guidance (base M4 16GB, refurb M1/M2 as the value option, "do not
expect sub-$500") and the October purchase target. The M5 Pro launch on 2026-08-25 obsoleted all of it — no M4 mini
reaches 64GB. See `CLAUDE.md` → "Hardware plan — SUPERSEDED".*

---

## 2. First boot

- [ ] Run through macOS setup, sign in with your Apple ID
- [ ] Name the machine something identifiable (e.g. `claude-mini`) — System Settings → General → About → Name
- [ ] Install all pending macOS updates before configuring anything else
- [ ] ⚠️ **Leave the disk as the default APFS (case-insensitive).** Do not choose case-sensitive at install
- [ ] Connect via **ethernet** if possible
- [ ] Set a static IP or DHCP reservation on your router so you can always find it

---

## 3. Keep it awake — the core of "always on"

System Settings → **Energy** (or Battery → Options):

- [ ] **Prevent automatic sleeping when the display is off** → ON
- [ ] **Wake for network access** → ON
- [ ] **Start up automatically after a power failure** → ON ← critical for unattended recovery
- [ ] Display can sleep; the *machine* must not

Verify from Terminal:

```sh
pmset -g            # check sleep values
sudo pmset -a sleep 0 disksleep 0   # belt and braces
```

- [ ] Confirm `sleep` shows `0`

---

## 4. Survive a reboot unattended

A power blip at 3am shouldn't take the machine offline until you notice.

- [ ] **Turn off FileVault**, *or* accept that a reboot requires you to unlock the disk before login. FileVault + auto-login are mutually exclusive
  - Trade-off: FileVault off means the disk is readable if the machine is physically stolen. For a home machine holding this folder — which includes portfolio and severance detail — decide deliberately
- [ ] Enable **automatic login** — System Settings → Users & Groups → Automatically log in as
- [ ] Set apps you need to launch on login — System Settings → General → Login Items
- [ ] Test: pull the power, plug it back in, confirm it returns to a logged-in desktop with no keyboard input

---

## 5. Remote access — including from the iPad

Four jobs, four tools. Trying to do all of it with one app is where this goes wrong.

| Job | Tool | Why this one |
|---|---|---|
| **Drive Claude** — the daily case | **Claude app on the iPad**, paired to the mini (same QR flow as §6) | Universal app; no iPad-specific setup. You type, the work runs on the mini. Pro/Max required |
| **Full screen control** — Fusion, the LM Studio GUI, System Settings | **Jump Desktop** (iPadOS, one-time ~$25 — check current price) | **Apple ships no Screen Sharing client for iPadOS.** A third-party VNC/RDP app is mandatory, not optional. Jump's Fluid protocol holds up over the internet where raw VNC does not, and it maps the Magic Keyboard trackpad properly |
| **Shell** | **Blink Shell** + `mosh` (`brew install mosh` on the mini) | mosh survives the iPad sleeping and switching between Wi-Fi and cellular; plain SSH drops every time |
| **Reach it outside the house** | **Tailscale** | Free personal tier, apps on macOS and iPadOS, WireGuard, no port forwarding, no static WAN address |

**The rule that outranks the rest: never port-forward 5900 or 22.** This box runs
FileVault **off** with **auto-login** (§4), so anything that reaches it arrives at an
already-unlocked desktop holding portfolio and employment records. Apple's built-in VNC
also caps its password at 8 characters. Tailscale is the security boundary — put every
remote path inside it.

Also worth knowing:

- The **HDMI dummy plug** in §1 is what makes headless screen sharing usable at a real
  resolution rather than whatever the window server invents with no display attached.
- **Universal Control is not a path here.** It extends a Mac's keyboard and trackpad
  *to* a nearby iPad on the same Apple ID — the opposite direction, and local only.

- [ ] Enable **Screen Sharing** — System Settings → General → Sharing → Screen Sharing
- [ ] Enable **Remote Login (SSH)** if you want shell access
- [ ] Install **Tailscale** on the mini, the iPad, and the laptop; confirm the mini's
      `100.x` address answers from the iPad **on cellular, Wi-Fi off** — that is the real test
- [ ] Install **Jump Desktop** on the iPad, connect over Tailscale, confirm you can
      actually drive Fusion with it (small hit targets are the thing that fails)
- [ ] `brew install mosh`, then confirm Blink reconnects after the iPad has slept
- [ ] Confirm you can reach it from your laptop before removing the monitor

---

## 6. Claude setup

- [ ] Install the Claude desktop app
- [ ] Sign in — **Claude Dispatch requires a Pro or Max subscription**
- [ ] Pair your phone to the Mac via QR code in Dispatch
- [ ] Confirm you can trigger work from the phone and see it run on the mini
- [ ] Grant the app access to the `Claude` folder
- [ ] Verify it reads the root `CLAUDE.md` — ask it to name your projects; it should list all **15** without being told

---

## 7. Move the Claude folder over

**Decided:** the mini is the **single authoritative copy**. This is a *move*, not a copy — no two-way sync with the laptop.

### How to move it — do NOT drag the folder in Finder

**2.1GB of the folder's 2.6GB is rebuildable junk that must not travel**, and a
`git clone` is not a substitute either, because four directories are gitignored on
purpose and exist only in the working copy. Use the exclusion list:

```sh
# from the laptop, once the mini has SSH/Screen Sharing (step 5)
rsync -avh --progress \
  --exclude='.venv*' --exclude='node_modules' --exclude='__pycache__' \
  --exclude='dist/' --exclude='.wrangler/' --exclude='.vinext/' \
  --exclude='_to_delete/' \
  ~/Claude/ <mini>:~/Claude/
```

| Excluded | Size | Why |
|---|---|---|
| `Fusion CAD Agent/.venv-cq` | 1.29GB | uv Python 3.12 symlinked into `~/.local/share/uv/` — rebuild it below |
| `Bear Necessities/website/node_modules` | 709MB | `npm ci` rebuilds it |
| `website/dist`, `.wrangler`, `.vinext` | ~8MB | build output |
| `_to_delete/` | 145MB | dead 3.9 venvs staged for removal |

**Gitignored but essential — these are why `git clone` is not enough:**
`Bear Necessities/website/` (its own repo, no remote), `product/reference/competitors/`
(96 photos), `product/cad/native-modules/` (delivery copy), `Fusion CAD Agent/exports/bncad/`
(run history and benchmark evidence).

Then rebuild the two environments on the mini:

```sh
uv venv --python 3.12 "$HOME/Claude/Fusion CAD Agent/.venv-cq"
uv pip install --python "$HOME/Claude/Fusion CAD Agent/.venv-cq/bin/python" cadquery
( cd "$HOME/Claude/Bear Necessities/website" && npm ci )     # needs Node >= 22.13
```

- [ ] Folder rsynced with the exclusions above
- [ ] `.venv-cq` rebuilt with `uv` (§7d has the same command and the reasoning)
- [ ] `npm ci` run in `website/`
- [ ] `git -C ~/Claude status` on the mini matches the laptop (clean) — a better
      integrity check than counting files
- [ ] ⚠️ **Set up Time Machine to an external drive before retiring the laptop copy.** One authoritative copy is one point of failure until backups exist
- [ ] Confirm everything works on the mini for a week
- [ ] Then archive or delete the laptop copy so it can't drift and later be mistaken for current
- [ ] Reach the folder from the laptop via Dispatch or Screen Sharing — do not re-create a local copy
- [ ] Confirm all **17 `CLAUDE.md`**, **17 `Memory.md`** and **4 `AGENTS.md`** files arrived intact
      (17 = root + 15 top-level projects + `Home Projects/Home Network`; `AGENTS.md` = root, Bear Necessities,
      Career, Mac Mini Setup). Count them: `for n in CLAUDE.md Memory.md AGENTS.md; do printf '%s: ' "$n";
      find ~/Claude -name "$n" -not -path '*/node_modules/*' -not -path '*/.venv*' -not -path '*/.git/*' | wc -l; done`
- [ ] Confirm the git repo came with it: `git log` should show history
- [ ] **Bring the model library across rather than re-downloading it.** ~28GB was on
      the laptop as of the last `storage-check.sh`, and the 64GB roster adds
      `qwen3-coder-30b` (~16GB of weights). Copy `~/.lmstudio/models` to the
      Thunderbolt SSD and re-import with the supported symlink path
      (`tools/local-ai/import-external-model.sh`, which wraps `lms import
      --symbolic-link`) instead of pulling everything again over the wire
- [ ] ⚠️ **Re-register all scheduled tasks.** The definitions in `Scheduled/` travel with the folder, but the *schedules themselves* live in app config and do **not**. Recreate each one:
  - [ ] `chestnut-hill-monthly-updates` (monthly)
  - [ ] `septa-funding-watch` (weekly)
  - [ ] `bellwether-district-watch` (monthly)
  - [ ] `weekly-lexus-rx-hybrid-watch` (weekly)
  - [ ] `mac-mini-claude-project-reminder` (one-time — retire this once the mini is running)
- [ ] Decide which machine is authoritative, so the laptop and mini don't diverge

---

## 7b. Local AI stack (LM Studio/llmster) — SCRIPTED

The toolkit supports the official headless `llmster` daemon and the tested desktop-service fallback. Preview is safe and makes no changes.

```bash
cd "<Claude folder>/Mac Mini Setup/tools/local-ai"
./bootstrap-mac-mini.sh            # preview hardware profile and actions

# Preferred headless runtime (official LM Studio installer):
curl -fsSL https://lmstudio.ai/install.sh | bash

./bootstrap-mac-mini.sh --apply --download-models
./prepare-mlx-runtime.sh          # verify latest stable MLX is selected
python3 local-ai-manager.py doctor
python3 local-ai-manager.py benchmark
./verify-local-ai.sh --expect-autostart
./acceptance-test.sh --post-reboot  # run within 30 minutes after a real reboot
```

Full reasoning in `tools/local-ai/README.md`. Three things to know:

- **Autostart depends on auto-login** (step 4). Both headless and desktop recovery are per-user LaunchAgents.
- **Use the RAM profile, then benchmark.** `local-ai-manager.py plan` selects a conservative roster; test once with Fusion closed and again with Fusion open.
- **MLX is mandatory for primary chat/coding models.** Downloads force `--mlx`; doctor and acceptance inspect LM Studio metadata and fail on an accidental GGUF variant.
- **Do not use `--lan` casually.** On LM Studio 0.4+, enable Require Authentication, create a scoped token, and use `LM_API_TOKEN`. Never forward port 1234 through the router.
- Read `tools/local-ai/OPERATING-GUIDE.md` before adding optional models or raising context length.

## 7b-bis. Obsidian vault — DOES NOT TRAVEL, AND IS NO LONGER JUST A MIRROR

The vault lives in iCloud
(`~/Library/Mobile Documents/com~apple~CloudDocs/Obsidian Vault/Obsidian Vault/`),
outside the folder and its git repo. Same portability gap as the scheduled tasks
and the plugins below.

> ⚠️ **Changed 2026-09-02 — this section's old assumption is dead.** The vault used
> to be *purely derived*: losing it cost nothing, because `obsidian-port.py`
> regenerated it. It now also holds **`Context/`, `Inbox/`, `Outbox/`, `Templates/`** —
> vault-native folders created by the shared-workspace change, containing
> `Profile.md`, `Goals.md`, `Preferences.md`, `Current Focus.md` and
> `Working Agreement.md`. **That content exists nowhere else.** It is not in
> `~/Claude`, not in this git repo, and not regenerable by any script.
>
> The port script cannot harm it — verified 2026-09-02, it is **write-only**: no
> `unlink`, no `rmtree`, no pruning of any kind. (Corollary: it never removes
> orphans either, so a renamed source note leaves a stale copy in the vault forever.)
>
> The risk is not the script, it is that **iCloud is the only copy** — on a machine
> where "Optimize Mac Storage" is on, eviction is silent, and FileVault is off.
> Until the mini's Time Machine is running, `Context/` is a single point of failure
> for Conor's profile, goals and working agreement.

- [ ] **Back up `Context/` somewhere that is not iCloud** before trusting the mini
      with it — a copy into `~/Claude` (where git and Time Machine both cover it), or
      onto the Time Machine drive directly. Decide which is authoritative and say so,
      or this becomes the two-copies-drift problem the 2026-08-03 audit warned about.

- [ ] Install Obsidian and sign in; iCloud will have synced the vault contents already
- [ ] Open the vault and confirm `Home.md` and `Claude Vault.base` render
- [ ] Re-run the port from the folder: `python3 obsidian-port.py`
  - Idempotent and folder-relative — safe to re-run any time to refresh
  - Override the destination with `OBSIDIAN_VAULT=/path/to/vault` if iCloud is not used on the mini
- [ ] Remember the direction — now with one exception: **`~/Claude` is authoritative
  for projects, and the vault is output.** Edits to *ported* notes inside Obsidian are
  overwritten on the next run. **But `Context/`, `Inbox/`, `Outbox/` and `Templates/`
  are vault-native and authoritative there** — nothing ports them, and nothing
  regenerates them

- [ ] **Re-add the Obsidian MCP server** — user-scope MCP config lives in
  `~/.claude.json` and does **not** travel with the folder:
  ```sh
  claude mcp add obsidian --scope user -- npx -y obsidian-mcp@2 serve \
    --vault "notes=$HOME/Library/Mobile Documents/com~apple~CloudDocs/Obsidian Vault/Obsidian Vault" \
    --recovery-days 7 --recovery-max-bytes 268435456
  ```
  - Needs Node >= 22 (step 7c already installs Node). No Obsidian plugin, no API
    key, and Obsidian does not need to be running — that is why this server was
    chosen over the REST-API ones, which would go dark whenever the app is closed
  - [ ] Verify: `claude mcp list` shows `obsidian - ✔ Connected`, and
    `npx -y obsidian-mcp@2 doctor --vault "notes=<path>"` returns `"ok": true`
  - [ ] ⚠️ **Learn the unbrick before you need it.** Upstream issue #71 is unfixed
    in 2.0.1: an ownerless write-lock permanently blocks startup and never
    self-heals, and Claude Code reports only a connect timeout with empty stderr.
    Fix: `rm -rf "<vault>/.obsidian-mcp/locks/write"`. Use `doctor` to see the
    real error — the MCP log will not tell you
  - [ ] Remember the port script now guards vault-side edits (`port_hash`), so a
    re-port **skips and names** edited notes instead of reverting them

## 7c. Claude Code plugins, skills & MCP servers — DO NOT TRAVEL WITH THE FOLDER

Same portability gap as the scheduled tasks in step 7. The agent environment lives in
`~/.claude/settings.json` (`enabledPlugins` + `extraKnownMarketplaces`),
`~/.claude/plugins/`, `~/.claude/skills/`, and `~/.claude.json` (MCP servers) — none of
it inside the `Claude` folder. Re-install on the mini or it is all silently absent.

- [ ] **Snapshot the live laptop state right before migrating** — the lists below are a
      dated point-in-time and *will* drift. Capture the truth to bring with you:
  ```sh
  claude plugin list > /tmp/claude-env.txt
  cat ~/.claude/plugins/known_marketplaces.json >> /tmp/claude-env.txt
  python3 -c "import json;print('\n'.join(json.load(open('$HOME/.claude/settings.json'))['enabledPlugins']))" >> /tmp/claude-env.txt
  claude mcp list >> /tmp/claude-env.txt
  ls ~/.claude/skills >> /tmp/claude-env.txt
  ```

- [ ] **Install Node first — the local-AI toolkit does not.** `tools/local-ai/` is deliberately stdlib-only Python, so nothing in step 7b puts `node` on the box. `ponytail`, `claude-mem`, `playwright`, and `chrome-devtools-mcp` all shell out to `node`.
  ```sh
  brew install node   # laptop landed 26.7.0 / npm 11.19.0 on 2026-08-26
  ```
- [ ] Confirm `node` resolves in a **non-interactive** shell, not just your terminal — hooks run non-interactively: `zsh -c 'command -v node'`

- [ ] **Add the 3 marketplaces** (`claude-plugins-official` is built in; add the other two):
  ```sh
  claude plugin marketplace add DietrichGebert/ponytail
  claude plugin marketplace add thedotmack/claude-mem
  ```
- [ ] **Install all 20 plugins** (user scope, headless — `/plugin` slash commands need an interactive panel). As of **2026-09-01**:
  ```sh
  for p in chrome-devtools-mcp claude-code-setup claude-md-management code-review \
           code-simplifier context7 feature-dev figma frontend-design github \
           mattpocock-skills playwright ralph-loop security-guidance skill-creator \
           superpowers typescript-lsp vercel; do
    claude plugin install "$p@claude-plugins-official" --scope user --yes
  done
  claude plugin install ponytail@ponytail --scope user --yes
  claude plugin install claude-mem@thedotmack --scope user --yes
  ```
- [ ] Verify: `claude plugin list` shows all 20 `✔ enabled`, and `~/.claude/settings.json` `enabledPlugins` has 20 keys.
- [ ] **ponytail default level:** installs at **`full`**, user scope — applies to *every* project here, not just coding ones. `/ponytail lite` or `/ponytail off` per session for the writing-heavy projects.

- [ ] **Copy the 7 loose skills** — hand-installed, in no repo:
  ```sh
  rsync -a ~/.claude/skills/ "<new mac>":~/.claude/skills/
  # banana defuddle json-canvas obsidian-bases obsidian-cli obsidian-markdown world-building
  ```
- [ ] **Authenticate the MCP servers that need it.** Run `claude mcp list`. As of 2026-09-01:
  - **`github`** — the plugin's `.mcp.json` sends `Authorization: Bearer
    ${GITHUB_PERSONAL_ACCESS_TOKEN}`. That env var is unset, so the header ships
    unexpanded and the server rejects it ("Authorization header is badly formatted").
    **Fix — set the token** (a fine-grained PAT scoped to just the startups' repos is
    better hygiene than reusing the broad `gh` token; `workflow` scope needed only for
    Actions):
    ```jsonc
    // ~/.claude/settings.json
    "env": { "GITHUB_PERSONAL_ACCESS_TOKEN": "github_pat_..." }
    ```
    A config token (not interactive OAuth) is required here because **scheduled/autonomous
    agents can't do a device-code flow.** `claude mcp list` should then show `github ✔`.
    Needed for real startup code work — repos, PRs, issues, CI.
  - `vercel`, `figma` — HTTP servers, `/mcp` → sign in interactively. Only if a startup uses them.
- [ ] Re-check for plugins/skills/MCP added after 2026-09-01 — re-run the snapshot above.

---

## 7d. CAD stack (bncad) — the part that builds actual geometry

*Added 2026-08-28. `Fusion CAD Agent/bncad/` turns a JSON part spec into a
validated, supplier-ready STEP using a local model. It was verified on a
relocated checkout with a from-scratch venv and under a cron-like environment,
so this section is the sequence that was actually tested.*

- [ ] **Install the prerequisites first.** None of the commands below exist on a
      fresh Mac. This is the step that stops people:
  ```sh
  xcode-select --install                                   # git, make, clang
  /bin/bash -c "$(curl -fsSL https://raw.githubusercontent.com/Homebrew/install/HEAD/install.sh)"
  brew install uv                                          # or: curl -LsSf https://astral.sh/uv/install.sh | sh
  ```
- [ ] **Build the CadQuery environment with `uv`.** A fresh Mac has no system
      `python3.12`, so the plain `venv` command fails with "command not found".
      `uv` fetches the interpreter as well:
  ```sh
  uv venv --python 3.12 "$HOME/Claude/Fusion CAD Agent/.venv-cq"
  uv pip install --python "$HOME/Claude/Fusion CAD Agent/.venv-cq/bin/python" cadquery
  ```
- [ ] **Delete any `.venv-cq` that travelled with the folder.** It is gitignored,
      but a filesystem *move* brings it anyway, and it points at the laptop's
      interpreter. Rebuild it here rather than trusting it.
      *(§7's `rsync` already excludes `.venv*` — this checkbox is the safety net for
      a Finder drag or Migration Assistant. Verified 2026-09-02: `.venv-cq/bin/python`
      is a symlink to `/Users/cmken/.local/share/uv/...`, so a copied venv is broken
      on arrival, not merely stale. The two 3.9 venvs that had the same defect were
      retired to `_to_delete/` the same day.)*
- [ ] **Check readiness:** `cd "$HOME/Claude/Bear Necessities/cad" && python3 preflight.py --for parts`
      — it names the exact fix for anything missing. Exit 0 means ready.
- [ ] **Run the self-tests:** `"$HOME/Claude/Fusion CAD Agent/bncad.sh" selftest`
      — no model, no Fusion, no network needed.
- [ ] **Build one real part** to prove the whole chain:
      `"$HOME/Claude/Fusion CAD Agent/bncad.sh" build C-01-anchor-plate`

### Fusion, if this mini is also to finish parts

Fusion is **optional** — every build above is headless through CadQuery. Fusion
adds the cross-kernel check and the parametric feature tree.

- [ ] Install Autodesk Fusion and **sign in once interactively**. It is not an
      offline application and it cannot be installed headless.
- [ ] Preferences → General → API → tick **Fusion MCP Server**.
- [ ] Verify: `"$HOME/Claude/Fusion CAD Agent/bncad.sh" doctor` shows a Fusion MCP
      line. **Do not pin the port** — it moves (27182 documented, 27180 observed
      twice); discovery handles it.
- [ ] Know the standing limits: Fusion demands re-authentication periodically, so
      a months-long unattended run will eventually stall on a modal dialog. Only
      the `native` and `visuals` stages depend on it; `parts` and `validate` do
      not.

### Scheduling it

Nothing schedules bncad yet — decide whether you want it to. If so, a launchd
job is the macOS-correct way (cron works but does not survive as cleanly):

```sh
# ~/Library/LaunchAgents/com.conor.bncad.plist -> ProgramArguments:
#   /bin/sh -lc '"$HOME/Claude/Fusion CAD Agent/bncad.sh" bench --model qwen/qwen2.5-coder-14b >> /tmp/bncad.log 2>&1'
launchctl load ~/Library/LaunchAgents/com.conor.bncad.plist
```

- [ ] **Always pass `--model` (or set `BN_MODEL`).** With neither, `bench` sweeps
      every model on every provider, which is an all-day job.
- [ ] Branch on the exit code: `0` success · `1` a part did not meet its spec ·
      `2` configuration · `3` busy, another build is running. `3` is not a
      failure.

### Choosing the model here — do not assume the laptop's answer

On the 16GB laptop the 14B looked 33× slower than the 7B. That was **memory
starvation, not the model**: with RAM free it runs at ~30s and builds parts the
7B cannot. On a 32GB+ mini the 14B is expected to be the right default.

- [ ] Settle it with numbers: `"$HOME/Claude/Fusion CAD Agent/bncad.sh" bench --model qwen/qwen2.5-coder-14b --repeat 2`
      and read the per-part **pass rate**. A single run cannot tell a robust
      result from a lucky one.

---

## 7e. Hermes Agent local host — SEE `Hermes-Local-Agent.md`

*Added 2026-09-01. The Hermes Agent desktop app pointed at the local LM Studio
server, so autonomous Hermes tasks run on a local model instead of paid API
usage. Verified on the 16 GB laptop; the runbook is written for the 64 GB mini.*

`Hermes-Local-Agent.md` is the authoritative doc — hardware rationale, the
ordered runbook, and the failure table. Summary of the steps:

- [ ] LM Studio ≥ 0.3.6, server on `:1234` (§7b already does this). Install
      Hermes **only** from `hermes-agent.nousresearch.com` (lookalike domains
      exist). Bionic is a client, not a server — ignore it.
- [ ] Model for the 64 GB tier: `qwen/qwen3-coder-30b` MLX 4-bit (already the
      `coding` role in `model-profiles.json`). Only use tool-use-badged models.
- [ ] Load at **64000** context, `--parallel 1`. Hermes refuses below 64k and a
      context change needs a model **reload**. Set the per-model default context
      to 64000 in LM Studio so it survives restarts.
- [ ] If MLX crashes under a real prompt, fall back to the **GGUF Q4_K_M** build
      of the same model — the sanctioned benchmark-backed exception. Record it.
- [ ] Wire it + prove it in one command: **`tools/local-ai/setup-hermes.sh --load`**.
      Resolves `qwen/qwen3-coder-30b` from the 64 GB profile, backs up the config,
      writes `provider`/`base_url`/`model.default`/`context_length: 64000` via the
      CLI (the desktop provider UI has mapping bugs — issues #38975 / #47961), then
      runs `verify-hermes.sh` — which asserts a model is loaded at ≥ 64k, that it
      emits a well-formed `tool_call`, and that `hermes -z` executes a real
      terminal tool and uses the result. A `/v1/models` 200 is not proof.
- [ ] Restart the Hermes desktop app fully so its backend picks up the config.

---

## 7f. Codex CLI + the website's publishing path — DOES NOT TRAVEL

*Added 2026-09-02 by the migration audit. This folder has a root `AGENTS.md` and the
Bear Necessities site publishes through ChatGPT/OpenAI Sites, so Codex is a real
dependency with no setup step until now.*

- [ ] **Install the Codex CLI and sign in.** Credentials live in `~/.codex`, outside
      this folder — same portability gap as the scheduled tasks and `~/.claude*`.
- [ ] **Prove the site can still be published from the mini.** The live site is
      `https://bear-necessities-overland.cmkennedy218.chatgpt.site`; its project id is
      committed at `Bear Necessities/website/.openai/hosting.json`. Run a build and a
      no-op redeploy — finding out the credential is missing during a real content
      change is the bad version of this.
  ```sh
  cd "$HOME/Claude/Bear Necessities/website"
  npm ci && npm run build      # needs Node >= 22.13 (package.json engines)
  ```
- [ ] ⚠️ **The website is its own git repo with NO REMOTE.** Until it is pushed
      somewhere, the laptop is the only copy in the world. Push it to a private repo
      before retiring the laptop copy (the `github` MCP in §7c is being fixed anyway),
      or at minimum keep the bundle at `Bear Necessities/website-repo-2026-09-02.bundle`
      on the Time Machine drive. Restore from a bundle with:
      `git clone website-repo-2026-09-02.bundle website`
- [ ] Note that only **3 of 15** projects have an `AGENTS.md` (root, Bear Necessities,
      Career, Mac Mini Setup). Codex reads `CLAUDE.md` for the rest — the root
      `AGENTS.md` now says so explicitly rather than claiming a file that isn't there.

---

## 7g. Ollama — OPTIONAL, decide before installing

*The toolkit carries `tools/ollama/` (a LaunchAgent + `ollama-doctor.sh`) because bncad
supports Ollama as a second provider and there is benchmark evidence under
`Fusion CAD Agent/exports/bncad/bench-ollama/`. It had no install step and the plist
hardcoded `/Users/cmken` paths; both fixed 2026-09-02.*

**LM Studio is the primary runtime (§7b) and Ollama is not required.** The one
measured data point is against it: `qwen3:8b` through Ollama passed 1/5 bncad parts at
~1200s, versus 9/12 at 28s for the 7B coder on LM Studio — model class, not the runner,
but nothing here needs Ollama today.

If you do want it:

```sh
brew install ollama
"$HOME/Claude/Mac Mini Setup/tools/ollama/install-ollama-autostart.sh" --dry-run   # preview
"$HOME/Claude/Mac Mini Setup/tools/ollama/install-ollama-autostart.sh"
"$HOME/Claude/Mac Mini Setup/tools/ollama/ollama-doctor.sh"
```

- [ ] Decided whether Ollama is on this machine at all
- [ ] If yes: installed, autostart verified, `ollama-doctor.sh` green, bound to loopback
- [ ] If no: nothing to do — LM Studio covers every documented workflow

---

## 7h. Home cloud storage — SEE `Home-Cloud-Storage.md`

Make Conor's project files reachable from the laptop, iPad and iPhone. Full
decision doc, options analysis and the step-by-step runbook are in
`Home-Cloud-Storage.md`; the short version:

**Order matters — backup layer first, cloud second.** Sync propagates deletions;
it is not a backup.

- [ ] **Time Machine running and verified** (test-restore one file) — the §1
      drive connected, first full backup complete. Do not enable any file
      sharing until this is done.
- [ ] Off-site copy decided: `~/Claude` → the GitHub repo (already exists);
      non-repo files → **iCloud Drive** *or* **Backblaze Personal** (~$99/yr).
- [ ] 2 TB external SSD formatted (APFS), hosting `/Volumes/Vault/Projects`,
      `/Volumes/Vault/Models` (the LM Studio library — same drive, see §7b),
      etc. Project files moved over via the §7 rsync path, not Finder drag.
- [ ] **SMB File Sharing** on (System Settings → Sharing → File Sharing → SMB),
      strong account password. Mounts in the iOS/iPadOS **Files app** via
      `smb://<mini-tailscale-ip>`.
- [ ] Verified from the **iPhone on cellular, wifi off** — open a file, edit,
      save, confirm the change on the laptop.
- [ ] **Taildrive** tried (`tailscale drive share …`) — appears as "Tailscale"
      in Files with no address typed. Prefer it over SMB *only if* large-file
      transfers are fast and reliable (it's alpha).
- [ ] **Syncthing** installed (mini + laptop via `brew`, iOS via Möbius Sync) on
      **only** the 1–3 folders that must be offline on the iPad. File Versioning
      → Staggered on each. Not the whole Vault.
- [ ] Reboot the mini; confirm shares + Syncthing return and the iPad
      reconnects.
- [ ] **Restore a deleted test file from Time Machine** — prove the backup
      layer, not just the sync layer.
- [ ] Record in the Decisions log which access method won (SMB vs Taildrive) and
      which folders are on Syncthing.

**Do NOT:** port-forward anything; run Nextcloud unless he wants the hobby; RAID
a documents archive; buy a NAS.

---

## 8. Safety rails for unattended operation

- [ ] Confirm `git status` is clean before leaving it alone, so any autonomous change is visible as a diff
- [ ] Consider a daily auto-commit so overnight edits are recoverable:
  ```sh
  cd ~/Claude && git add -A && git commit -m "auto: $(date +%F)" || true
  ```
- [ ] Set up Time Machine to an external drive — git protects the files, Time Machine protects the machine
- [ ] Decide which tasks may act autonomously vs. which must ask first. Anything touching money, sending email, or posting publicly should ask
- [ ] Note: this folder contains portfolio holdings, severance terms, and your home address. Treat physical and network access to the mini accordingly

---

## 9. Verify before walking away

- [ ] ⚠️ **Disconnect the monitor and confirm Fusion still drives the window server.**
      This is the one untested load-bearing assumption in the whole project: per
      `../Fusion CAD Agent/Hardware-Requirements.md`, a fully headless mini may not
      drive the window server, and *the render and native-CAD stages cannot run
      unattended at all* if it doesn't. Fit the HDMI dummy plug (§1), pull the real
      monitor, then over Screen Sharing run
      `"$HOME/Claude/Fusion CAD Agent/bncad.sh" doctor` and a `./build.sh native`
      or `visuals` stage. If it fails, the headless CadQuery path (`parts`,
      `validate`) still works — only the Fusion-dependent stages are lost
- [ ] Close the lid / disconnect the monitor and confirm it stays reachable
- [ ] Trigger a task from your phone and confirm it completes
- [ ] Reboot it remotely and confirm it comes back logged in on its own
- [ ] Let a real scheduled task fire on its own schedule and confirm the output
- [ ] Check `pmset -g log | grep -i sleep` after a day to confirm nothing put it to sleep

---

## Decisions log

- *Resolved 2026-08-03 — **Authority:** the mini is the single authoritative copy; no two-way sync.*
- *Resolved 2026-08-07 — **FileVault: OFF.*** Uptime/auto-login after a power blip wins over disk encryption. Section 4's checkbox reflects this: turn FileVault off, enable automatic login.
- *Resolved 2026-08-07 — **Autonomy boundary:** the default stands as final.* Money, email, and public posting always ask first; everything else may proceed autonomously. No additional categories added.
- *Confirmed 2026-08-07 — **Scheduled-task re-registration is a real, not theoretical, step.*** Checked live registrations on 2026-08-07: none of the 5 tasks listed in step 7 were actually registered in app config, only defined in-folder. Re-registered `mac-mini-claude-project-reminder` for Oct 1, 2026. The other four still need the same fix (outside this project's scope — flagged, not actioned).

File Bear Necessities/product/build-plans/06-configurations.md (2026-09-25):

# 06 — Configurations: how modules combine in a vehicle

Six module combinations, each checked by the project's placement solver against
real (sourced) vehicle cargo envelopes. Generated 2026-08-26 from
`config_solver.py`; every row here is solver output, not an assertion.

> **What the solver checks:** envelope fit including the wheel-well pinch, module
> overlap, stack support, top-opening headroom, and whether anything blocks a
> front-opening module from the tailgate.
>
> **What it does NOT check:** payload (all module masses are unverified — it
> refuses to return a load figure), centre of gravity, whether the arrangement
> can actually be restrained (that's the undesigned C-02 question), and whether
> a person can reach the rear module of a deep stack.

---

## The arithmetic that decides everything

One module is **24 W × 20 D × 18 H in**.

| Arrangement | Dimension | Fits an SUV? |
|---|---|---|
| Two side by side, unrotated | 48 in wide | No — a 4Runner is 40–43 in between the wheel wells |
| Two side by side, **rotated 90°** | 40 in wide | Yes, barely, in a 5th-gen 4Runner |
| Two stacked | 36 in tall | No — a 4Runner is ~29.5–31 in floor to ceiling |
| One module | 18 in tall | Yes, ~11.5–13 in headroom left |

**Rotating a module 90° is what makes two-across possible in an SUV.** It costs
4 in of width and buys the second module.

## The headroom ceiling

An 18 in module in a ~31 in bay leaves ~13 in (5th-gen 4Runner) or ~11.5 in
(6th-gen). Anything that opens upward has to fit its lid/tray/worktop in that gap:

| Module | Needs above it | 4Runner 5th (~13 in) | 4Runner 6th (~11.5 in) |
|---|---|---|---|
| BN-M01 Cook | ~10 in | fits | fits |
| BN-M04 Sink | ~12 in | fits | **does not fit** |
| BN-M03 Fridge | ~14 in | **does not fit** | **does not fit** |
| BN-M09 Field Office | ~14 in | **does not fit** | **does not fit** |

BN-M03 and BN-M09 are **van / truck class** for this reason.

---

## What fits which vehicle

| Vehicle | Bay W × D × H (in) | Between wells | Max modules |
|---|---|---|---:|
| Toyota 4Runner 5th gen | 47 × 59 × 31 | 43 | **2** |
| Toyota 4Runner 6th gen | 45 × 59 × 29.5 | 40 | **2** |
| Ford Transit (low roof) | 54.8 × 100 × 56.9 | 54.8 | **5+** |
| Mercedes Sprinter | 53.1 × 100 × 68 | 53.1 | **5+** |
| Bronco, Wrangler, Tacoma, Outback | — | — | **unverified — the solver refuses to answer** |

Every sourced figure has a URL and date in the project's
`VEHICLE-ENVELOPES.json`, but **several fields inside those entries are still
marked unverified** — wheel-well heights are assumed, van floor lengths are
conservative placeholders. Treat this as design guidance, not as measurements to
cut anything against. Measure your own vehicle with the project's
`MEASUREMENT-WORKSHEET.md` before committing.

---

## The six named configurations

All solver-validated. The "fits" column is exactly the set the solver found a
valid arrangement for.

| Configuration | Modules | Fits |
|---|---|---|
| **Weekend Base** | Cook (M01) + Fresh Water (M05) | 4Runner 5th, 4Runner 6th, Transit, Sprinter |
| **Trail Kitchen** | Cook (M01) + Dry Pantry (M02) | 4Runner 5th, 4Runner 6th, Transit, Sprinter |
| **Recovery Day** | Dry Pantry (M02) + Recovery (M06) | 4Runner 5th, 4Runner 6th, Transit, Sprinter |
| **Wash Up** | Cook (M01) + Sink (M04) | 4Runner 5th, Transit, Sprinter |
| **Basecamp** | Cook (M01) + Pantry (M02) + Fridge (M03) + Water (M05) | Transit, Sprinter |
| **Expedition** | Cook (M01) + Pantry (M02) + Recovery (M06) + Hot Water (M08) + Furniture (M10) | Transit, Sprinter |

Renders of each are in `product/marketing/configurations/` in the project (not
bundled in this pack — they're marketing assets).

**Example placement — Weekend Base in a 5th-gen 4Runner** (origin at the tailgate
edge, both modules rotated 90° so each footprint is 20 × 24 in):

```
BN-M01 Cook  @ (0, 0, 0)     footprint 20 x 24, rotated
BN-M05 Water @ (20, 0, 0)    footprint 20 x 24, rotated
```

**Example placement — Basecamp in a Transit** (origin at the tailgate edge,
driver side, +y forward):

```
BN-M01 @ (0,0,0)   BN-M02 @ (24,0,0)   BN-M03 @ (0,20,0)   BN-M05 @ (24,0,18)
```

---

## The practical takeaway

The product story is **a chosen subset per trip, not a full stack**. An SUV
holds two modules; a van holds five or more. Design your build around 2–4
modules unless you're in a van. And re-confirm any of this against your own
vehicle's real measurements — the envelopes here are good enough to design with
and not good enough to cut a vehicle bracket against.

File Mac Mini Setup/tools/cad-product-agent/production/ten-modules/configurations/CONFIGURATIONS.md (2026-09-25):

# Deployed configurations — how the modules combine in a vehicle

Generated 2026-08-26 from `config_solver.py`. Every claim here is solver output,
not an assertion. Re-check with `python3 config_solver.py --validate-all`.

## The arithmetic that decides everything

One module is **24 W × 20 D × 18 H inches**. Therefore:

| Arrangement | Dimension | Fits an SUV? |
|---|---|---|
| Two side by side, unrotated | 48 in wide | No — a 4Runner is 40–43 in between the wheel wells |
| Two side by side, **rotated 90°** | 40 in wide | Yes, barely, in a 5th-gen 4Runner |
| Two stacked | 36 in tall | No — a 4Runner is 29.5–31 in floor to ceiling |
| One module | 18 in tall | Yes, leaving 11.5–13 in of headroom |

**Rotating the module 90° is what makes two-across possible in an SUV.** It costs
4 inches of width and buys the second module. That is the single most useful thing
the solver found.

## The headroom ceiling — the finding that changes the product

An 18-inch module in a 31-inch bay leaves **13 inches**. In a 6th-gen 4Runner
(29.5 in) it leaves **11.5 inches**. Every module that opens upward has to fit its
lid, tray or worktop inside that.

| Module | Needs above it | 4Runner 5th (13 in) | 4Runner 6th (11.5 in) |
|---|---|---|---|
| BN-M01 Cook | 10 in | fits | fits |
| BN-M04 Sink | 12 in | fits | **does not fit** |
| BN-M03 Fridge | 14 in | **does not fit** | **does not fit** |
| BN-M09 Field Office | 14 in | **does not fit** | **does not fit** |

**BN-M03, the fridge, does not fit any 4Runner measured.** Not "is tight" — the
solver rejects every placement, in both generations, on lid clearance alone. Same
for BN-M09. That is a product decision waiting to happen, and it has three possible
answers:

1. Reduce the module height below 18 in — breaks the family's defining dimension
   and the 8 × 18 in cut list. Expensive.
2. Change BN-M03 to a front-opening fridge — changes the primary component, and
   the whole point of a chest fridge is that cold air does not fall out.
3. Accept that BN-M03 and BN-M09 are van- and truck-class modules, and say so on
   the product page. Cheapest, and honest.

Nothing in this plan decides that. It is Conor's call, and it belongs next to the
C-02 decision.

## What actually fits

| Vehicle | Status | Bay (W × D × H) | Between wells | Max modules |
|---|---|---|---|---|
| Toyota 4Runner 5th gen | sourced | 47 × 59 × 31 | 43 | **2** |
| Toyota 4Runner 6th gen | sourced | 45 × 59 × 29.5 | 40 | **2** |
| Ford Transit low roof | sourced | 54.8 × 100 × 56.9 | 54.8 | **5+** |
| Mercedes Sprinter | sourced | 53.1 × 100 × 68 | 53.1 | **5+** |
| Bronco, Wrangler, Tacoma, Outback | **UNVERIFIED** | — | — | solver refuses to answer |

Every sourced figure carries a URL and a date in `VEHICLE-ENVELOPES.json`, and
several individual fields inside those entries are still marked UNVERIFIED — the
wheel-well heights are assumed, and the van floor lengths are deliberately
conservative placeholders. Treat the table as design guidance, not as measurements
to cut a bracket against. `C-02-vehicle-queue.json` makes that rule explicit and it
applies here unchanged.

## The named configurations

All six are solver-validated. The vehicle list is exactly the set the solver found
a valid arrangement for.

| Configuration | Modules | Fits |
|---|---|---|
| **Weekend Base** | Cook + Fresh Water | 4Runner 5th, 4Runner 6th, Transit, Sprinter |
| **Trail Kitchen** | Cook + Dry Pantry | 4Runner 5th, 4Runner 6th, Transit, Sprinter |
| **Recovery Day** | Pantry + Recovery | 4Runner 5th, 4Runner 6th, Transit, Sprinter |
| **Wash Up** | Cook + Sink | 4Runner 5th, Transit, Sprinter |
| **Basecamp** | Cook + Pantry + Fridge + Water | Transit, Sprinter |
| **Expedition** | Cook + Pantry + Recovery + Hot Water + Furniture | Transit, Sprinter |

Example placement, Basecamp in a Transit — origin at the tailgate edge, driver side,
`+y` forward:

```
BN-M01 @ (0,0,0)   BN-M02 @ (24,0,0)   BN-M03 @ (0,20,0)   BN-M05 @ (24,0,18)
```

## What the solver checks, and what it does not

Checks: envelope fit including the wheel-well pinch, module overlap, stack support,
top-opening headroom, and whether anything sits between a front-opening module and
the tailgate.

Does **not** check, and will say so rather than guess:

- **Payload.** Every module mass in `module-deployment.json` is `UNVERIFIED`, so
  `payload_note()` refuses to return a load figure. Populate the masses before
  quoting one.
- **Centre of gravity and load distribution.** Not modelled at all.
- **Restraint.** Whether the arrangement can actually be tied down is the C-02
  question, and it is still open.
- **Reach.** Whether a human can operate the rear module of a deep van stack.

## Reproducing

```bash
python3 config_solver.py --vehicle 4runner-5th --set M01,M03 --explain
```

`--explain` prints the rejection reasons with counts, which is the fastest way to
see *why* something does not fit rather than just that it does not.

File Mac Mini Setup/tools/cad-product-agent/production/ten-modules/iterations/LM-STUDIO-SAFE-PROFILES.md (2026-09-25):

# LM Studio safe execution profiles

## Why the laptop profile exists

On 2026-08-25 the 16 GB M1 Pro MacBook kernel-panicked twice while LM Studio's
14B MLX Node/Metal worker was generating consecutive review cycles. Both panic
logs reported `completeMemory() prepare count underflow` in `IOGPUMemory.cpp`
with `IOGPUFamily` in the backtrace and `node` as the panicked task. Compressor
and swap status were reported as healthy, so the framework treats this as a GPU
memory-lifecycle failure rather than an ordinary Python exception.

LM Studio's own estimates at a 6,144-token context were:

- Qwen2.5 Coder 14B MLX 4-bit: 10.86 GiB GPU/total memory.
- Qwen2.5 Coder 7B MLX 4-bit: 5.60 GiB GPU/total memory.

The measured review workload peaked at 2,850 prompt tokens, 1,596 completion
tokens, and 4,446 total tokens across the first twelve completed cycles. A
6,144-token context and 1,800-token output cap therefore retain practical
headroom without the 8,192-token default allocation.

## Profiles

`laptop-safe` (24 GB RAM or less): 7B MLX, 6,144 context, one prediction,
speculative decoding off, 1,800 output-token cap, 30-second cool-down, load
average ceiling 20, and pressure-aware free-memory floor 30 percent.

`mac-mini` (more than 24 GB): primary 14B MLX, 6,144 context, one prediction,
speculative decoding off, 2,000 output-token cap, five-second cool-down, load
ceiling 32, and free-memory floor 20 percent.

The 16 GB laptop does **not** run the full local-VLM release batch. Gemma was
estimated at 8.95 GiB and Qwen3.5 9B at 7.79 GiB, so both were rejected for the
laptop. A Qwen2.5-VL 3B MLX canary loaded at 2.88 GiB and completed one image,
but LM Studio's native endpoint silently created a second parallel-4 instance;
free memory fell from 74 to 32 percent. Its JSON was also contradictory: PASS
with populated blocking findings. Both instances were immediately unloaded.

Laptop visual evidence therefore uses direct inspection of every render,
bound to each current image SHA-256, plus deterministic geometry cues and
current comparable/OTS web evidence. The full local-VLM batch remains in the
Mac mini profile, using `google/gemma-4-e4b`, reasoning off, a 3,072-token
request context, one stage at a time, and resource guards. The replication
script unloads the coder before Fusion/vision and unloads all models at the end.

Run `./run_revision_profile.sh auto`. Validated files are resumable, and every
ledger record retains its actual model ID. A mixed 14B/7B run is accepted only
under the explicit `documented_low_memory_continuation` policy; model weights
are never described as retrained.

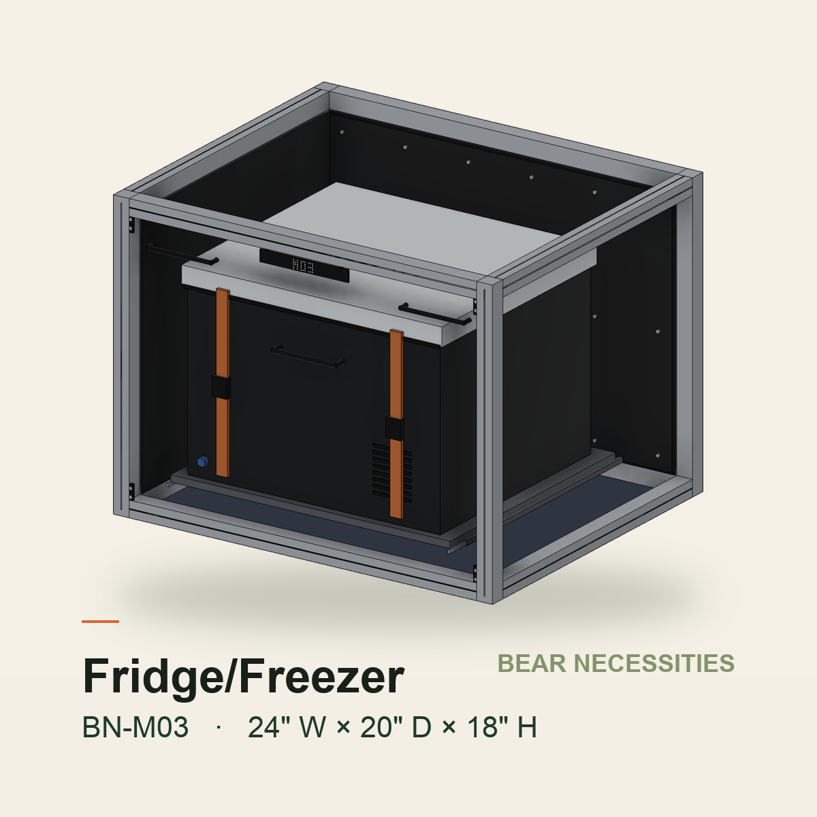
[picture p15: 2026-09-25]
Mac Mini Setup/tools/cad-product-agent/production/ten-modules/visual/renders/BN-M03-square.png

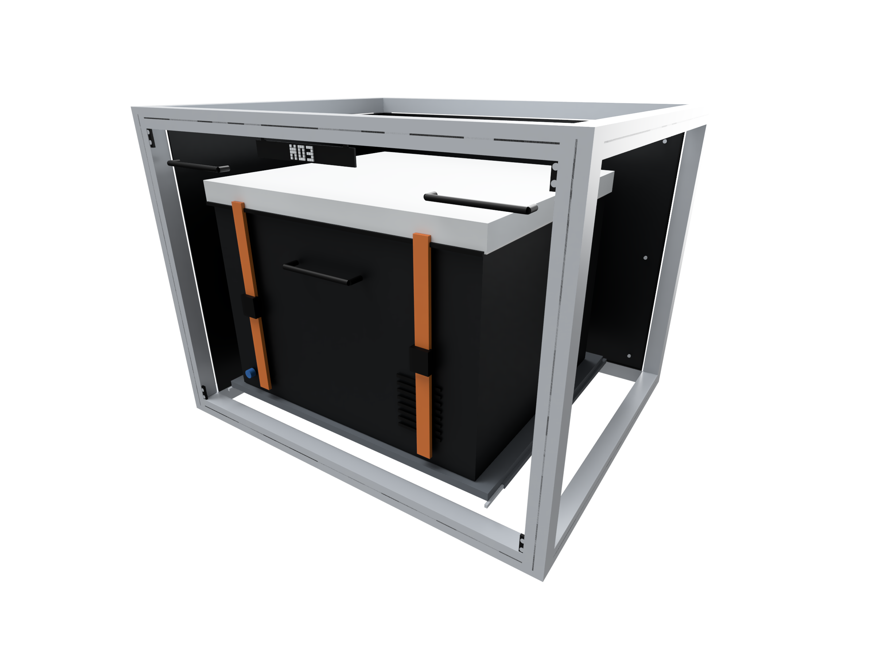
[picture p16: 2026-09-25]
Mac Mini Setup/tools/cad-product-agent/production/ten-modules/visual/renders/BN-M03-alpha.png

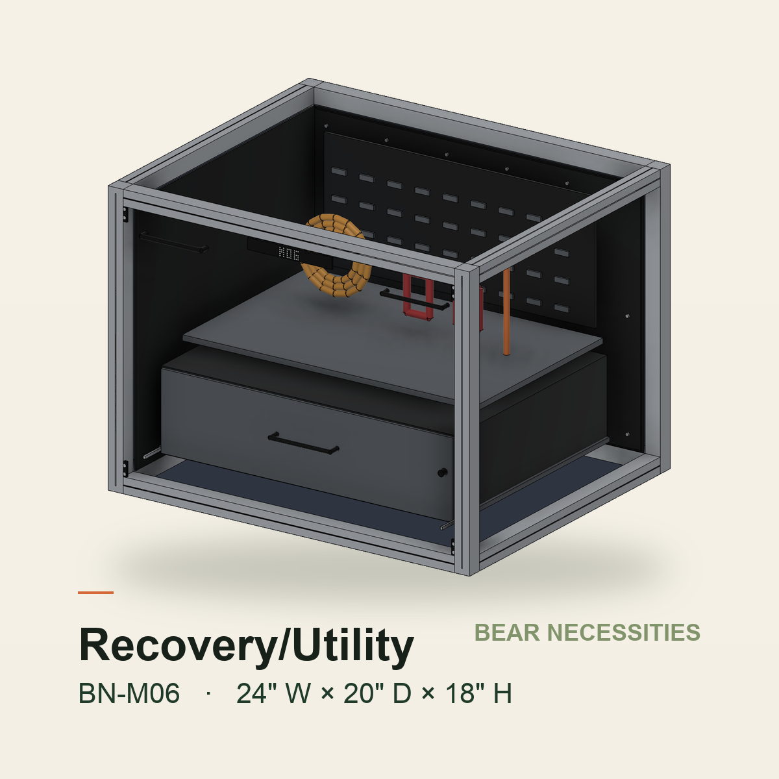
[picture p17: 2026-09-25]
Mac Mini Setup/tools/cad-product-agent/production/ten-modules/visual/renders/BN-M06-square.png

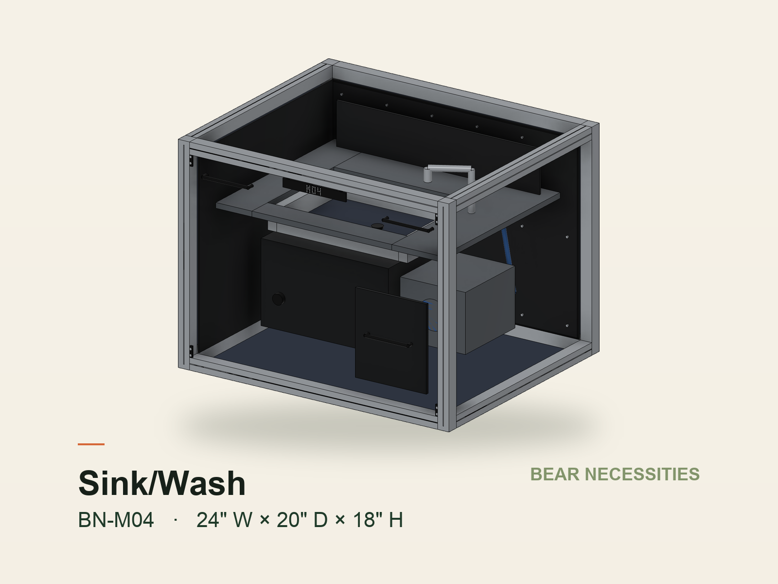
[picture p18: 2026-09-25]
Mac Mini Setup/tools/cad-product-agent/production/ten-modules/visual/renders/BN-M04-card.png

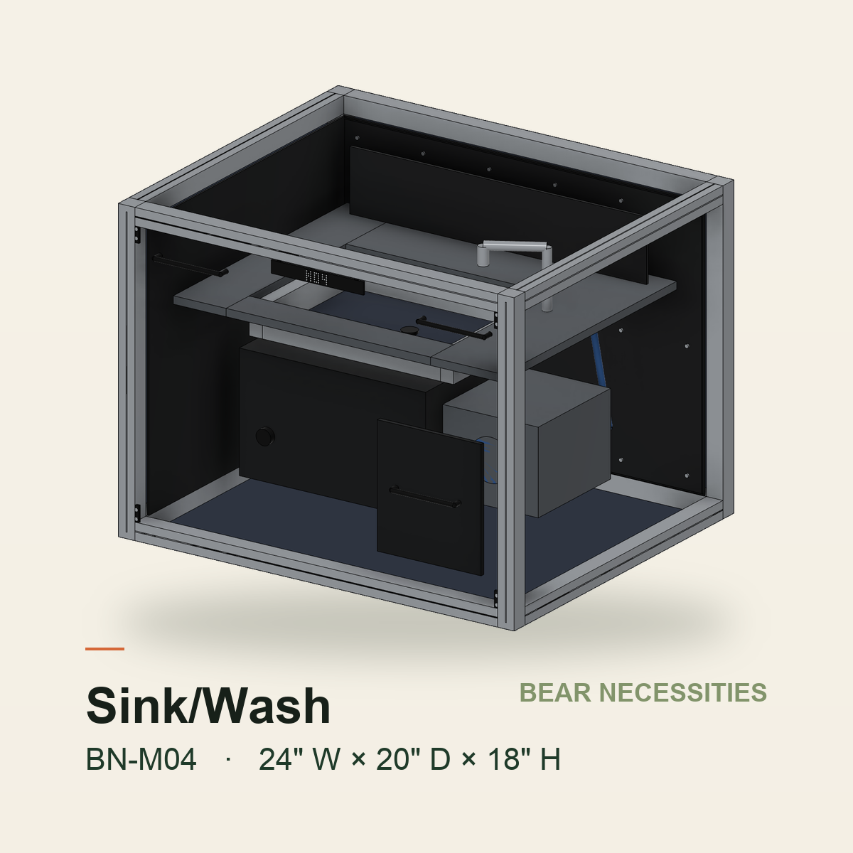
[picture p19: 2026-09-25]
Mac Mini Setup/tools/cad-product-agent/production/ten-modules/visual/renders/BN-M04-square.png

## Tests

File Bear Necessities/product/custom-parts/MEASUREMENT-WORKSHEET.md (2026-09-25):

# Vehicle Measurement Worksheet — unblocking the C-02 queue

Every vehicle job in `C-02-vehicle-queue.json` is blocked on this data. Fill one per vehicle, set that job's `status` to `READY`, add a `spec` file, then run:

```bash
python3 "../../../Fusion CAD Agent/bridge/run_queue.py"
```

## Why this is gated rather than estimated
Factory cargo tie-down spacing is **not published** for these vehicles — I checked. A model asked to guess will produce confident, wrong numbers, and the result is a bracket that does not bolt to the vehicle. Wrong hole spacing is the most expensive error available to this project, so the queue refuses to run without real measurements.

## Three ways to get the numbers, best first
1. **Measure a real vehicle.** Calipers on the anchor bolts, tape between centres. Highest confidence.
2. **OEM body repair manual / parts diagram.** Often gives anchor locations. Free via dealer parts sites for some brands.
3. **Aftermarket vendor drawings.** Companies selling drawer systems for these vehicles have already solved this. Their published mounting templates are a shortcut — check licensing before copying.

Do **not** source these from forum posts without corroboration.

---

## Worksheet — copy per vehicle

```
VEHICLE: ______________________  YEARS: __________  BODY: ________________
MEASURED BY: __________________  DATE: __________  METHOD: measured / OEM doc / vendor

ANCHOR POINTS (cargo floor)
  Number of usable anchors:        ______
  Spacing, left-right (X):         ______ in   +/- ______
  Spacing, front-back (Y):         ______ in   +/- ______
  Anchor type:   loop / D-ring / threaded boss / L-track / other: __________
  Thread size (if threaded):       __________
  Anchor protrudes above floor by: ______ in
  Load rating (if marked):         ______ lb

CARGO BAY ENVELOPE  (does a 24 x 20 x 18in module even fit?)
  Width between wheel wells:       ______ in     <-- must exceed 24.0
  Width at floor, widest:          ______ in
  Usable length, seats up:         ______ in
  Usable length, seats folded:     ______ in
  Height to window line:           ______ in     <-- must exceed 18.0
  Tailgate/liftgate opening W x H: ______ x ______ in   <-- module must pass through

FLOOR
  Flat / contoured / stepped:      __________
  Removable floor panel?           yes / no
  Anything structural underneath (tank, spare, wiring)?  __________________

NOTES / PHOTOS
  ______________________________________________________________________
```

---

## Suggested order

Do the **Subaru first** — not because it is the biggest market, but because it is the one most likely to **fail the fit check**. A 24" module between Outback wheel wells is genuinely uncertain. If it does not fit, that job leaves the queue entirely and you have saved the effort.

Then **4Runner** (highest overland volume), then **Sprinter** (may already have factory L-track and need no custom part at all).

Two of the ten could disappear on inspection. Confirm before designing.

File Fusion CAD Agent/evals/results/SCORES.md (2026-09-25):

# Eval Scores

Score 0–3 per task (see `../README.md`).
**3** runs + correct · **2** runs + wrong geometry · **1** errors but self-corrects from the traceback · **0** errors and cannot recover / hallucinates API methods

---

## qwen/qwen3.5-9b — general-purpose reasoning model (5.57 GiB loaded)
Run 2026-08-20 on M1 Pro 16GB. **Run only because the 14B coder could not be loaded** (see below). Not a coding model; included as a floor, not a fair test.

| # | Task | Score | Notes |
|---|---|---|---|
| 1 | plate (Fusion API) | **0** | 2m37s, no answer produced. Degenerate reasoning loop — emitted `Wait, createExtrude might take profile and direction and distance?` several hundred times until the token budget ran out. Output file empty. |
| C1 | plate (OpenSCAD control) | **0** | 1m54s, no answer produced. Same loop failure on a trivially easy task. |

**Verdict: unusable.** Confirms the quirk already recorded in `Mac Mini Setup/Memory.md` — this model burns its entire budget on hidden reasoning without answering.

**The control test is inconclusive.** Because it failed OpenSCAD *too*, the failure is the model, not the Fusion API specifically. The Fusion-API-vs-neutral-format question is still open and needs a competent model to answer.

---

## qwen/qwen2.5-coder-14b — BLOCKED, not yet run
Downloaded and registered (8.33 GB on disk). **Will not load on this machine as configured.**

```
Estimated GPU Memory:   10.86 GiB
Estimated Total Memory: 10.86 GiB
Error: Model loading was stopped due to insufficient system resources.
```

- The estimate is **10.86 GiB regardless of context length** (tested 3072 / 4096 / 6144 / 8192) — it is weights-dominated, so shrinking context does not help.
- Retried after unloading all other models. Still blocked.
- **The blocker is LM Studio's own resource guardrail, not the hardware.** 10.86 GiB against 16 GB total is exactly the ~70% GPU-addressable ceiling.

### To unblock (GUI only — cannot be done from the CLI)
LM Studio → **Settings → Hardware → Model Loading Guardrails** → set to **Relaxed** or **Off**, then:

```bash
lms load qwen/qwen2.5-coder-14b -c 8192 -y
```

Close other apps first. At 10.86 GiB on a 16 GB machine there is little headroom, and **Fusion cannot be open at the same time** — use the sequential workflow (generate → `lms unload --all` → run in Fusion).

---

## qwen2.5-coder-7b-instruct (MLX 4-bit, 4.00 GiB loaded, 8k ctx) — RAN
Pulled from Hugging Face (`mlx-community/Qwen2.5-Coder-7B-Instruct-4bit`) as a workaround for the blocked 14B. Loads in 8.17s, generates in ~24s/task. **A real code-specialised model, one tier below the 14B.**

### Fusion Python API
| # | Task | Score | Notes |
|---|---|---|---|
| 1 | plate | **0** | Fluent, plausible Python. Every Fusion-specific call wrong. Also a **10x unit error** — wrote `length = 100.0 # cm` for a 100 mm plate (should be 10.0), i.e. a 1-metre plate. |
| 5 | L-bracket | **0** | Same. Every feature call invented; no mm→cm conversion attempted at all. |

### OpenSCAD control — same model, same parts
| # | Task | Score | Notes |
|---|---|---|---|
| C1 | plate | **3** | `cube(size = [100, 60, 6]);` — correct, first try, no unit confusion. |
| C5 | L-bracket | **2** | Valid OpenSCAD that would render, but geometry wrong: no gusset, only one leg, holes unioned instead of subtracted. **Wrong but fixable by iteration** — a different class of failure from "won't run". |

### Verdict — this answers the open architecture question
**Generate-and-import beats direct Fusion API scripting, decisively, at this model size.**

The model writes fluent Python and simply does not know the Fusion API. Its failures there are *unrecoverable* — invented classes and method signatures, so nothing executes and there is no traceback to iterate from. In OpenSCAD its failures are *geometric* — the code runs, you see a wrong shape, and you can correct it.

Caveat: 7B is two tiers below what a 32GB mini would run, and API knowledge is exactly the kind of thing that improves with scale. This is strong evidence, not proof. Re-run both columns on the 14B (and later the 30B) before treating the Fusion-API path as closed.

Not verified: the OpenSCAD output was never rendered — OpenSCAD is not installed. Scores C1/C5 are from reading the code.

---

## Hallucinated API members seen
Populate as real runs happen. Feeds `../reference/fusion-api-notes.md`.

From qwen2.5-coder-7b-instruct. **Note it invents a *different* wrong answer each run** — `modelRoot.findItem("XY Plane")` on one task, `model.workplanes.itemByName("XY Plane")` on the next. It is not misremembering a fixed thing; it is generating plausible shapes on demand.

| Invented | Reality |
|---|---|
| `adsk.fusion.DesignManager.activeDesign` | no such class — use `adsk.fusion.Design.cast(app.activeProduct)` |
| `rootComp.modelRoot.findItem("XY Plane")` | no such member — use `rootComp.xYConstructionPlane` |
| `rootComp.model.workplanes.itemByName("XY Plane")` | no such member — same fix |
| `rootComp.features.sketchBasedFeatures.addExtrude(...)` | no such collection |
| `extrudeFeatures.add(profile, operation)` | must build a `createInput(...)` first, then `.add(input)` |
| `extrudeFeature.distance = ValueInput...` | not assignable — set extent on the input via `setDistanceExtent(False, ValueInput)` |
| `holeFeatures.add(profile, ValueInput, operation)` | wrong signature; holes need a `HoleFeatureInput` with a position |
| `context.application` | use `adsk.core.Application.get()` |
| `setDistanceExtent(ValueInput)` | needs the leading bool: `setDistanceExtent(False, ValueInput)` |

---

## qwen/qwen2.5-coder-14b (MLX 4-bit, **7.75 GiB actual**, 8k ctx) — RAN 2026-08-20
Unblocked by setting `modelLoadingGuardrails.mode` to `off` in `~/.lmstudio/apps/bionic/settings.json`.

**The guardrail was wrong.** It refused based on a **10.86 GiB estimate**; the model actually loads at **7.75 GiB** — a ~3 GiB over-estimate on a machine where 3 GiB is the difference between "works" and "blocked."

| # | Task | Score | Notes |
|---|---|---|---|
| 1 | plate (Fusion API) | **1** | Two bugs, both traceback-recoverable: `sketch.sketchLines` (needs `sketch.sketchCurves.sketchLines`) and a diagonal first line `(0,0)→(L,W)` that never closes the rectangle. |
| C5 | L-bracket (OpenSCAD) | **2** | Named variables as instructed, but **no `difference()`** — holes unioned instead of subtracted, same bug the 7B made. Legs do not form a proper L. |

### What the 14B got RIGHT that the 7B invented
- `adsk.core.Application.get()` · `app.activeProduct` · `rootComp.xYConstructionPlane`
- `extrudes.createInput(profile, operation)` → `setDistanceExtent(False, distance)` → `extrudes.add(input)` — **including the leading bool** the 7B omitted
- **Units.** `LENGTH = 10.0  # 100 mm`, `HEIGHT = 0.6  # 6 mm`. Correct mm→cm throughout. The 7B wrote `100.0 # cm` — a 1-metre plate.

Zero hallucinated API members. Every call above is real.

## REVISED VERDICT — the 7B result did not generalise

| | Fusion API | OpenSCAD |
|---|---|---|
| 7B | 0 | 3 / 2 |
| 14B | **1** | **2** |

**Fusion API improved sharply with scale (0 → 1, now two small bugs from working). OpenSCAD did not improve at all (2 → 2, identical union-instead-of-difference bug).**

The earlier "generate-and-import wins" conclusion was an artefact of testing at 7B, where the model simply did not know the Fusion API. At 14B that knowledge is largely there, and the remaining failure — **3D spatial reasoning** — hits *both* formats equally, so switching formats does not buy you anything.

**Do not abandon the Fusion API path.** The bottleneck moved from "doesn't know the API" to "can't reason about 3D space," and only the first of those is fixed by changing output format. Re-test at 30B on the mini, where the spatial reasoning should also improve.

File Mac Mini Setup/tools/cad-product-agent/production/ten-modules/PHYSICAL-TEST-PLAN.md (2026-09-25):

# Prototype physical acceptance plan

This is a verification plan, not a structural certification. Load magnitudes
remain blank until Conor approves intended payload and vehicle deceleration cases.

## Stage 0 — incoming inspection

Record supplier, PO, lot/date, packaging condition and calibrated measurement tool.

- Measure all 8 × 18-inch and 4 × 22-inch pieces at three temperatures/locations.
- Record length, squareness, burrs, twist, bow, anodize scratches and slot damage.
- Verify profile, alloy/finish declaration and every hardware part number/count.
- Reject mixed unlabeled hardware, unapproved substitutions and sharp edges.
- Archive photos and measurements under the job revision.

Acceptance values requiring approval:

- Cut-length tolerance: supplier quote or tighter drawing requirement: ______
- End squareness: ______
- Maximum cosmetic defect: ______
- Maximum bow/twist: ______

## Stage 1 — common empty frame

- Assemble to documented sequence and torque; record tool and final torque.
- Measure outside W/D/H, both diagonals on all six faces, and empty mass.
- Confirm every module remains within 24 × 20 × 18 inches including handles/feet.
- Carry through handles for 100 cycles at approved test load.
- Disassemble/reassemble three times and remeasure geometry and torque retention.
- Inspect for slot damage, bracket slip, fastener loosening and permanent set.

## Stage 2 — static proof load

Required inputs before test: rated payload `P`, vertical dynamic factor `Dv`,
longitudinal factor `Dl`, lateral factor `Dt`, and target safety factor `SF`.

- Uniform floor load: `P × Dv × SF` for the approved duration.
- Handle/lift test: frame plus `P`, independently at each intended lift orientation.
- Forward, rearward and lateral restraint proof loads: `P × D × SF`.
- Record displacement under load, residual displacement, joint slip and damage.
- Stop immediately for audible cracking, progressive slip, sharp deformation or
  unsafe fixture behavior.

The fixture and load application must be reviewed before testing. Never place a
person in the load path.

## Stage 3 — transport vibration and retention

- Install in the representative vehicle using the production-intent anchor system.
- Instrument/mark every joint and fastener; use witness marks.
- Run the approved road/vibration profile with representative payload and center
  of gravity, then repeat dimensional/torque inspection.
- Verify locking pins cannot release, module cannot migrate, and adjacent modules
  cannot collide or abrade wiring/plumbing.

## Stage 4 — module-specific tests

| Module | Required evidence |
|---|---|
| BN-M01 Cook | Transported propane separation; outdoor deployment; hot-surface clearance; stability; extinguishing/emergency procedure |
| BN-M02 Pantry | Actual container fit and lid access; packaged-food statement; latch retention; spill cleanup |
| BN-M03 Fridge | Authorized in-stock unit; slide-out/lid access; compressor ventilation; fused 12V wiring; incline/vibration behavior |
| BN-M04 Sink | Exact sink cutout; potable components; leak/pressure/drain test; grey-water containment; freeze drainage |
| BN-M05 Water | Full 7-gallon mass restraint; spill tray; pump current/fuse; potable sanitation; leak and slosh test |
| BN-M06 Utility | Actual box fit; declared payload; recovery-item restraint; sharp/heavy-object containment |
| BN-M07 Power | Manufacturer clearances; port access; thermal run at maximum intended load/charge; cable strain/fuse/fire labeling |
| BN-M08 Hot water | Transport-only orientation; outdoor-only interlock/label; wet-hose drying; propane separation; leak test |
| BN-M09 Office | Pelican 1485 configuration fit; retention; worktop proof load; hinge/cable stops; electronics ventilation |
| BN-M10 Soft goods | Selected chair/table fit; net/strap ratings; compression retention; no loose-projectile condition |

## Stage 5 — usability and fulfillment

- Two representative users install, lock, unlock, remove and deploy every module.
- Record pinch points, lift posture, time, instructions failures and loose parts.
- Perform one complete supplier-to-customer shipment and inspect damage/missing items.
- Confirm serial/revision traceability and that the customer can identify every part.

## Pass record

Every test record requires job ID/revision, date, operator, equipment/calibration,
input values, raw measurements, photos/video links, deviations, pass/fail and
reviewer signature. A summary without raw evidence is not a release record.

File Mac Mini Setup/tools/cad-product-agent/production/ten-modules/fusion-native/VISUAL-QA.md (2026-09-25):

# Final visual QA — ten native Fusion modules

Date: 2026-08-25

## Result

**PASS for website concept presentation: 10/10 modules.** Each module is a
separate native multi-component Fusion archive with a colored OBJ/MTL companion
and transparent 1600×1200 isometric/front images. This is a visual/product-
concept pass, not fabrication or engineering release.

## Comparable-product check

The visible design bar was derived from current products rather than the earlier
box envelopes:

- [Overland Kitchen EX1 fridge cabinet](https://www.overlandkitchen.com/shop/p/refridgerator-cabinet-dwwzw): enclosing cabinet, locking slide, vents, service access, restraints.
- [Goose Gear CampKitchen](https://www.goose-gear.com/products/campkitchen-2-2-30-deep-module): independently operable stove/fridge slides.
- [OVS Mid-Size Camp Kitchen](https://overlandvehiclesystems.com/mid-size-cargo-box-kitchen): distinct cooking, prep and sink layers, removable basin, wind guard, restraints.
- [Lone Peak Junk Drawer](https://www.lonepeakoverland.com/a/docs/product-guides/junk-drawer-system) and [AT Overland double drawer](https://atoverland.com/products/double-drawer-module-20-3-16-wide-x-28-depth-1): finished drawer fronts, guides, handles and latches.
- [MODULR fridge slide](https://modulroverland.com/products/modular-fridge-slide) and [OVS MOLLE panel](https://overlandvehiclesystems.com/Ruff-Rax-Inside-Molle-Panel---Universal): full-extension mounting and visible organization patterns.
- [Tailgate Gear kitchen](https://www.tailgategear.eu/products/kitchen-module): profile frame, panels, faucet/pump/basin plumbing, lockable sliders and gas restraint.

## Direct visual inspection

| Module | Customer-visible completion evidence | Result |
|---|---|---|
| BN-M01 Cook | twin detailed burners/grates, knobs, wind guard, slide tray, prep shelf, handled/latching drawer | PASS |
| BN-M02 Pantry | three graduated drawers, handles/latches/slides, partially open divided upper tray | PASS |
| BN-M03 Fridge | top-opening lid/seam, handle, orange restraints, vent array, drain and low slide tray | PASS |
| BN-M04 Sink | true open/recessed basin and drain, faucet, splash, grey tank, pump/hose and service door | PASS |
| BN-M05 Water | blue ribbed tank, cap/spigot, restraints, exposed pump face, blue hose/outlet and vent panel | PASS |
| BN-M06 Recovery | sealed drawer, shelf, MOLLE pattern, coiled rope, shackles and tool silhouette | PASS |
| BN-M07 Power | screen/status bars, AC/DC/USB geometry, vent slots, cable drawer and pass-through | PASS |
| BN-M08 Shower | heater display/knobs/vents, blue coil, exposed silver wand, red/blue connectors and wet tray | PASS |
| BN-M09 Office | deployed desk and open laptop, ribbed/latching camera case, slides, accessory drawer and blue pass-through | PASS |
| BN-M10 Furniture | folded chair/table forms, three colored rolls, contrasting compression straps, buckles and diamond cargo net | PASS |

Every module also shows twelve silver extrusion members, dark T-slot centerlines,
charcoal infill panels, front corner hardware, and a native geometric M01–M10
badge.

## Independent evidence

1. `exports/native-validation-report.json`: PASS; ten distinct F3D hashes, exact
   member count, 95–178 named components per module, required visible-part names,
   material-capable OBJ/MTL, all companion files, image dimensions, and
   24×20×18-inch frame envelope within 0.01 inch.
2. Direct inspection above: PASS after three repair rounds for camera direction,
   hidden sink/pantry mechanisms, badges, shower controls, water service, and
   field-office case access.
3. `exports/local-vlm-visual-review.json`: PASS, 10/10 current image hashes,
   zero flagged modules, zero blocking findings and zero warnings.

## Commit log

2026-09-25 Import Bear Necessities product, CAD agent and ten-module study
    Copied as-is from claude-workspace (tracked files only), keeping the
    sibling-folder layout that Bear Necessities/cad/build.sh discovers:
    Bear Necessities/, Fusion CAD Agent/, Mac Mini Setup/tools/cad-product-agent/
    and Mac Mini Setup/Setup-Checklist.md.
    Claude-Session: https://claude.ai/code/session_01SCJzAebzVQhEwztSZ1hPXQ
    [BN-FRAME-base-authored.step, BN-FRAME-base.step, BN-FRAME-base.stl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]
2026-09-25 Run the CAD build in Claude Code on the web
    - bncad: add a Linux sandbox backend (bubblewrap) beside macOS sandbox-exec.
    Same guarantee: read-only filesystem, writable run dir, no network, and
    still no unconfined fallback. doctor reports the platform's tool.
    - The CPU-limit test launches through the real backend instead of a
    hard-coded sandbox-exec command, which passed vacuously off macOS.
    - SessionStart hook installs bubblewrap and builds the CadQuery venv with uv.
    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
2026-09-25 Add cloud-model.sh: an Ollama model server for 'parts' in the cloud
    The cloud container has no LM Studio. cloud-model.sh installs Ollama
    from its GitHub release (allowed by the default network policy), starts
    it with a 16K context so bncad's prompt plus a repair round is never
    silently truncated, pulls a coder model, and prints the build command.
    It is idempotent, and when the network policy blocks the model download
    it names the hosts to allow.
    Also fix preflight crashing on a live Ollama with nothing pulled: it
    answers {"data": null}, and .get("data", []) returned None.
    Claude-Session: https://claude.ai/code/session_01SCJzAebzVQhEwz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
2026-10-17 Connect Claude to Fusion over MCP, with a research-backed CAD procedure
    Desktop Fusion's MCP server listens only on the Mac's 127.0.0.1 and its port
    moves, so Claude reaches it through a stdio proxy registered in .mcp.json as
    fusion-desktop (Fusion CAD Agent/bridge/fusion_mcp_proxy.py). The proxy:
    - rediscovers the port and re-handshakes after a relaunch, but resends a call
    only when it provably never ran; a write that got no reply is never resent
    - refuses modal dialogs and document closes, which block Fusion's API until a
    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
2026-10-18 Add build123d-mcp to .mcp.json: a headless CAD kernel for sessions without Fusion
    Registers build123d-mcp (Apache-2.0) as the `build123d` MCP server, launched
    with `uv tool run --python 3.12 build123d-mcp==0.3.91`. It gives Claude 48
    tools on an OpenCascade kernel - build, measure, fit/clearance comparison,
    validity gate, render, STEP/STL/DXF export - with no GUI, so cloud sessions
    can model and check geometry where desktop Fusion is out of reach.
    - Pinned to an exact version rather than @latest, so an upstream release
    cannot change what the tools do between sessions; a test enforces the pin.
    - Its first launch downloads ~100 packages (about 22 s here, close to Claude
    Code's MCP startup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
2026-10-18 Add the frame's two 1010-S rails: parametric build123d script and STEP files
    The frame is built from exactly two members: 80/20 1010-S cut to 18 in (x8)
    and 22 in (x4). Fusion CAD Agent/ots/1010-S now holds both as STEP files in
    real millimetres, the script that rebuilds them, a profile picture and a
    README saying which dimensions are published and which are assumed.
    - build_rail.py (uv inline script, build123d 0.13): profile from 80/20's
    callouts (1.000 in square, ø0.205 bore, 0.256 slot opening, 0.323 slot
    depth); lip thickness and cavity width assumed at typical 10-series values
    with 45-degree cavity walls; one dimension solved so the section area equals
    80/20's 0.437 in^2. Ix t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
